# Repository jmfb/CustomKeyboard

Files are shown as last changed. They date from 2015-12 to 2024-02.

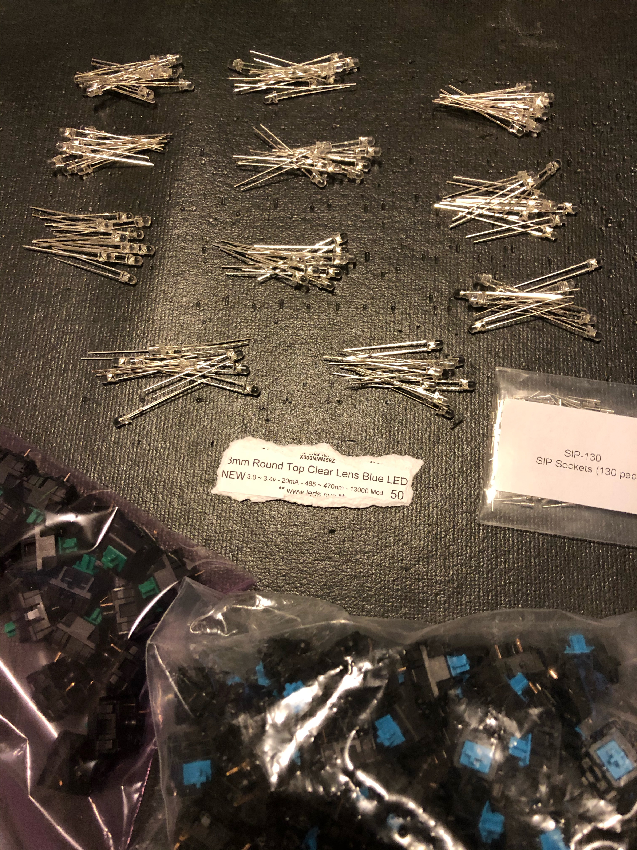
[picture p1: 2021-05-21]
Images/V5/01_LedSipKeys/00_Materials.jpeg

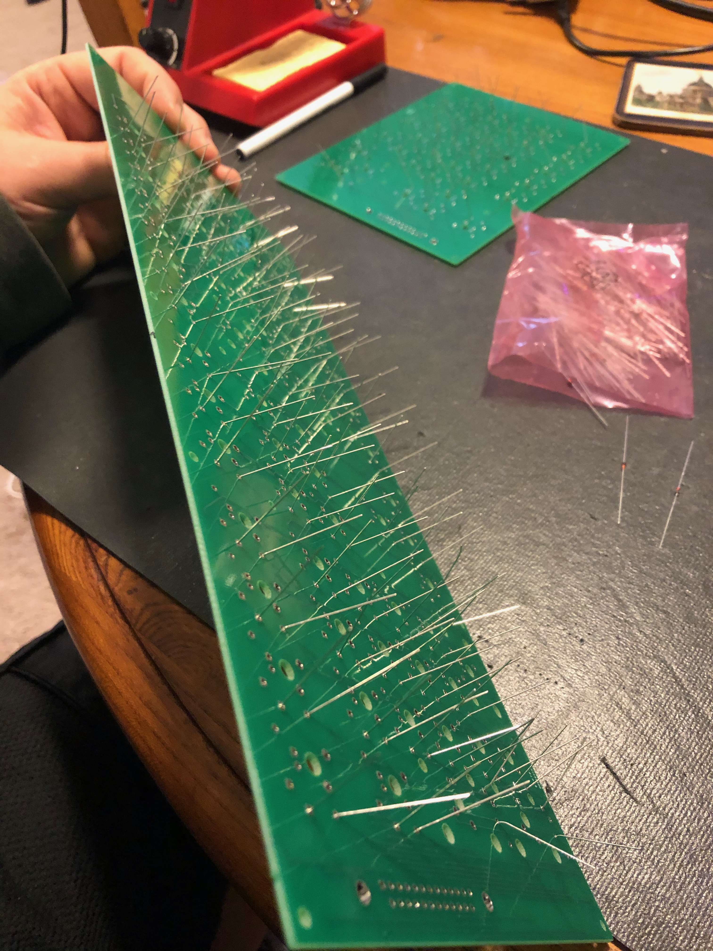
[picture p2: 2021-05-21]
Images/V5/02_DiodesAndResistors/04_RightHandBack.jpeg

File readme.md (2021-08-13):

# Custom Keyboards

## V1

I took a prefabricated tenkeyless PCB and used a dremel to cut it into 3 pieces:
- Left hand board (jagged cut at F5, 6, T, G, B)
- Right hand board (jagged cut at F6, 7, Y, H, N)
- Arrow keys

I proceeded to use the dremel to sever all PCB traces for the keys but left the diode traces.
Cherry MX brown switches were then directly mounted to the PCB.  Note that these switches were
the ones designed to be plate mounted (did not include the extra two plastic pegs for direct PCB mounting) so the keys ended up looking crooked.

The switches were then wired into the standard row/column matrix and wires were all routed through to an external Teensy2.0 controller.  2x5 and 2x3 headers were used for the connecting cables.  The keycaps were a standard profile blank set.

The next phase was designing a custom PCB for the number pad (to "complete" the full keyboard) and testing out both 3D printed and lasercut mounting plates.

### Lessons Learned

- Direct PCB mounting was crooked (at least using the non-PCB mount keys).
- Lasercut acrylic mounting plates were sturdier, cheaper, and looked cooler than the 3D printed versions.
- Arrow keys and number pad could be combined into a single board.
- Blank keycaps were difficult to use (I guess I still occasionally look).
- The placement of the right hand spacebar required the right thumb to tuck.
- The external controller for the Teensy and the external cable management boards made for too many components.
- The keys come with holes for LEDs that I might as well be using.
- A wristpad was necessary to use the keyboard and would nice if it were affixed.

## V2

I designed 3 custom PCBs using KiCad:
- Left hand board (capslock key replaced with Teensy2.0 controller)
- Right hand board
- Accessory board (arrows and numbpad)

I designed lasercut mounting plates using OpenSCAD.

I upgraded to using Cherry MX blue switches and double shot DCS keycaps and installed green LEDs on each key.

I extended the base plate to make room to glue wristpads onto the boards.

### Lessons Learned

- Direct soldering of the LEDs to the PCB made it difficult to replace them when they loosened or burned out.
- The double shot keycaps felt great but didn't allow for the LED light to show through.  Translucent keycaps would have been better.
- A better solution than just gluing the PCB to a board would be needed for a case (someting that could be assembled/disassembled, and that had walls).

## V3

This design used the same PCBs and mounting plates as V2.

Cherry MX green switches were used.  After using a sampler board with several types of switches I thought the ultra stiff key would be awesome.

Lasercut faceplates, lasercut baseplates, and 3D printed case walls were designed using OpenSCAD.  Three versions of the case walls were printed to test out different materials and different 3D printing vendors: i.Materialise, Sculpteo, and Shapeways.

SIP LED sockets were put into each of the key switches to allow for the LEDs to be replaced.  A mix of blue and green LEDs were used (blue for control keys).

Doubleshot translucent keycaps were used to allow for the LED light to show through.

The controller logic was updated to make the left hand space be a hyper key.

### Lessons Learned

- The 3D walls designed for the case were too tight of a fit and bowed out.  It made for a sturdy design but required too precise measurements for a perfect fit.  The next case should use screws/standoffs to mount the PCB vs. grooved walls.
- 3D printing was too expensive and slow compared to laser cutting.  The next case should be made solely from lasercut parts.
- The hyper key functionality was great, but I occassionally missed having the left hand spacebar.  More keys next time.
- The 2x5/2x3 connector cables looked unprofessional (probably because of the rainbow colored cables).
- I measured the baseplates based on the previous wristpad size and when I couldn't reorder the same type of wristpad had to use bigger ones that hung over the edge of the baseplates.  Obtain wristpads prior to measuring baseplates.
- The cutoff edge of the wristpads looked unprofessional.
- After double checking the PCB and laser cutting capabilities there is no need to keep the accessory board separate.
- Stabilizers for the 2+ keys would be nice.  Need to update PCB for holes, mounting plates for holes, and move PCB components in the way of the footprints.
- Not sure how I feel about the green switches.  I like the stiff feel but I don't think I love them like I did the blues.
- The LEDs were mounted on the bottom of the keys but the translucent keycaps were designed to shine through the top.  Will need to flip key switches to optimize translucent effects of the keycaps.  Note that vertical keys should have LEDs to the left.
- The key spacing for larger unit keys (1.25, 1.5, 1.75, 2, 2.25, and 2.75) had been using measured positions and worked.  However, when attempting to make a perfect rectangle for each hand it was discovered that 19mm * keysize was needed to prevent 1mm error for several rows.  This increased resolution for key spacing to 1/8th mm from 1/2 mm.

## V4

3 new PCBs were designed using KiCad:
- Extended left hand board (include arrow keys and slightly inverted numpad to mirror right hand board).
- Extended right hand board (combined right hand board and accessory board).
- External connector board (houses Teensy and 2 25-pin D-sub connectors).

The left hand board had arrow keys added to the left of the previous left edge.  A numpad was added to the left of that but with the outside edge of keys mirrored and the zero and period flipped.  The mirroring was so the enter would still be hit with the pinky and the zero still with the thumb.  The numbers were not flipped because I didn't want to retrain my brain for my left hand.  Above the numpad, four programmable buttons were added (N1-4, sometimes used for volume controls or extended operators for the numpad).  To the left of the numpad a vertical row of programmable buttons was added (M1-6, as part of the more keys strategy) that used some of the gaps in the row/column matrix.  To the right of the jagged edge, a vertical row of programmable keys was added (L1-6) and different sized keys were used to make the board a perfect rectangle.  A new hyper key (LEFT_HYPER) was also added to the left of the spacebar to fill in the gap between alt and the spacebar.  The capslock key was re-added since the Teensy is being moved onto its own board (whether this gets remapped is programmable).  The main part of this board is 8.5 standard keys wide.

The right hand board was combined with the previous accessory board.  The same jagged gap was filled on this board to make it a perfect rectangle though one more key was added (two keys were added to the left of the function key row) for an additional 7 keys (R1-7).  A new hyper key was added to the right of the spacebar (RIGHT_HYPER) and the right windows key was re-added (previously just had the right menu key between alt and ctrl).  The same N1-4 and M1-6 keys were also added to this board (note they are not independently programmable because they map to the same row/column scan position).  The main part of this board is 10 standard keys wide.

The full keyboard contains 170 keys; 130 distinct row/column scan positions.  Note that there are still 2 unused row/scan positions in the 12x11 row/scan matrix.  There wasn't anywhere convenient left to put them though.

A single 25-pin D-sub connector exists on each board. 12 row pins, 11 column pins, VCC, and GND (for LEDs).  Instead of chaining the left board to the right board and having the USB cable and connector cable on the left board, the Teensy was moved off onto a controller board.  The controller board just maps the Teensy pins to 2 D-sub connectors (one for the left hand board and one for the right hand board, with both cables having the same pin assignments).

The case design was switched to use all lasercut pieces.  The walls are notched together and slide pegs into the baseplate and faceplate.  A 3mm overhang, 3mm wall depth, and 1mm spacing between wall and PCB makes each dimension of the base/face 14mm longer than the PCB/mounting plate sizes.  Screw holes are drilled into the border and one near the arrow keys for some center support.  M2 screws (5mm male end), 0.5mm washers, 5mm M/F standoffs (3mm wide with 4mm male end), and 8mm F/F standoffs (3mm wide) are used to affix the PCB to the base and affix the faceplate to the walls.  From the bottom, it goes: screw, base, 5mm M/F standoff, PCB, washer, 8mm F/F standoff (though hole for mounting plate), 2 washers, faceplate, washer, screw.

All case parts for all three boards can be combined into a single CAD file and lasercut from two P3 pieces from Ponoko (one for the baseplates and walls and one for the mounting plates and faceplates).  Since there was space for two connector faceplates, I decided to make one with a little bit of artwork and cut out a flux capacitor.  Because if you're going to build your own keyboard why not build one with style!

Cherry PCB mounted stabilizers were added.  Two sets of translucent keycaps were needs due to the number of additional keys.

### Lessons Learned

- D-Sub connector height measurement was imprecise and pushed the faceplate up about 1mm.  Filing it down took part of the edge off, but using a micrometer will yield better wall/faceplate height measurements.
- Using the washers on the screw/standoff connections was impractical due to the small size of the washers, the inconvenient location of the screws (near walls or central to the board and under the mounting plate).  The screw/standoff premise is solid though and made a very sturdy and professional looking case.
- The location of the D-Sub connectors on the boards was inconvenient for placement near monitors.  I think the outside edge would make the most sense for the next version.
- More keys was a bad idea.  The inner row keys ended up getting pressed by accident too often and ruined the tactile feel for finding my position on the keyboard without looking.  While there was potential for adding useful keys (left hand enter, backspace, right hand tab, escape) the opposite was experienced.  The extra left hand board made it difficult to find home for my left hand (naturally always seeking leftmost position).  The extra numpad and outer macro keys filled out the keyboard but were too out of the way to add anything useful to them (it was more burdensome to try to figure out what to assign to the keys).  I am not sure about how I feel about the hyper key near the spacebar because of the other things that made typing difficult.  I do still think a hyperkey or two is a good idea.
- The offboard teensy and extra cabling has the benefit of keeping a single cable going to each board but uncovered a problem with wiring resistance that was solved with a delay in the controller logic during rowscan to allow the signals in the lines to stabilize (which was taking at least one extra clock cycle and causing phantom keypresses in the first two columns of the scan matrix).
- I didn't glue down the wristpad on this one because I was tired of buying more and more wristpads.  However, they slip around too much otherwise.  They need to be fixed to the keyboard case.  Sewing the edge flap down did make them look much better than the glued end of cut off end.
- I think the Cherry MX Green switches were cool for a while but in the end not as nice to type on.  Going back to the blue switches from V2 felt amazingly good by comparison.
- The mix of blue and green LEDs was kind of cool but I don't love it.  I think short of RGB LEDs I will stick with a single color.  Probably green but blue was fine too.  The SIP sockets rock.
- Having the CapsLock key back was a mistake - definitely never use it and every time it is pressed was an accidental hit.  I might leave it off next time.  Would the overall look suffer though?
- The flux capacitor design in the connector board was basically invisible because of the clear faceplate.  However, the top leg did provide a hole through to the teensy reset button which came in handy.  Might just keep that hole.
- The cherry stabilizers worked out great.  Clean fit into PCB, perfect cutout for mounting plate.  There was one resistor that was close to a support bar.
- Pro-tip: prior to soldering the keys onto the PCB make sure all key pins went through.  One pin had bent down and I didn't discover it until half of the keys were soldered.  That meant I was almost fucked.  I ended up shoving a bit of wire through the hole and drenching it in solder hoping that surface tension would pull enough solder down the wire to make the connection to the bent pin.  It worked, but had it not I don't know what I would have done.
- A few more screws in certain locations would make the faceplate more stable (at least on the right hand board).

## V5

### Left Hand

- Getting rid of left hand accessory board (arrows and numpad).
- Getting rid of outside column macro keys (M1-6) and inside column macro keys (L1-6).
- Removing the caps lock key.  Could have left it for looks and mapped it to a hyper key or something, but not worth the mistakes.
- Keeping the left hyper key.
- Moving D-Sub connector to left edge at the top.
- Using a total of 7 screw holes to build case.
- Total of 35 keys (2 2+ keys) with max row width being 7.5 keys (bottom row).

### Right Hand

- Getting rid of outside column macro keys (M1-6) and inside column macro keys (R1-7).
- Keeping numpad macro keys (N1-4).
- Keeping right hyper key and right windows key.
- Moving D-Sub connector to right edge at the top.
- Using a total of 15 screw holes to build case.
- Total of 75 keys (7 2+ keys) with max row width being 9 keys (bottom row, excluding accessory keys).

### Connector Board

- Reusing design from V4.  Will be able to use the same PCB.
- Leaving a hole in the faceplate for the Teensy reset button.
- Using a total of 4 screw holes to build case.

### General Updates

- Fixing case wall height to take into account micrometer measurements for D-Sub connectors (10.3mm vs. previous measurement of 9.5mm).
- Using 10mm F/F standoffs to connect PCB to faceplate (a 0.3mm gap will exist, should be fine).
- Not using washers in any part of screw assembly (too small and can't get in most spots).
- Using same color LED for all keys (green).
- Going back to Cherry MX Blue switches.
- Plan on getting custom DCS row 6 keycaps for hyper keys (left is 1.5, right is 1.75) and space keys (both 2.25).

### Lessons Learned

- This keyboard is just plain awesome.
- Right hand board is still very large and is sometimes awkward to fit onto desk near monitors.
- Large right hand board occasionally gets wobble when crossing desk boundaries.
- Very minor use of hyper keys due to completely normal keyboard layout.
- N1-4 keys are never used (and completely out of the way).
- Uses 3 2.25 keys (left shift and both spacebars) which makes complete keycap sets difficult.
- Using unused capslock as right hyper is perfect.
- Still do not miss the capslock key (nor do I wish there were a key there I could hit).
- Single color keyboard is okay (looks neat but not awesome).  Have built both a green and blue version.
- Ran out of blue switches for second one and used green for function keys - don't even notice because of how rarely they are used.
- D-sub cables give a classic/punk look to the keyboard but are a bit large (bump into monitors still, even on the outside top).
- Cost for materials (case/PCB) is higher than ideal due to large right hand board.
- Connector board is larger than it needs to be.

## Mini V1

### Goals

- Build a miniature keyboard (40%-like) and use hyper-functionality to improve current coding workflows.
- Have an easy to hit underscore (for snake casing, lambdas, garbage identifier prefixes, etc.).
- Reduce PCB/case material costs (just in case I want two of them again!).
- Have smaller and more hidden cables connecting the boards (keep off-board controller for symmetry).
- Columnar layout (will definitely need to re-learn typing).
- Minimal "reach" keys (1 row up, 1 row down, 1 row over to either side).
- Rely on thumb buttons for extra keys (no clue what layout yet).
- RGB LEDs so I can have that awesome feel of dynamic color and responsive changes.

### Parts, Prices, and Datasheets

- Cherry MX Blue RGB PCB Mount Switches (x23 x2)
	- MX1A-EN1B (NOTE: Only wanted MX1A-EN1A, plate mounted, but were constantly out of stock)
	- [Blue Datasheet](https://www.cherrymx.de/_Resources/Persistent/a531cb6598bc849cbcf131fd7a31814282b74545/EN_CHERRY_MX_BLUE.pdf)
	- [Footprint Datasheet](https://cdn.sparkfun.com/datasheets/Components/Switches/MX%20Series.pdf)
	- [LED Cutout Datasheet](https://drive.google.com/file/d/0B5JcED9YINdnNU1qajJmVmtEcUU/view?resourcekey=0-LZfcyjo3jcX8JEKJD6tRKA)
	- [MechanicalKeyboards](https://mechanicalkeyboards.com/shop/index.php?l=product_detail&p=4451)
	- $0.50 / switch @ 100 = $50.00 (bulk discount)
- Pin Receptacle Connector (Maybe, adds height to key and might throw off 3mm spacing between PCB and mounting plate)
	- 0305-2-15-15-47-27-10-0 (ED90333-ND)
	- [Datasheet](https://www.mill-max.com/products/datasheet/pinsrecs/0305-2-15-80-47-80-10-0)
	- [Digikey](https://www.digikey.com/en/products/detail/mill-max-manufacturing-corp/0305-2-15-15-47-27-10-0/1801940)
	- $0.22906 / connector @ 200 = $45.81 (bulk discount, went in on 500 with Greg).
- Keyswitch Diode (x23 x2)
	- 1N4148 (1N4148FS-ND)
	- [Datasheet](https://rocelec.widen.net/view/pdf/bhc41r7lwc/ONSM-S-A0003539415-1.pdf?t.download=true&u=5oefqw)
	- [Digikey](https://www.digikey.com/en/products/detail/on-semiconductor/1N4148/458603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)
	- $0.01622 / diode @ 1000 = $16.22 (bulk discount)
- RGB LED with IC (x23 x2)
	- APA102C (iPixel LED)
	- [Datasheet](https://cdn.sparkfun.com/datasheets/Components/LED/APA102C.pdf)
	- [Sparkfun](https://www.sparkfun.com/products/16345)
	- $0.379 / LED @ 50 = $18.95
- 9pin Mini-DIM Female Connector, Through Hole, Right Angle (x1 x2 + connector x2)
	- MD-90S (CP-2490-ND)
	- [Datasheet](https://www.cuidevices.com/product/resource/md-s.pdf)
	- [Digikey](https://www.digikey.com/en/products/detail/cui-devices/MD-90S/145320)
	- $2.95 / connector @ 4 = $10.80
- 9pin Mini-DIM Male/Make 3ft. Cable (x2)
	- MD9MM3BLK
	- [Datasheet](https://www.kraydad.com/mini-din-9-pin-b-type-cables/)
	- [Kraydad](https://www.kraydad.com/mini-din-9-pin-b-type-3-ft-male-to-male-black-cable/)
	- $12.49 / cable @ 2 = $24.98
- Cherry PCB Snap-in Stabilizers (2u x2 x2)
	- 60%/TKL (NOTE: includes 5 2u wires, only need 4)
	- [Amazon](https://www.amazon.com/Genuine-Cherry-PCB-Snap-Stabilizers/dp/B085T8QZJC)
	- $14.99 / pack @ 1 = $14.99
- M4 Hex Brass F/M Standoff 18mm/6mm w/ Screw and Nut (x4 x2)
	- Set of 20 (need 4 or 5 per board)
	- [Amazon](https://www.amazon.com/gp/product/B08ZXSR7MP)
	- $0.5745 / set @ 20 = $11.49
- M4 Brass Washer 9mm OD, 4.3mm ID, 0.8mm Thick (x4 x2)
	- Pack of 100 (need 4 or 5 per board)
	- [Amazon](https://www.amazon.com/gp/product/B009OK2KPU)
	- $0.0827 / washer @ 100 = $8.27
- M2 Brass F/M Standoff 5mm/4mm
	- Pack of 100 (need 4 for controller)
	- [Amazon](https://www.amazon.com/gp/product/B00REFG0TE/ref=ppx_yo_dt_b_search_asin_title?ie=UTF8&psc=1)
	- $0.0949 / standoff @ 100 = $9.49
- M2 Brass F/F Standoff 8mm (first controller)
	- Pack of 50 (need 4 for controller)
	- [Amazon](https://www.amazon.com/gp/product/B00BWLQYRY/ref=ppx_yo_dt_b_search_asin_title?ie=UTF8&psc=1)
	- $0.226 / standoff @ 50 = $11.30
- M2 Brass F/F Standoff 10mm (second controller)
	- Pack of 100 (need 4 for controller)
	- [Rakuten](https://www.rakuten.com/shop/unique-bargains/product/a14081400ux0120/)
	- $0.0683 / standoff @ 100 = $6.83
- M2 5mm Screws
	- Pack of 60 (need 8 for controller)
	- [Amazon](https://www.amazon.com/gp/product/B013T1U4LG/ref=ppx_yo_dt_b_search_asin_title?ie=UTF8&psc=1)
	- $0.1195 / screw @ 60 = $7.17
- Clear Soft Close Drawer Cabinet Door Bumpers (x6 x2 + connector x4)
	- 9.5mm x 3.8mm, 72pc sheet
	- [Amazon](https://www.amazon.com/dp/B06XCGM8JT)
	- $0.0968 / bumper @ 72 = $6.97
- Mini USB A to Mini-B Cable, Black, 3ft (x1)
	- 103896 (any Mini USB cable will do if you already have one)
	- [Amazon](https://www.amazon.com/Monoprice-3-Feet-mini-B-28AWG-103896/dp/B003L18SHC)
	- $5.23 / cable @ 1 = $5.23
- Teensy 2.0 (x1)
	- No pins
	- [Datasheet](https://www.pjrc.com/store/teensy.html)
	- [Amazon](https://www.amazon.com/gp/product/B00NC43256)
	- $18.75 / chip @ 1 = $18.75 ($16 from PJRC but with shipping)
	- NOTE: Plans to discontinue this model in 2022; recommend switching to 32-bit boards.
- Header Pins (x12 x2, though more pins available on Teensy)
	- Breakaway header, straight, brass
	- [Sparkfun](https://www.sparkfun.com/products/116)
	- $1.50 / 40pin strip @ 1 = $1.50
	- NOTE: Larger volumes and lower per-pin cost are on amazon but not brass pins
- Demultiplexer, 3:8 (x1 x2)
	- SN74HC138N (296-1575-5-ND)
	- [Datasheet](https://www.ti.com/lit/ds/scls107f/scls107f.pdf)
	- [Digikey](https://www.digikey.com/en/products/detail/texas-instruments/SN74HC138N/277221)
	- $0.461 / chip @ 10 = $4.61 (bulk discount)
- Parallel Load, Shift Register (x1 x2)
	- SN74HC165N (296-8251-5-ND)
	- [Datasheet](https://www.ti.com/lit/ds/symlink/sn74hc165.pdf)
	- [Digikey](https://www.digikey.com/en/products/detail/texas-instruments/SN74HC165N/376966)
	- $0.525 / chip @ 10 = $5.25 (bulk discount)
- 10kOhm Pullup Resistors (x8 x2)
	- CF18JT10K0 (CF18JT10K0CT-ND - Cut Tape (CT))
	- [Datasheet](https://www.seielect.com/catalog/sei-cf_cfm.pdf)
	- [Digikey](https://www.digikey.com/en/products/detail/stackpole-electronics-inc/CF18JT10K0/1741566)
	- $0.01116 / resistor @ 500 = $5.58 (bulk discount)
- Wristpad (x1 x2, but both cut from 1)
	- Glorious Gaming Write Pad, Standard Size
	- [Amazon](https://www.amazon.com/Glorious-Gaming-Wrist-Pad-Rest/dp/B00V5AXPTW)
	- $26.99 / pad @ 1 = $26.99
- Doubleshot Translucent Pudding Keycaps (x15 x2)
	- Standard Set
	- [Amazon](https://www.amazon.com/gp/product/B09241HV9H)
	- $19.99 / set @ 1 = $19.99
- DCS Clear Keycaps (x8 x2)
	- 1u R2 x2, 1u R3 x2, 1u R4 x8, 2u R3/4 x4
	- [Datasheet](https://pimpmykeyboard.com/template/images/DCSFamily.pdf)
	- [PimpMyKeyboard](https://pimpmykeyboard.com/dcs-clear-keys-and-key-sets/)
	- $1.00 / 1u @ 12 = $12.00
	- $1.50 / 2u @ 4 = $6.00
- Laser Cut Parts
	- [Ponoko](https://www.ponoko.com)
	- All 3mm parts are Green Translucent Acrylic
	- All 1.5mm parts are Clear Acrylic (not available in Green Translucent)
	- Controller (3mm) $7.69 @ 1 = $7.69
	- Base Plate (3mm) $7.15 @ 2 = $14.30
	- Mounting Plate (1.5mm) $7.71 @ 2 = $15.42
	- Lower Layer (3mm) $5.965 @ 4 = $23.86
	- Upper Layer (3mm) $6.08 @ 2 = $12.16
	- Face Plate (3mm) $3.855 @ 4 = $15.42
	- Face Plate (1.5mm) $2.815 @ 2 = $5.63
	- Multi-product discount $30.91
	- Setup Fee $14.00
	- Total: $77.57
- PCB
	- [Seeed Studio](https://www.seeedstudio.com)
	- Controller $0.98 @ 5 = $4.90
	- Left Hand $6.486 @ 5 = $32.43
	- Right Hand $6.486 @ 5 = $32.43
	- Shipping (DHL from China) $30.19
	- Total: $19.99 @ 5 = $99.95
- Total cost of parts for a single keyboard: $313.34

### Lessons Learned

- Fitting 5x5mm LEDs not a perfect fit (could have made a tad wider for flush fit; would also fit rounded PCB cut corner issue too)
- Soldering LEDs difficult.  Not sure what to do about this other than magnifying glass w/ light.
- Chaining VCC/GND may have been a poor choice, still not sure.  Definitely problematic when attempting to remove an LED.
- Socketing switches seems like a good idea (reduce switch cost for multiple prototypes, allow replacing switches in long-lived versions).  However, increases distance between mounting plate and PCB by ~1mm.  I think I can take that out on pegs.
- With the surface mount pegs, the mounting plate does seem a little bit redundant.  Eliminating the mounting plate and the 1.5mm faceplate layer would reduce overall height by 3mm (shorter M4 scews) and allow for a completely 3mm layer construction.
- Controller board; teensy height from PCB is slightly greater than the 8mm F/F standoffs (not sure how I missed that).  Damn, old controller used 10mm F/F standoff.
- Well, it puts the previous lessons to shame, but the controller "lid" didn't go deep enough with the connector cutouts!  Missed "PCB spacing, wall depth, overhang" padding and just did connector size.
- Tab being lower for the pinky takes getting used to (hit escape a lot).
- Only using bottom half of 2-keys.  Possibly simplify down to 1u size?
- Sometimes hit Win instead of Ctrl when reaching with thumb.  Could stagger keys for thumb; possibly get rid of one of grid keys and just have left hand Win and right hand Menu (or no Menu, I mean who uses that key?)
- Had a few iterations of controller software.  Unit tests for expected key reports were vital (lots of bugs found that way and prevent breaking changes in the future).

## Mini V2

### Goals

- Fix LED hole size to make assembly and soldering easier.
	- Move cutout to keyswitch footprint (manually in file if IDE does not support it).
	- Increase width of cutout to allow surface mount leads to fit inside PCB.
	- Also increase width of peg cutout to account for rounded PCB cutout.
- Fix all incorrect case measurements.
	- 10mm standoffs for controller top.
	- Fix controller lid cutouts for connectors.
	- Reduce peg inner height by 1mm to account for keyswitch sockets.
	- Adjust connector cutout (rubs on bottom).
	- Add holes for demux and register to mounting plate.
- Add hardware support for right or left hand detection.
	- Hardwire first two register pins to 01 for left and 10 for right.  11 indicates disconnected.
	- Software detection to read keyscan and switch LED output.

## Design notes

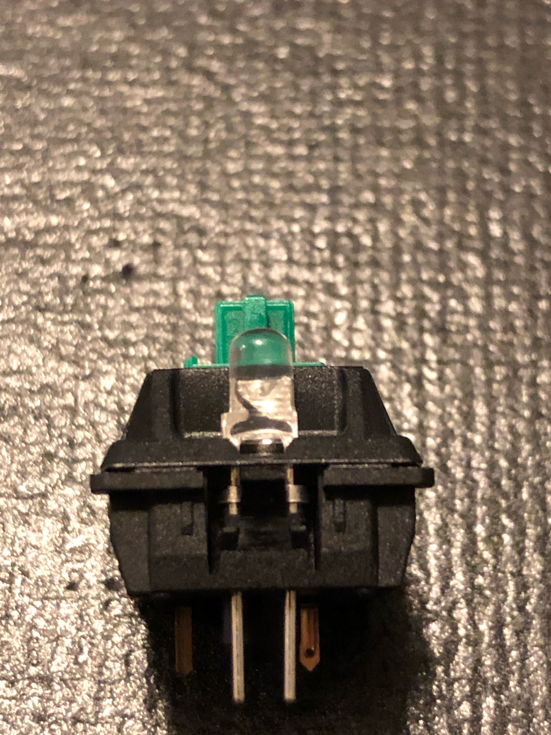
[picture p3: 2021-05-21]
Images/V5/01_LedSipKeys/07_InsertLed.jpeg

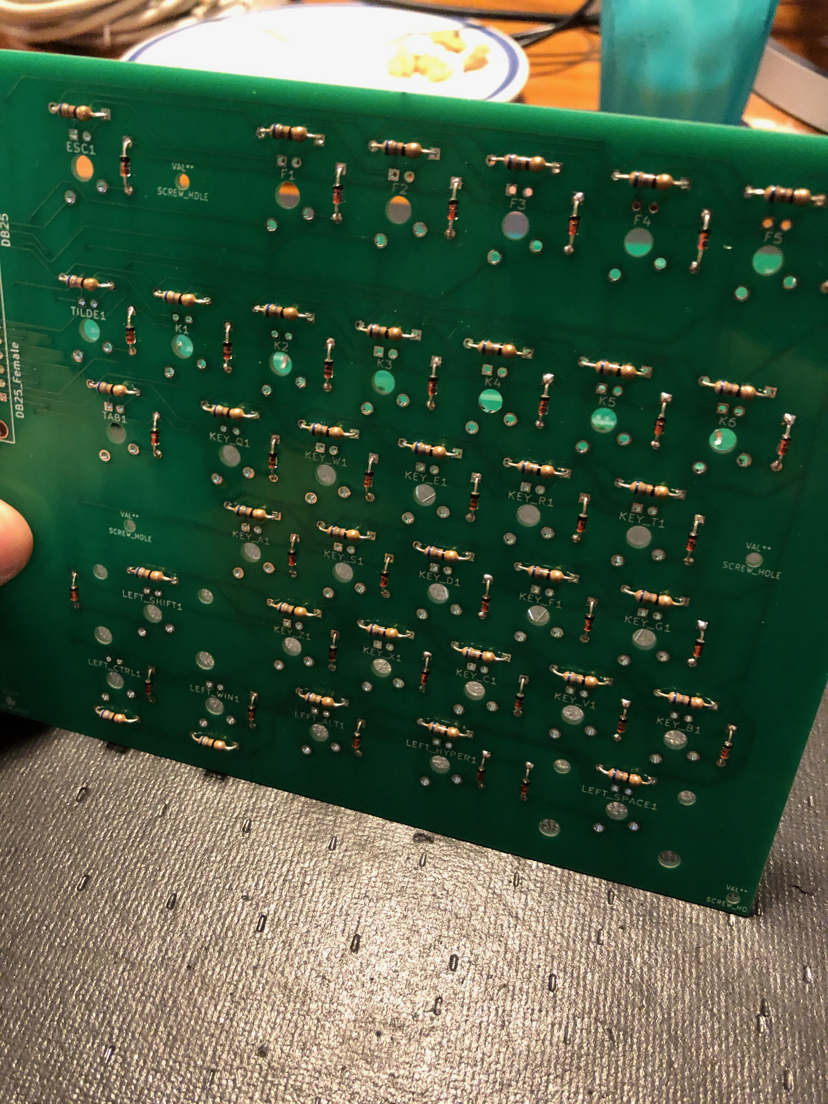
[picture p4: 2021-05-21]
Images/V5/02_DiodesAndResistors/05_LeftHandResistors.jpeg

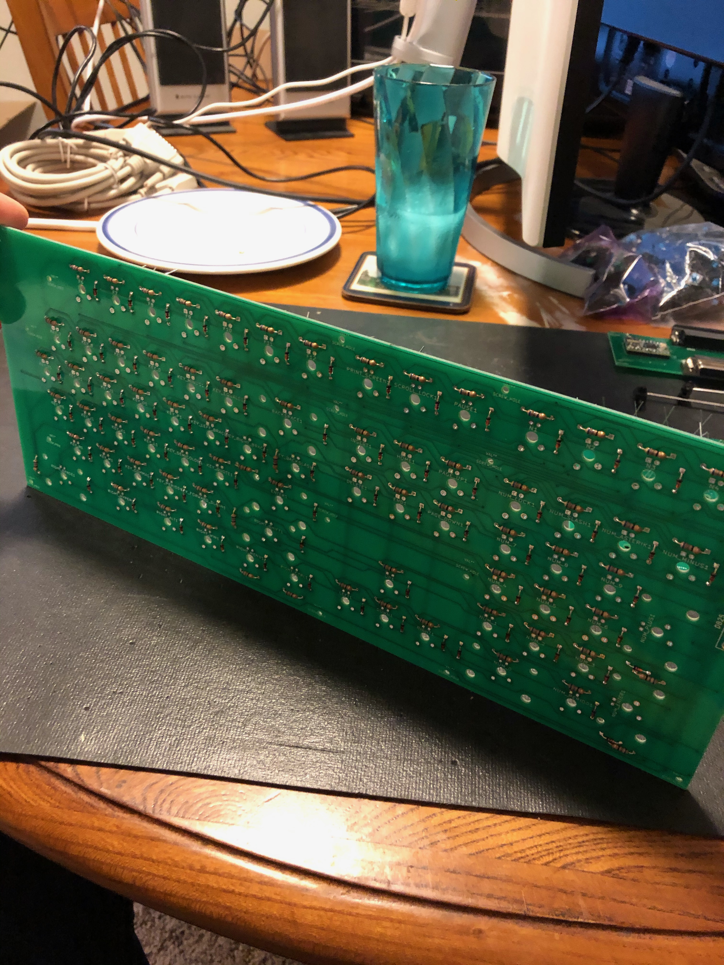
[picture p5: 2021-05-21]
Images/V5/02_DiodesAndResistors/07_RightHandResistors.jpeg

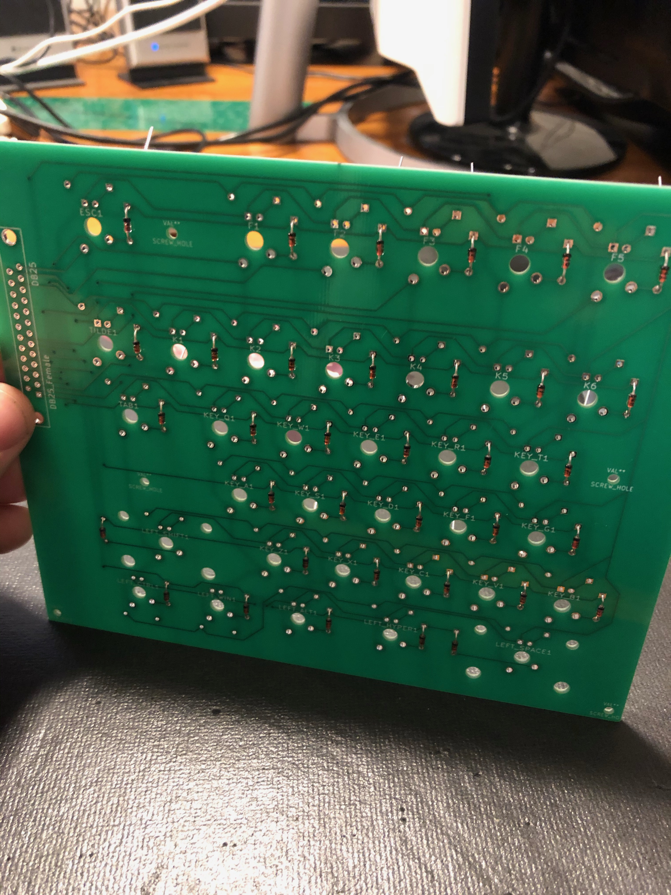
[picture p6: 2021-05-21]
Images/V5/02_DiodesAndResistors/01_LeftHandDiodes.jpeg

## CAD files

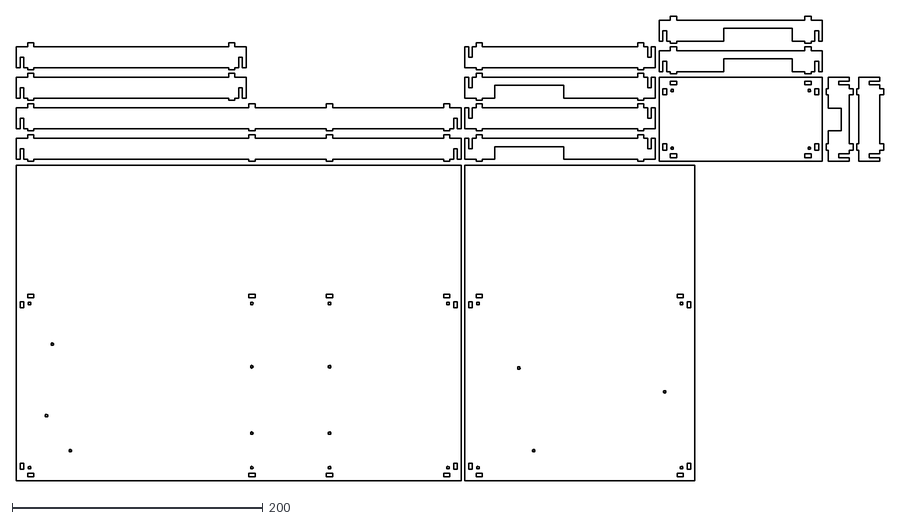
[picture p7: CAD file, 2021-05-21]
BasePlates/V5.dxf
692.3 x 370.8

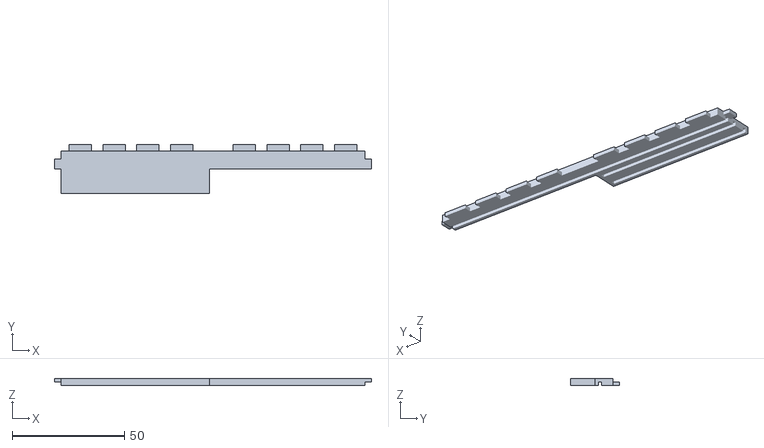
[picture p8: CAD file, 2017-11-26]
Case/RightHandAndAccessoryLeft.stl
141.0 x 22.0 x 3.00

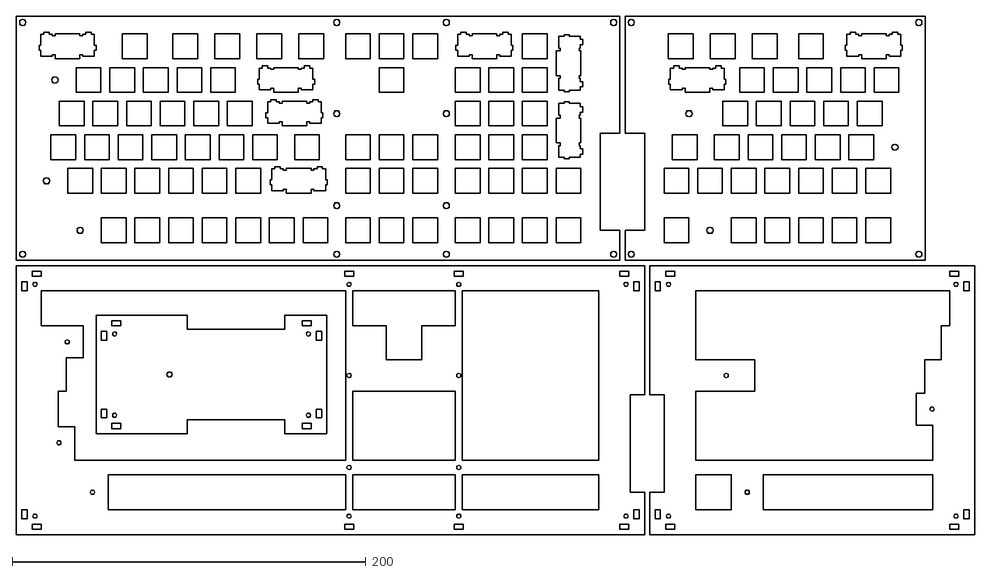
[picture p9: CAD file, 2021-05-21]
FacePlates/V5.dxf
541.5 x 293.0

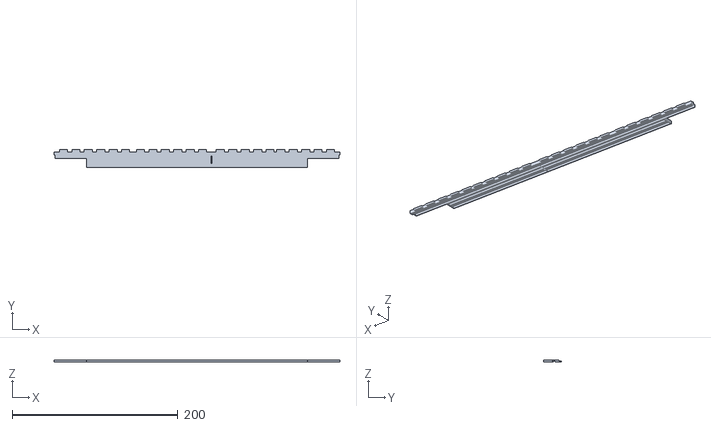
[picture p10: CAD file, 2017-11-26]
Case/RightHandAndAccessoryTop.stl
345.5 x 22.0 x 3.00

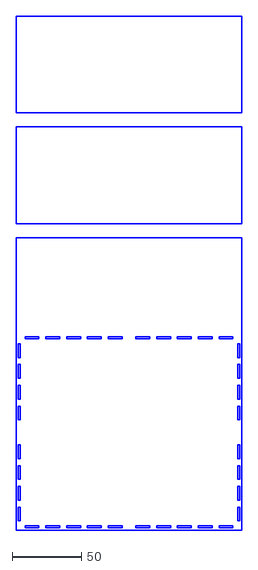
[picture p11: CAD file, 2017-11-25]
BasePlates/LeftHand.v2.dxf
163.0 x 371.0

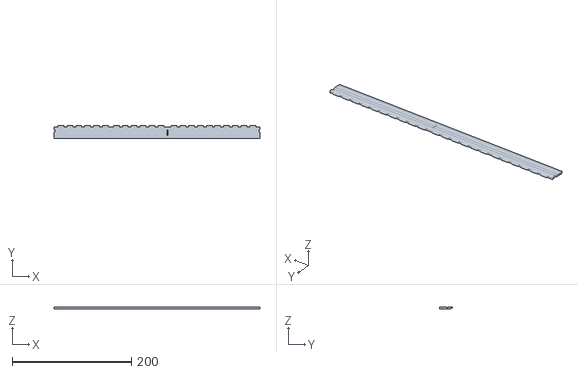
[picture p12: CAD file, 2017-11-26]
Case/RightHandAndAccessoryBottom.stl
345.5 x 22.0 x 3.00

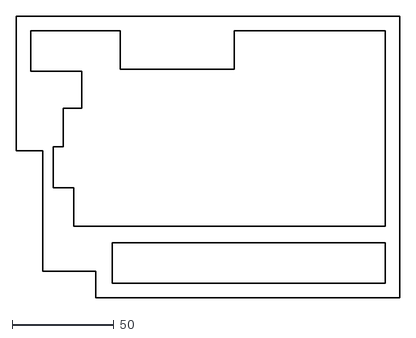
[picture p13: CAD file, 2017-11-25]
FacePlates/RightHand.dxf
188.0 x 138.0

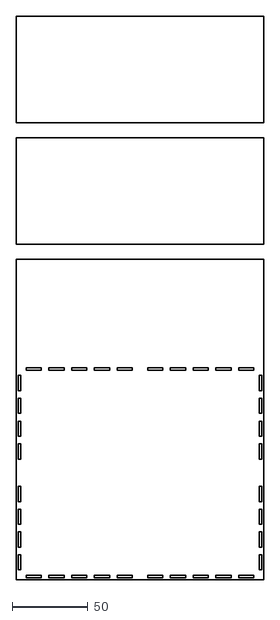
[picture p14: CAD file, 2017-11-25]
BasePlates/LeftHand.dxf
163.0 x 371.0

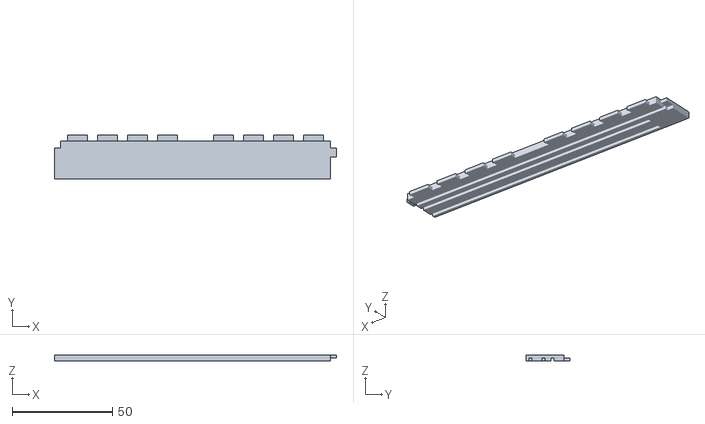
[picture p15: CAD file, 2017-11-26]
Case/RightHandAndAccessoryRight.stl
141.0 x 22.0 x 3.00

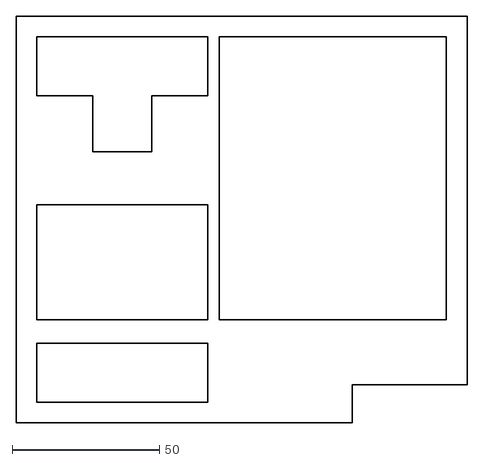
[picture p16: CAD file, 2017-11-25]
FacePlates/Accessory.dxf
153.0 x 138.0

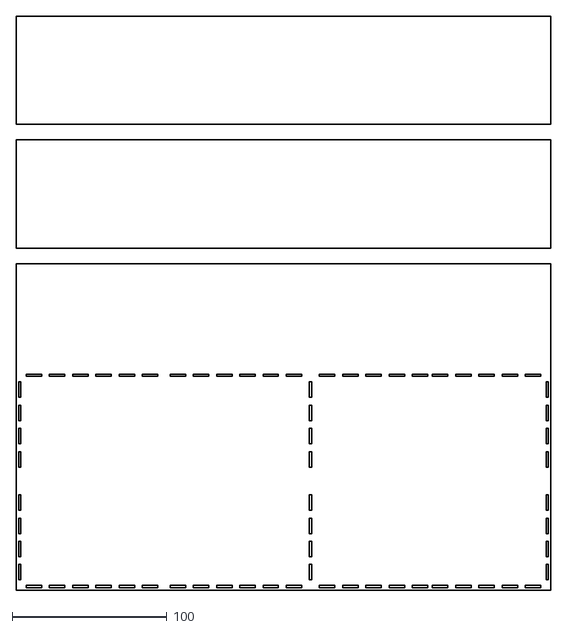
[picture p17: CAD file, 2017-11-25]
BasePlates/RightHandAndAccessory.dxf
345.5 x 371.0

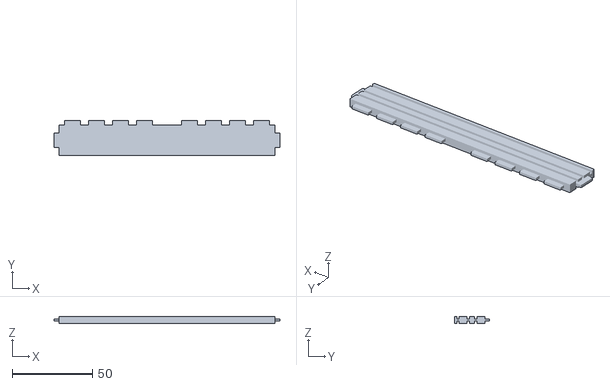
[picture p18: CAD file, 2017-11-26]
Case/RightHandAndAccessoryMiddle.stl
141.0 x 22.0 x 4.50

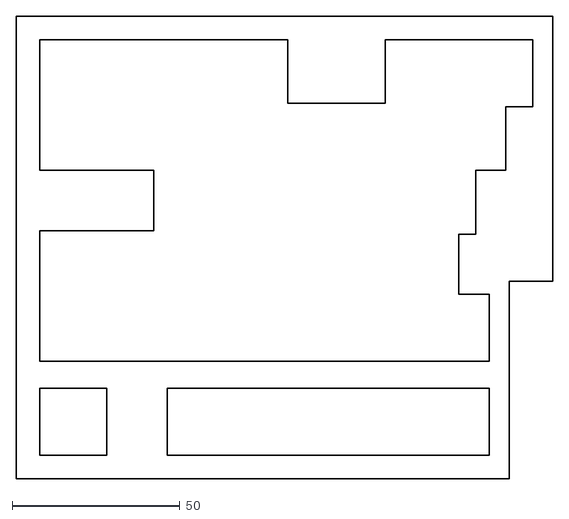
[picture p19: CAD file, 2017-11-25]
FacePlates/LeftHand.dxf
160.0 x 138.0

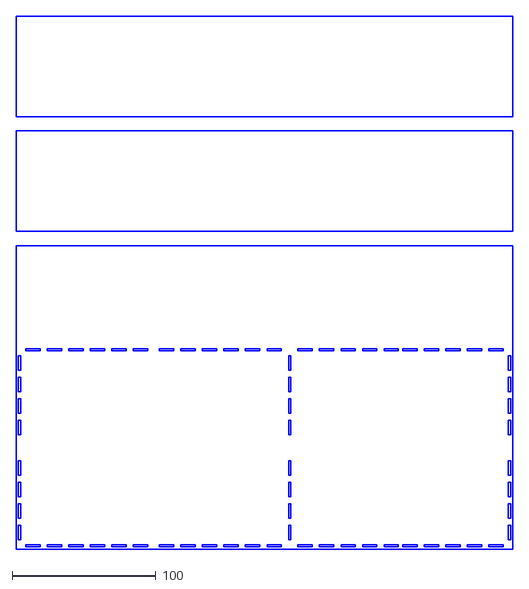
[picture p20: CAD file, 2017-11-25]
BasePlates/RightHandAndAccessory.v2.dxf
345.5 x 371.0

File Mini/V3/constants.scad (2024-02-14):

keySize = 19;				// Size of a keyswitch (a perfect square)
halfKeySize = keySize / 2;	// Distance from center of keyswitch to each side
keyHoleSize = 14;			// Size of a keyswitch mounting hole (a perfect square)
epsilon = 0.1;				// Small value used to get around OpenScad difference issues

pcbDepth = 1.6;				// Thickness of the PCB (average measured value)
modelWallDepth = 1.5;		// Thickness of the vertical walls of the model
mountingPlateDepth = 1.5;	// Thickness of the mounting plate layer (needed for keys to click in place)

keyPcbWallSpacing = 0.5;	// Total gap between PCB and mounting walls (half on each side)
keyPcbXOffset = (modelWallDepth + keyPcbWallSpacing) / 2;	// Offset in x-direction for PCB
keyPcbWidth = keySize - modelWallDepth - keyPcbWallSpacing;	// Width of a key PCB baord
keyPcbHeight = keySize;		// Height of a key PCB board (normal keysize)

pcbMountSpacing = 4;	// Measured distance between bottom of mounting plate and top of PCB
mountingHoleOffset = (keySize - keyHoleSize) / 2;	// Distinct from the edge of a mounting plate location to the edge of the hole

lowerRowAngle = atan2(3, 4);	// Angle of row below home row (empirically determined)
upperRowAngle = atan2(6, 11);	// Angle of row above home row (empirically determined)

pcbBottomSpaceUnderHome = 4;		// Distance below home row PCB before bend
pcbBottomSpaceAboveHome = 3;		// Distance above home row PCB before bend
pcbBottomSpaceAfterLowerBend = 7;	// Distance after lower bend before bottom row PCB
pcbBottomSpaceAfterUpperBend = 5;	// Distance after upper bend before upper row PCB

// Offsets of fingers on home row relative to index finger
middleYOffset = 4;	// Vertical shift of middle finger
ringYOffset = 0;	// None
pinkyYOffset = -4;	// Vertical shift of pinky finger
middleZOffset = -1;	// Z-offset of middle finger
ringZOffset = -2;	// Z-offset of ring finger
pinkyZOffset = 6;	// Z-offset of pinky finger

// Extensions of mounting plate to meet at home row bends
distanceToMountingPlateBottom = pcbMountSpacing + pcbDepth;	// Distance from bottom of PCB to bottom of mounting plate
// Amount the bottom row mounting plate extends to meet the home row
bottomRowToHomeExtension = (
	pcbBottomSpaceAfterLowerBend * sin(lowerRowAngle) +
	distanceToMountingPlateBottom * cos(lowerRowAngle) -
	distanceToMountingPlateBottom
) / sin(lowerRowAngle);
// Amount the home row mounting plate extends to meet the bottom row
homeToBottomRowExtension =
	pcbBottomSpaceUnderHome +
	pcbBottomSpaceAfterLowerBend * cos(lowerRowAngle) -
	distanceToMountingPlateBottom * sin(lowerRowAngle) -
	bottomRowToHomeExtension * cos(lowerRowAngle);
// Amount the top row mounting plate extends to meet the home row
topRowToHomeExtension = (
	pcbBottomSpaceAfterUpperBend * sin(upperRowAngle) +
	distanceToMountingPlateBottom * cos(upperRowAngle) -
	distanceToMountingPlateBottom
) / sin(upperRowAngle);
// Amount the home row mounting plate extends to meet the top row
homeToTopRowExtension =
	pcbBottomSpaceAboveHome +
	pcbBottomSpaceAfterUpperBend * cos(upperRowAngle) -
	distanceToMountingPlateBottom * sin(upperRowAngle) -
	topRowToHomeExtension * cos(upperRowAngle);

extraRowExtension = 5;	// Arbitrary extra extension past top and bottom rows
minDepthBelowPcb = 5;	// Extra spacing below PCB to make room for wiring, etc.

// Length of the bottom row from diagonal wall to home row
bottomRowLength = keySize + bottomRowToHomeExtension + extraRowExtension;
// Length of the top row from diagnonal wall to home row
topRowLength = keySize + topRowToHomeExtension + extraRowExtension;
// Length of the home row
homeRowLength = keySize + homeToTopRowExtension + homeToBottomRowExtension;
// Height from "bottom of model" to bottom of mounting plate for home row
mountHeight = distanceToMountingPlateBottom + minDepthBelowPcb;

bottomRowWallHeightPinky =
	mountHeight +
	bottomRowLength * sin(lowerRowAngle) -
	mountHeight * cos(lowerRowAngle);
bottomRowWallDistancePinky =
	keySize + homeToBottomRowExtension +
	bottomRowLength * cos(lowerRowAngle) +
	mountHeight * sin(lowerRowAngle);

bottomRowWallDistanceRing =
	bottomRowWallDistancePinky -
	(ringYOffset + pinkyYOffset);
bottomRowWallMountHeightRing =
	(
		bottomRowWallDistanceRing -
		keySize - homeToBottomRowExtension -
		bottomRowLength * cos(lowerRowAngle)
	) / sin(lowerRowAngle);
bottomRowWallHeightRing =
	mountHeight +
	bottomRowLength * sin(lowerRowAngle) -
	bottomRowWallMountHeightRing * cos(lowerRowAngle);

bottomRowWallDistanceMiddle = bottomRowWallDistanceRing + middleYOffset;
bottomRowWallMountHeightMiddle =
	(
		bottomRowWallDistanceMiddle -
		keySize - homeToBottomRowExtension -
		bottomRowLength * cos(lowerRowAngle)
	) / sin(lowerRowAngle);
bottomRowWallHeightMiddle =
	mountHeight +
	bottomRowLength * sin(lowerRowAngle) -
	bottomRowWallMountHeightMiddle * cos(lowerRowAngle);

bottomRowWallDistanceIndex = bottomRowWallDistanceMiddle - middleYOffset;
bottomRowWallMountHeightIndex =
	(
		bottomRowWallDistanceIndex -
		keySize - homeToBottomRowExtension -
		bottomRowLength * cos(lowerRowAngle)
	) / sin(lowerRowAngle);
bottomRowWallHeightIndex =
	mountHeight +
	bottomRowLength * sin(lowerRowAngle) -
	bottomRowWallMountHeightIndex * cos(lowerRowAngle);

topRowWallHeightMiddle =
	mountHeight +
	topRowLength * sin(upperRowAngle) -
	mountHeight * cos(upperRowAngle);
topRowWallDistanceMiddle =
	homeToTopRowExtension +
	topRowLength * cos(upperRowAngle) +
	mountHeight * sin(upperRowAngle);

topRowWallDistanceIndex =
	topRowWallDistanceMiddle + middleYOffset;
topRowWallMountHeightIndex =
	(
		topRowWallDistanceIndex -
		homeToTopRowExtension -
		topRowLength * cos(upperRowAngle)
	) / sin(upperRowAngle);
topRowWallHeightIndex =
	mountHeight +
	topRowLength * sin(upperRowAngle) -
	topRowWallMountHeightIndex * cos(upperRowAngle);

topRowWallDistanceRing =
	topRowWallDistanceMiddle + middleYOffset;
topRowWallMountHeightRing =
	(
		topRowWallDistanceRing -
		homeToTopRowExtension -
		topRowLength * cos(upperRowAngle)
	) / sin(upperRowAngle);
topRowWallHeightRing =
	mountHeight +
	topRowLength * sin(upperRowAngle) -
	topRowWallMountHeightRing * cos(upperRowAngle);

topRowWallDistancePinky =
	topRowWallDistanceMiddle + middleYOffset - pinkyYOffset;
topRowWallMountHeightPinky =
	(
		topRowWallDistancePinky -
		homeToTopRowExtension -
		topRowLength * cos(upperRowAngle)
	) / sin(upperRowAngle);
topRowWallHeightPinky =
	mountHeight +
	topRowLength * sin(upperRowAngle) -
	topRowWallMountHeightPinky * cos(upperRowAngle);

pinkyRowAngle = atan2(37, 50);			// Angle between top and bottom rows of pinky plus one row
halfPinkyRowAngle = pinkyRowAngle / 2;	// Top and bottom row each tilted half of angle
pinkyColumnAngle = atan2(41, 40);		// Angle the pinky plus one column is tilted towards the pinky column
// Extra x offset for pinky plus one column to account for rotation inwards
pp1XOffset = keySize * sin(halfPinkyRowAngle) * cos(pinkyColumnAngle);

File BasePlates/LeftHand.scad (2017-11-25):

boardThickness = 3;
p2width = 384;
p2height = 384;

width = 163;
height = 211;

module hole(x, y, cx, cy)
{
	translate([x, y, 0])
	cube([cx, cy, boardThickness]);
}

projection()
difference()
{
	cube([p2width, p2height, boardThickness]);
	hole(width, 0, p2width, p2height);
	hole(0, height, p2width, 10);
	hole(0, height + 80, p2width, 10);
	hole(0, height	+ 160, p2width, p2height);
	hole(1.5, 6.5, 1.5, 10);
	hole(1.5, 21.5, 1.5, 10);
	hole(1.5, 36.5, 1.5, 10);
	hole(1.5, 51.5, 1.5, 10);
	
	hole(1.5, 79.5, 1.5, 10);
	hole(1.5, 94.5, 1.5, 10);
	hole(1.5, 109.5, 1.5, 10);
	hole(1.5, 124.5, 1.5, 10);

	hole(160, 6.5, 1.5, 10);
	hole(160, 21.5, 1.5, 10);
	hole(160, 36.5, 1.5, 10);
	hole(160, 51.5, 1.5, 10);
	
	hole(160, 79.5, 1.5, 10);
	hole(160, 94.5, 1.5, 10);
	hole(160, 109.5, 1.5, 10);
	hole(160, 124.5, 1.5, 10);

	hole(6.5, 1.5, 10, 1.5);
	hole(21.5, 1.5, 10, 1.5);
	hole(36.5, 1.5, 10, 1.5);
	hole(51.5, 1.5, 10, 1.5);
	hole(66.5, 1.5, 10, 1.5);

	hole(86.5, 1.5, 10, 1.5);
	hole(101.5, 1.5, 10, 1.5);
	hole(116.5, 1.5, 10, 1.5);
	hole(131.5, 1.5, 10, 1.5);
	hole(146.5, 1.5, 10, 1.5);

	hole(6.5, 138, 10, 1.5);
	hole(21.5, 138, 10, 1.5);
	hole(36.5, 138, 10, 1.5);
	hole(51.5, 138, 10, 1.5);
	hole(66.5, 138, 10, 1.5);

	hole(86.5, 138, 10, 1.5);
	hole(101.5, 138, 10, 1.5);
	hole(116.5, 138, 10, 1.5);
	hole(131.5, 138, 10, 1.5);
	hole(146.5, 138, 10, 1.5);

}

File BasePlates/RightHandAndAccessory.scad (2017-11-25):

boardThickness = 3;
p2width = 384;
p2height = 384;

width = 345.5;
height = 211;

module hole(x, y, cx, cy)
{
	translate([x, y, 0])
	cube([cx, cy, boardThickness]);
}

projection()
difference()
{
	cube([p2width, p2height, boardThickness]);
	hole(width, 0, p2width, p2height);
	hole(0, height, p2width, 10);
	hole(0, height + 80, p2width, 10);
	hole(0, height	+ 160, p2width, p2height);

	hole(1.5, 6.5, 1.5, 10);
	hole(1.5, 21.5, 1.5, 10);
	hole(1.5, 36.5, 1.5, 10);
	hole(1.5, 51.5, 1.5, 10);
	hole(1.5, 79.5, 1.5, 10);
	hole(1.5, 94.5, 1.5, 10);
	hole(1.5, 109.5, 1.5, 10);
	hole(1.5, 124.5, 1.5, 10);

	hole(189.5, 6.5, 1.5, 10);
	hole(189.5, 21.5, 1.5, 10);
	hole(189.5, 36.5, 1.5, 10);
	hole(189.5, 51.5, 1.5, 10);
	hole(189.5, 79.5, 1.5, 10);
	hole(189.5, 94.5, 1.5, 10);
	hole(189.5, 109.5, 1.5, 10);
	hole(189.5, 124.5, 1.5, 10);

	hole(342.5, 6.5, 1.5, 10);
	hole(342.5, 21.5, 1.5, 10);
	hole(342.5, 36.5, 1.5, 10);
	hole(342.5, 51.5, 1.5, 10);
	hole(342.5, 79.5, 1.5, 10);
	hole(342.5, 94.5, 1.5, 10);
	hole(342.5, 109.5, 1.5, 10);
	hole(342.5, 124.5, 1.5, 10);

	hole(6.5, 1.5, 10, 1.5);
	hole(21.5, 1.5, 10, 1.5);
	hole(36.5, 1.5, 10, 1.5);
	hole(51.5, 1.5, 10, 1.5);
	hole(66.5, 1.5, 10, 1.5);
	hole(81.5, 1.5, 10, 1.5);
	hole(99.5, 1.5, 10, 1.5);
	hole(114.5, 1.5, 10, 1.5);
	hole(129.5, 1.5, 10, 1.5);
	hole(144.5, 1.5, 10, 1.5);
	hole(159.5, 1.5, 10, 1.5);
	hole(174.5, 1.5, 10, 1.5);

	hole(6.5, 138, 10, 1.5);
	hole(21.5, 138, 10, 1.5);
	hole(36.5, 138, 10, 1.5);
	hole(51.5, 138, 10, 1.5);
	hole(66.5, 138, 10, 1.5);
	hole(81.5, 138, 10, 1.5);
	hole(99.5, 138, 10, 1.5);
	hole(114.5, 138, 10, 1.5);
	hole(129.5, 138, 10, 1.5);
	hole(144.5, 138, 10, 1.5);
	hole(159.5, 138, 10, 1.5);
	hole(174.5, 138, 10, 1.5);

	hole(196, 1.5, 10, 1.5);
	hole(211, 1.5, 10, 1.5);
	hole(226, 1.5, 10, 1.5);
	hole(241, 1.5, 10, 1.5);
	hole(256, 1.5, 10, 1.5);
	hole(269, 1.5, 10, 1.5);
	hole(284, 1.5, 10, 1.5);
	hole(299, 1.5, 10, 1.5);
	hole(314, 1.5, 10, 1.5);
	hole(329, 1.5, 10, 1.5);

	hole(196, 138, 10, 1.5);
	hole(211, 138, 10, 1.5);
	hole(226, 138, 10, 1.5);
	hole(241, 138, 10, 1.5);
	hole(256, 138, 10, 1.5);
	hole(269, 138, 10, 1.5);
	hole(284, 138, 10, 1.5);
	hole(299, 138, 10, 1.5);
	hole(314, 138, 10, 1.5);
	hole(329, 138, 10, 1.5);
}

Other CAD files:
Case/LeftHandTop.stl
FacePlates/Accessory.v2.dxf
Case/LeftHandLeft.stl
FacePlates/RightHand.v2.dxf
BasePlates/V5.scad
BasePlates/V4.dxf
BasePlates/V4.scad
Case/LeftHandBottom.scad
Case/LeftHandBottom.stl
Case/LeftHandLeft.scad
Case/LeftHandRight.scad
Case/LeftHandRight.stl
Case/LeftHandTop.scad
Case/RightHandAndAccessoryBottom.scad
Case/RightHandAndAccessoryLeft.scad
Case/RightHandAndAccessoryMiddle.scad
Case/RightHandAndAccessoryRight.scad
Case/RightHandAndAccessoryTop.scad
FacePlates/Accessory.scad
FacePlates/LeftHand.scad
FacePlates/LeftHand.v2.dxf
FacePlates/RightHand.scad
FacePlates/V4.dxf
FacePlates/V4.scad
FacePlates/V5.scad
Mini/V1/DXF/basePlate.dxf
Mini/V1/DXF/controller.dxf
Mini/V1/DXF/facePlate.dxf
Mini/V1/DXF/lowerLayer.dxf
Mini/V1/DXF/mountingPlate.dxf
Mini/V1/DXF/upperLayer.dxf
Mini/V1/constants.scad
Mini/V1/mini.scad
Mini/V2/DXF/basePlate.dxf
Mini/V2/DXF/controller.dxf
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

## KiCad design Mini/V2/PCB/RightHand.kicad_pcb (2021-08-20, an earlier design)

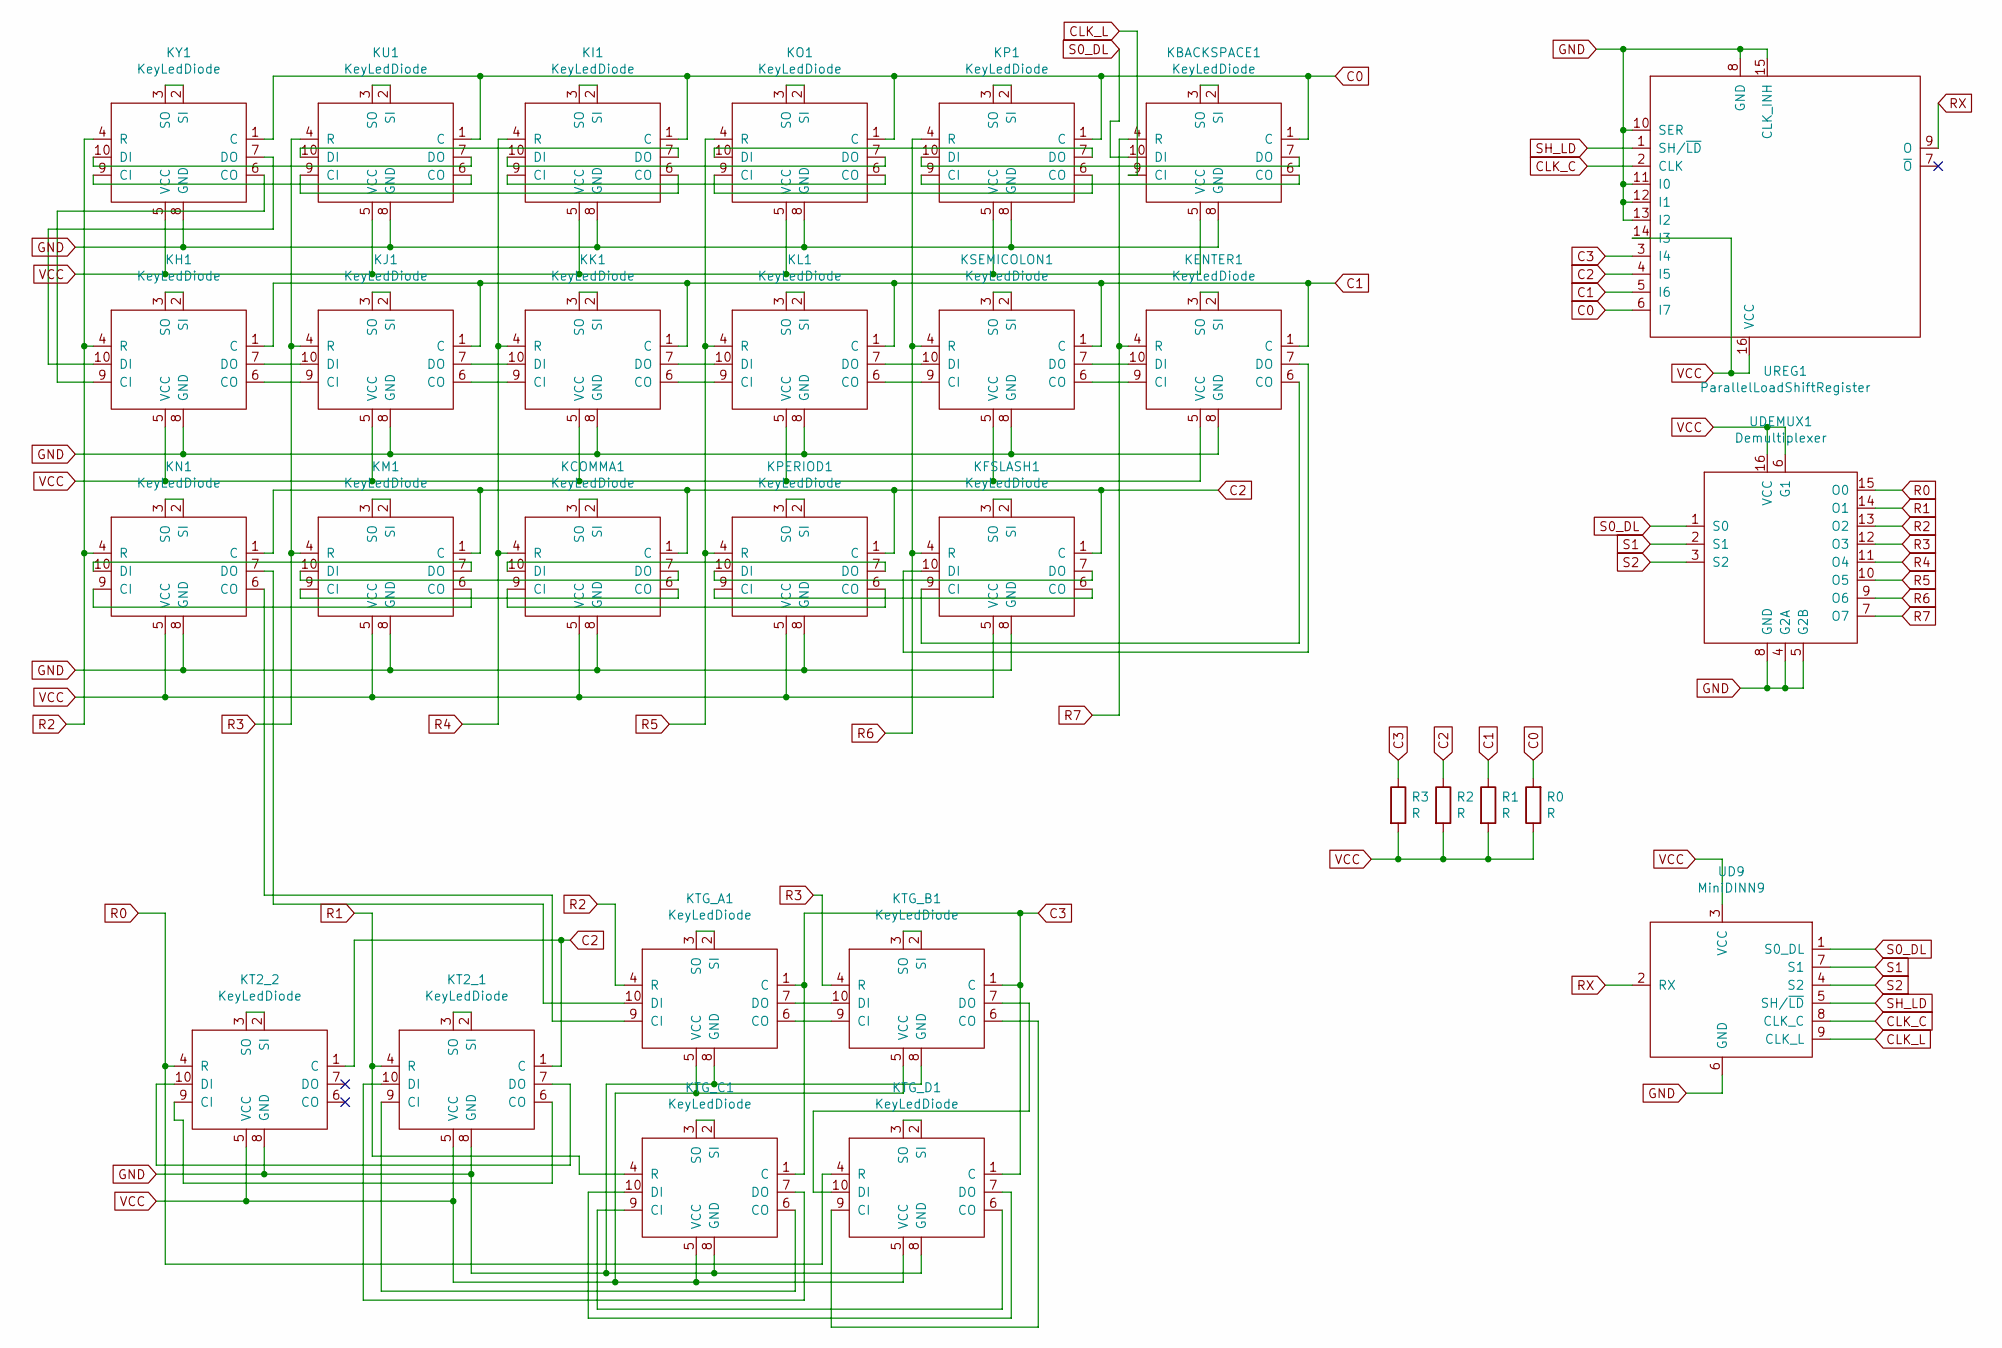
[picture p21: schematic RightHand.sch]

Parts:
KBACKSPACE1: KeyLedDiode; KeyLedDiodeR2L
KCOMMA1: KeyLedDiode; KeyLedDiodeR2L
KENTER1: KeyLedDiode; KeyLedDiodeL2R
KFSLASH1: KeyLedDiode; KeyLedDiodeR2L
KH1: KeyLedDiode; KeyLedDiodeL2R
KI1: KeyLedDiode; KeyLedDiodeR2L
KJ1: KeyLedDiode; KeyLedDiodeL2R
KK1: KeyLedDiode; KeyLedDiodeL2R
KL1: KeyLedDiode; KeyLedDiodeL2R
KM1: KeyLedDiode; KeyLedDiodeR2L
KN1: KeyLedDiode; KeyLedDiodeR2L
KO1: KeyLedDiode; KeyLedDiodeR2L
KP1: KeyLedDiode; KeyLedDiodeR2L
KPERIOD1: KeyLedDiode; KeyLedDiodeR2L
KSEMICOLON1: KeyLedDiode; KeyLedDiodeL2R
KT2_1: KeyLedDiode; Key2LedDiodeL2R
KT2_2: KeyLedDiode; Key2LedDiodeR2L
KTG_A1: KeyLedDiode; KeyLedDiodeL2R
KTG_B1: KeyLedDiode; KeyLedDiodeL2R
KTG_C1: KeyLedDiode; KeyLedDiodeR2L
KTG_D1: KeyLedDiode; KeyLedDiodeR2L
KU1: KeyLedDiode; KeyLedDiodeR2L
KY1: KeyLedDiode; KeyLedDiodeR2L
R0, R1, R2, R3: R; PullupResistor
UD9: MiniDINN9; MiniDin9
UDEMUX1: Demultiplexer; DualInlineMicrochip2x8
UREG1: ParallelLoadShiftRegister; DualInlineMicrochip2x8

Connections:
C0: KBACKSPACE1.1 (C), KI1.1 (C), KO1.1 (C), KP1.1 (C), KU1.1 (C), KY1.1 (C), R0.2, UREG1.6 (I7)
C1: KENTER1.1 (C), KH1.1 (C), KJ1.1 (C), KK1.1 (C), KL1.1 (C), KSEMICOLON1.1 (C), R1.1, UREG1.5 (I6)
C2: KCOMMA1.1 (C), KFSLASH1.1 (C), KM1.1 (C), KN1.1 (C), KPERIOD1.1 (C), KT2_1.1 (C), KT2_2.1 (C), R2.1, UREG1.4 (I5)
C3: KTG_A1.1 (C), KTG_B1.1 (C), KTG_C1.1 (C), KTG_D1.1 (C), R3.1, UREG1.3 (I4)
CLK_C: UD9.8 (CLK_C), UREG1.2 (CLK)
CLK_L: KBACKSPACE1.9 (CI), UD9.9 (CLK_L)
GND: KBACKSPACE1.8 (GND), KCOMMA1.8 (GND), KENTER1.8 (GND), KFSLASH1.8 (GND), KH1.8 (GND), KI1.8 (GND), KJ1.8 (GND), KK1.8 (GND), KL1.8 (GND), KM1.8 (GND), KN1.8 (GND), KO1.8 (GND), KP1.8 (GND), KPERIOD1.8 (GND), KSEMICOLON1.8 (GND), KT2_1.8 (GND), KT2_2.8 (GND), KTG_A1.8 (GND), KTG_B1.8 (GND), KTG_C1.8 (GND), KTG_D1.8 (GND), KU1.8 (GND), KY1.8 (GND), UD9.6 (GND), UDEMUX1.4 (G2A), UDEMUX1.5 (G2B), UDEMUX1.8 (GND), UREG1.8 (GND), UREG1.10 (SER), UREG1.11 (I0), UREG1.12 (I1), UREG1.13 (I2), UREG1.15 (CLK_INH)
unnamed: KBACKSPACE1.2 (SI), KBACKSPACE1.3 (SO)
unnamed: KBACKSPACE1.6 (CO), KP1.9 (CI)
unnamed: KBACKSPACE1.7 (DO), KP1.10 (DI)
unnamed: KCOMMA1.2 (SI), KCOMMA1.3 (SO)
unnamed: KCOMMA1.6 (CO), KM1.9 (CI)
unnamed: KCOMMA1.7 (DO), KM1.10 (DI)
unnamed: KCOMMA1.9 (CI), KPERIOD1.6 (CO)
unnamed: KCOMMA1.10 (DI), KPERIOD1.7 (DO)
unnamed: KENTER1.2 (SI), KENTER1.3 (SO)
unnamed: KENTER1.6 (CO), KFSLASH1.9 (CI)
unnamed: KENTER1.7 (DO), KFSLASH1.10 (DI)
unnamed: KENTER1.9 (CI), KSEMICOLON1.6 (CO)
unnamed: KENTER1.10 (DI), KSEMICOLON1.7 (DO)
unnamed: KFSLASH1.2 (SI), KFSLASH1.3 (SO)
unnamed: KFSLASH1.6 (CO), KPERIOD1.9 (CI)
unnamed: KFSLASH1.7 (DO), KPERIOD1.10 (DI)
unnamed: KH1.2 (SI), KH1.3 (SO)
unnamed: KH1.6 (CO), KJ1.9 (CI)
unnamed: KH1.7 (DO), KJ1.10 (DI)
unnamed: KH1.9 (CI), KY1.6 (CO)
unnamed: KH1.10 (DI), KY1.7 (DO)
unnamed: KI1.2 (SI), KI1.3 (SO)
unnamed: KI1.6 (CO), KU1.9 (CI)
unnamed: KI1.7 (DO), KU1.10 (DI)
unnamed: KI1.9 (CI), KO1.6 (CO)
unnamed: KI1.10 (DI), KO1.7 (DO)
unnamed: KJ1.2 (SI), KJ1.3 (SO)
unnamed: KJ1.6 (CO), KK1.9 (CI)
unnamed: KJ1.7 (DO), KK1.10 (DI)
unnamed: KK1.2 (SI), KK1.3 (SO)
unnamed: KK1.6 (CO), KL1.9 (CI)
unnamed: KK1.7 (DO), KL1.10 (DI)
unnamed: KL1.2 (SI), KL1.3 (SO)
unnamed: KL1.6 (CO), KSEMICOLON1.9 (CI)
unnamed: KL1.7 (DO), KSEMICOLON1.10 (DI)
unnamed: KM1.2 (SI), KM1.3 (SO)
unnamed: KM1.6 (CO), KN1.9 (CI)
unnamed: KM1.7 (DO), KN1.10 (DI)
unnamed: KN1.2 (SI), KN1.3 (SO)
unnamed: KN1.6 (CO), KTG_A1.9 (CI)
unnamed: KN1.7 (DO), KTG_A1.10 (DI)
unnamed: KO1.2 (SI), KO1.3 (SO)
unnamed: KO1.9 (CI), KP1.6 (CO)
unnamed: KO1.10 (DI), KP1.7 (DO)
unnamed: KP1.2 (SI), KP1.3 (SO)
unnamed: KPERIOD1.2 (SI), KPERIOD1.3 (SO)
unnamed: KSEMICOLON1.2 (SI), KSEMICOLON1.3 (SO)
unnamed: KT2_1.2 (SI), KT2_1.3 (SO)
unnamed: KT2_1.6 (CO), KT2_2.9 (CI)
unnamed: KT2_1.7 (DO), KT2_2.10 (DI)
unnamed: KT2_1.9 (CI), KTG_C1.6 (CO)
unnamed: KT2_1.10 (DI), KTG_C1.7 (DO)
unnamed: KT2_2.2 (SI), KT2_2.3 (SO)
unnamed: KTG_A1.2 (SI), KTG_A1.3 (SO)
unnamed: KTG_A1.6 (CO), KTG_B1.9 (CI)
unnamed: KTG_A1.7 (DO), KTG_B1.10 (DI)
unnamed: KTG_B1.2 (SI), KTG_B1.3 (SO)
unnamed: KTG_B1.6 (CO), KTG_D1.9 (CI)
unnamed: KTG_B1.7 (DO), KTG_D1.10 (DI)
unnamed: KTG_C1.2 (SI), KTG_C1.3 (SO)
unnamed: KTG_C1.9 (CI), KTG_D1.6 (CO)
unnamed: KTG_C1.10 (DI), KTG_D1.7 (DO)
unnamed: KTG_D1.2 (SI), KTG_D1.3 (SO)
unnamed: KU1.2 (SI), KU1.3 (SO)
unnamed: KU1.6 (CO), KY1.9 (CI)
unnamed: KU1.7 (DO), KY1.10 (DI)
unnamed: KY1.2 (SI), KY1.3 (SO)
R0: KT2_2.4 (R), KTG_D1.4 (R), UDEMUX1.15 (O0)
R1: KT2_1.4 (R), KTG_C1.4 (R), UDEMUX1.14 (O1)
R2: KH1.4 (R), KN1.4 (R), KTG_A1.4 (R), KY1.4 (R), UDEMUX1.13 (O2)
R3: KJ1.4 (R), KM1.4 (R), KTG_B1.4 (R), KU1.4 (R), UDEMUX1.12 (O3)
R4: KCOMMA1.4 (R), KI1.4 (R), KK1.4 (R), UDEMUX1.11 (O4)
R5: KL1.4 (R), KO1.4 (R), KPERIOD1.4 (R), UDEMUX1.10 (O5)
R6: KFSLASH1.4 (R), KP1.4 (R), KSEMICOLON1.4 (R), UDEMUX1.9 (O6)
R7: KBACKSPACE1.4 (R), KENTER1.4 (R), UDEMUX1.7 (O7)
RX: UD9.2 (RX), UREG1.9 (O)
S0_DL: KBACKSPACE1.10 (DI), UD9.1 (S0_DL), UDEMUX1.1 (S0)
S1: UD9.7 (S1), UDEMUX1.2 (S1)
S2: UD9.4 (S2), UDEMUX1.3 (S2)
SH_LD: UD9.5 (SH/~LD), UREG1.1 (SH/~LD)
VCC: KBACKSPACE1.5 (VCC), KCOMMA1.5 (VCC), KENTER1.5 (VCC), KFSLASH1.5 (VCC), KH1.5 (VCC), KI1.5 (VCC), KJ1.5 (VCC), KK1.5 (VCC), KL1.5 (VCC), KM1.5 (VCC), KN1.5 (VCC), KO1.5 (VCC), KP1.5 (VCC), KPERIOD1.5 (VCC), KSEMICOLON1.5 (VCC), KT2_1.5 (VCC), KT2_2.5 (VCC), KTG_A1.5 (VCC), KTG_B1.5 (VCC), KTG_C1.5 (VCC), KTG_D1.5 (VCC), KU1.5 (VCC), KY1.5 (VCC), R0.1, R1.2, R2.2, R3.2, UD9.3 (VCC), UDEMUX1.6 (G1), UDEMUX1.16 (VCC), UREG1.14 (I3), UREG1.16 (VCC)

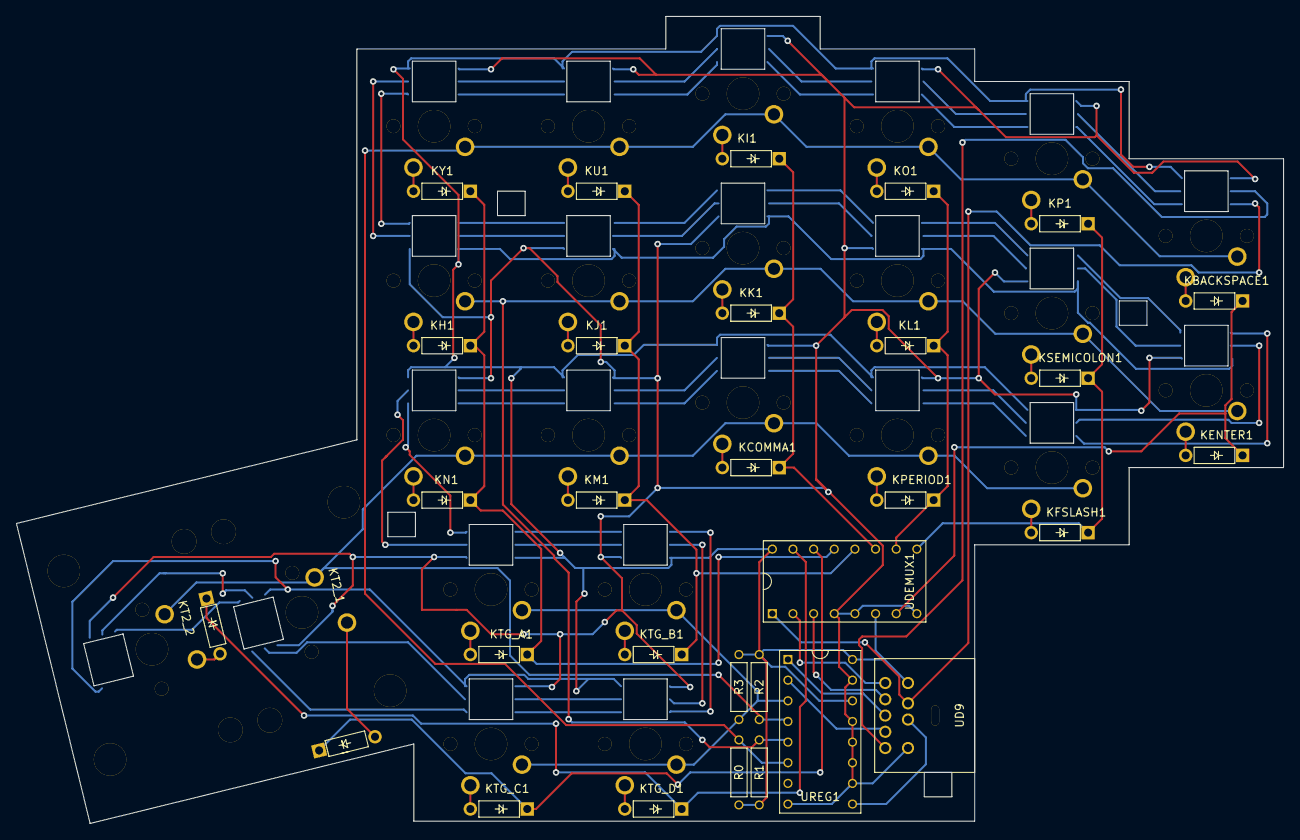
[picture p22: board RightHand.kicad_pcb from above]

Board: 2 copper layers, 155.9 x 99.3 mm, 30 parts (0 on the bottom side), 88 nets.

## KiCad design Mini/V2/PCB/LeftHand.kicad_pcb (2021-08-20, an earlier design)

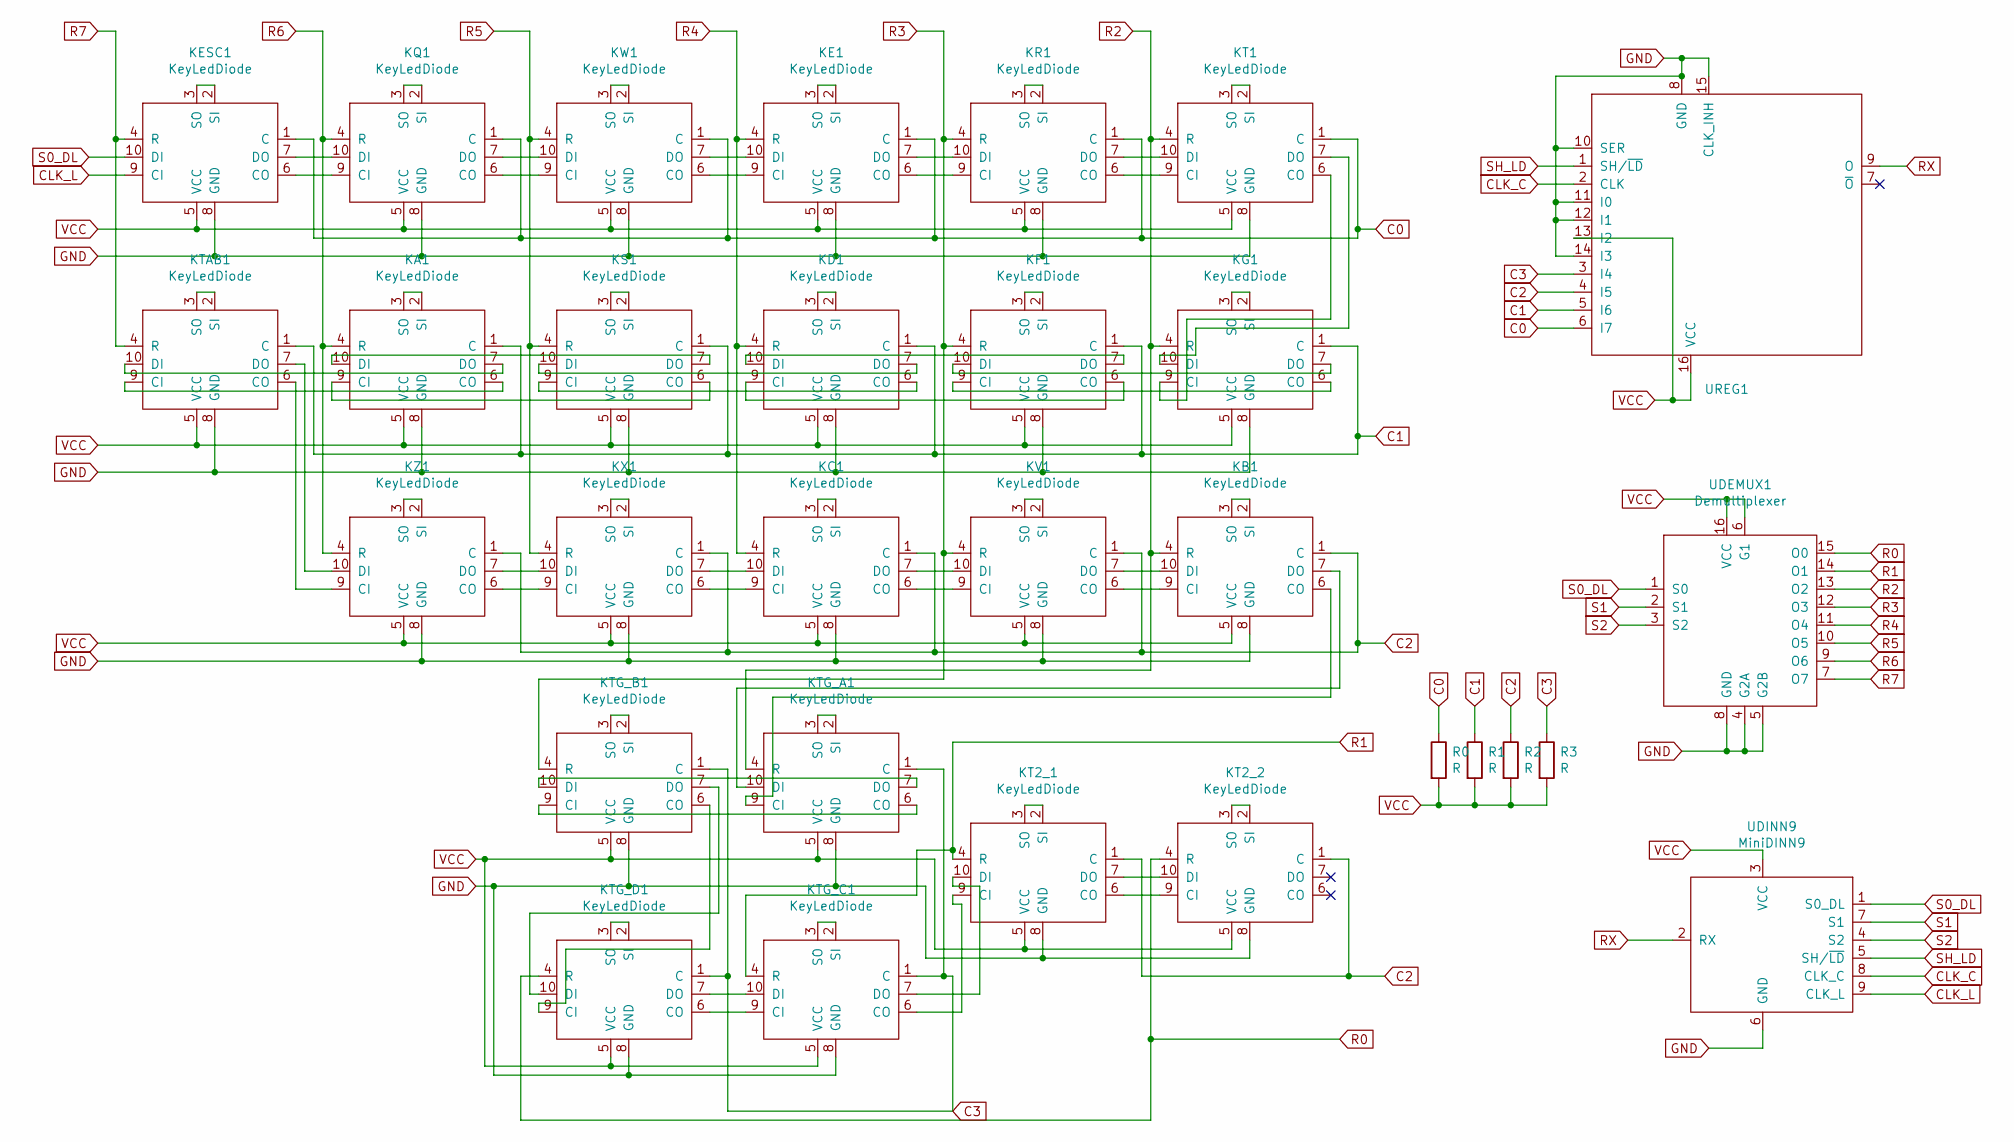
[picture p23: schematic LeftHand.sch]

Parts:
KA1: KeyLedDiode; KeyLedDiodeR2L
KB1: KeyLedDiode; KeyLedDiodeL2R
KC1: KeyLedDiode; KeyLedDiodeL2R
KD1: KeyLedDiode; KeyLedDiodeR2L
KE1: KeyLedDiode; KeyLedDiodeL2R
KESC1: KeyLedDiode; KeyLedDiodeL2R
KF1: KeyLedDiode; KeyLedDiodeR2L
KG1: KeyLedDiode; KeyLedDiodeR2L
KQ1: KeyLedDiode; KeyLedDiodeL2R
KR1: KeyLedDiode; KeyLedDiodeL2R
KS1: KeyLedDiode; KeyLedDiodeR2L
KT1: KeyLedDiode; KeyLedDiodeL2R
KT2_1: KeyLedDiode; Key2LedDiodeL2R
KT2_2: KeyLedDiode; Key2LedDiodeR2L
KTAB1: KeyLedDiode; KeyLedDiodeR2L
KTG_A1: KeyLedDiode; KeyLedDiodeR2L
KTG_B1: KeyLedDiode; KeyLedDiodeR2L
KTG_C1: KeyLedDiode; KeyLedDiodeL2R
KTG_D1: KeyLedDiode; KeyLedDiodeL2R
KV1: KeyLedDiode; KeyLedDiodeL2R
KW1: KeyLedDiode; KeyLedDiodeL2R
KX1: KeyLedDiode; KeyLedDiodeL2R
KZ1: KeyLedDiode; KeyLedDiodeL2R
R0, R1, R2, R3: R; PullupResistor
UDEMUX1: Demultiplexer; DualInlineMicrochip2x8
UDINN9: MiniDINN9; MiniDin9
UREG1: ParallelLoadShiftRegister; DualInlineMicrochip2x8

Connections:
C0: KE1.1 (C), KESC1.1 (C), KQ1.1 (C), KR1.1 (C), KT1.1 (C), KW1.1 (C), R0.1, UREG1.6 (I7)
C1: KA1.1 (C), KD1.1 (C), KF1.1 (C), KG1.1 (C), KS1.1 (C), KTAB1.1 (C), R1.1, UREG1.5 (I6)
C2: KB1.1 (C), KC1.1 (C), KT2_1.1 (C), KT2_2.1 (C), KV1.1 (C), KX1.1 (C), KZ1.1 (C), R2.1, UREG1.4 (I5)
C3: KTG_A1.1 (C), KTG_B1.1 (C), KTG_C1.1 (C), KTG_D1.1 (C), R3.1, UREG1.3 (I4)
CLK_C: UDINN9.8 (CLK_C), UREG1.2 (CLK)
CLK_L: KESC1.9 (CI), UDINN9.9 (CLK_L)
GND: KA1.8 (GND), KB1.8 (GND), KC1.8 (GND), KD1.8 (GND), KE1.8 (GND), KESC1.8 (GND), KF1.8 (GND), KG1.8 (GND), KQ1.8 (GND), KR1.8 (GND), KS1.8 (GND), KT1.8 (GND), KT2_1.8 (GND), KT2_2.8 (GND), KTAB1.8 (GND), KTG_A1.8 (GND), KTG_B1.8 (GND), KTG_C1.8 (GND), KTG_D1.8 (GND), KV1.8 (GND), KW1.8 (GND), KX1.8 (GND), KZ1.8 (GND), UDEMUX1.4 (G2A), UDEMUX1.5 (G2B), UDEMUX1.8 (GND), UDINN9.6 (GND), UREG1.8 (GND), UREG1.10 (SER), UREG1.11 (I0), UREG1.12 (I1), UREG1.14 (I3), UREG1.15 (CLK_INH)
unnamed: KA1.2 (SI), KA1.3 (SO)
unnamed: KA1.6 (CO), KTAB1.9 (CI)
unnamed: KA1.7 (DO), KTAB1.10 (DI)
unnamed: KA1.9 (CI), KS1.6 (CO)
unnamed: KA1.10 (DI), KS1.7 (DO)
unnamed: KB1.2 (SI), KB1.3 (SO)
unnamed: KB1.6 (CO), KTG_A1.9 (CI)
unnamed: KB1.7 (DO), KTG_A1.10 (DI)
unnamed: KB1.9 (CI), KV1.6 (CO)
unnamed: KB1.10 (DI), KV1.7 (DO)
unnamed: KC1.2 (SI), KC1.3 (SO)
unnamed: KC1.6 (CO), KV1.9 (CI)
unnamed: KC1.7 (DO), KV1.10 (DI)
unnamed: KC1.9 (CI), KX1.6 (CO)
unnamed: KC1.10 (DI), KX1.7 (DO)
unnamed: KD1.2 (SI), KD1.3 (SO)
unnamed: KD1.6 (CO), KS1.9 (CI)
unnamed: KD1.7 (DO), KS1.10 (DI)
unnamed: KD1.9 (CI), KF1.6 (CO)
unnamed: KD1.10 (DI), KF1.7 (DO)
unnamed: KE1.2 (SI), KE1.3 (SO)
unnamed: KE1.6 (CO), KR1.9 (CI)
unnamed: KE1.7 (DO), KR1.10 (DI)
unnamed: KE1.9 (CI), KW1.6 (CO)
unnamed: KE1.10 (DI), KW1.7 (DO)
unnamed: KESC1.2 (SI), KESC1.3 (SO)
unnamed: KESC1.6 (CO), KQ1.9 (CI)
unnamed: KESC1.7 (DO), KQ1.10 (DI)
unnamed: KF1.2 (SI), KF1.3 (SO)
unnamed: KF1.9 (CI), KG1.6 (CO)
unnamed: KF1.10 (DI), KG1.7 (DO)
unnamed: KG1.2 (SI), KG1.3 (SO)
unnamed: KG1.9 (CI), KT1.6 (CO)
unnamed: KG1.10 (DI), KT1.7 (DO)
unnamed: KQ1.2 (SI), KQ1.3 (SO)
unnamed: KQ1.6 (CO), KW1.9 (CI)
unnamed: KQ1.7 (DO), KW1.10 (DI)
unnamed: KR1.2 (SI), KR1.3 (SO)
unnamed: KR1.6 (CO), KT1.9 (CI)
unnamed: KR1.7 (DO), KT1.10 (DI)
unnamed: KS1.2 (SI), KS1.3 (SO)
unnamed: KT1.2 (SI), KT1.3 (SO)
unnamed: KT2_1.2 (SI), KT2_1.3 (SO)
unnamed: KT2_1.6 (CO), KT2_2.9 (CI)
unnamed: KT2_1.7 (DO), KT2_2.10 (DI)
unnamed: KT2_1.9 (CI), KTG_C1.6 (CO)
unnamed: KT2_1.10 (DI), KTG_C1.7 (DO)
unnamed: KT2_2.2 (SI), KT2_2.3 (SO)
unnamed: KTAB1.2 (SI), KTAB1.3 (SO)
unnamed: KTAB1.6 (CO), KZ1.9 (CI)
unnamed: KTAB1.7 (DO), KZ1.10 (DI)
unnamed: KTG_A1.2 (SI), KTG_A1.3 (SO)
unnamed: KTG_A1.6 (CO), KTG_B1.9 (CI)
unnamed: KTG_A1.7 (DO), KTG_B1.10 (DI)
unnamed: KTG_B1.2 (SI), KTG_B1.3 (SO)
unnamed: KTG_B1.6 (CO), KTG_D1.9 (CI)
unnamed: KTG_B1.7 (DO), KTG_D1.10 (DI)
unnamed: KTG_C1.2 (SI), KTG_C1.3 (SO)
unnamed: KTG_C1.9 (CI), KTG_D1.6 (CO)
unnamed: KTG_C1.10 (DI), KTG_D1.7 (DO)
unnamed: KTG_D1.2 (SI), KTG_D1.3 (SO)
unnamed: KV1.2 (SI), KV1.3 (SO)
unnamed: KW1.2 (SI), KW1.3 (SO)
unnamed: KX1.2 (SI), KX1.3 (SO)
unnamed: KX1.9 (CI), KZ1.6 (CO)
unnamed: KX1.10 (DI), KZ1.7 (DO)
unnamed: KZ1.2 (SI), KZ1.3 (SO)
R0: KT2_2.4 (R), KTG_D1.4 (R), UDEMUX1.15 (O0)
R1: KT2_1.4 (R), KTG_C1.4 (R), UDEMUX1.14 (O1)
R2: KB1.4 (R), KG1.4 (R), KT1.4 (R), KTG_A1.4 (R), UDEMUX1.13 (O2)
R3: KF1.4 (R), KR1.4 (R), KTG_B1.4 (R), KV1.4 (R), UDEMUX1.12 (O3)
R4: KC1.4 (R), KD1.4 (R), KE1.4 (R), UDEMUX1.11 (O4)
R5: KS1.4 (R), KW1.4 (R), KX1.4 (R), UDEMUX1.10 (O5)
R6: KA1.4 (R), KQ1.4 (R), KZ1.4 (R), UDEMUX1.9 (O6)
R7: KESC1.4 (R), KTAB1.4 (R), UDEMUX1.7 (O7)
RX: UDINN9.2 (RX), UREG1.9 (O)
S0_DL: KESC1.10 (DI), UDEMUX1.1 (S0), UDINN9.1 (S0_DL)
S1: UDEMUX1.2 (S1), UDINN9.7 (S1)
S2: UDEMUX1.3 (S2), UDINN9.4 (S2)
SH_LD: UDINN9.5 (SH/~LD), UREG1.1 (SH/~LD)
VCC: KA1.5 (VCC), KB1.5 (VCC), KC1.5 (VCC), KD1.5 (VCC), KE1.5 (VCC), KESC1.5 (VCC), KF1.5 (VCC), KG1.5 (VCC), KQ1.5 (VCC), KR1.5 (VCC), KS1.5 (VCC), KT1.5 (VCC), KT2_1.5 (VCC), KT2_2.5 (VCC), KTAB1.5 (VCC), KTG_A1.5 (VCC), KTG_B1.5 (VCC), KTG_C1.5 (VCC), KTG_D1.5 (VCC), KV1.5 (VCC), KW1.5 (VCC), KX1.5 (VCC), KZ1.5 (VCC), R0.2, R1.2, R2.2, R3.2, UDEMUX1.6 (G1), UDEMUX1.16 (VCC), UDINN9.3 (VCC), UREG1.13 (I2), UREG1.16 (VCC)

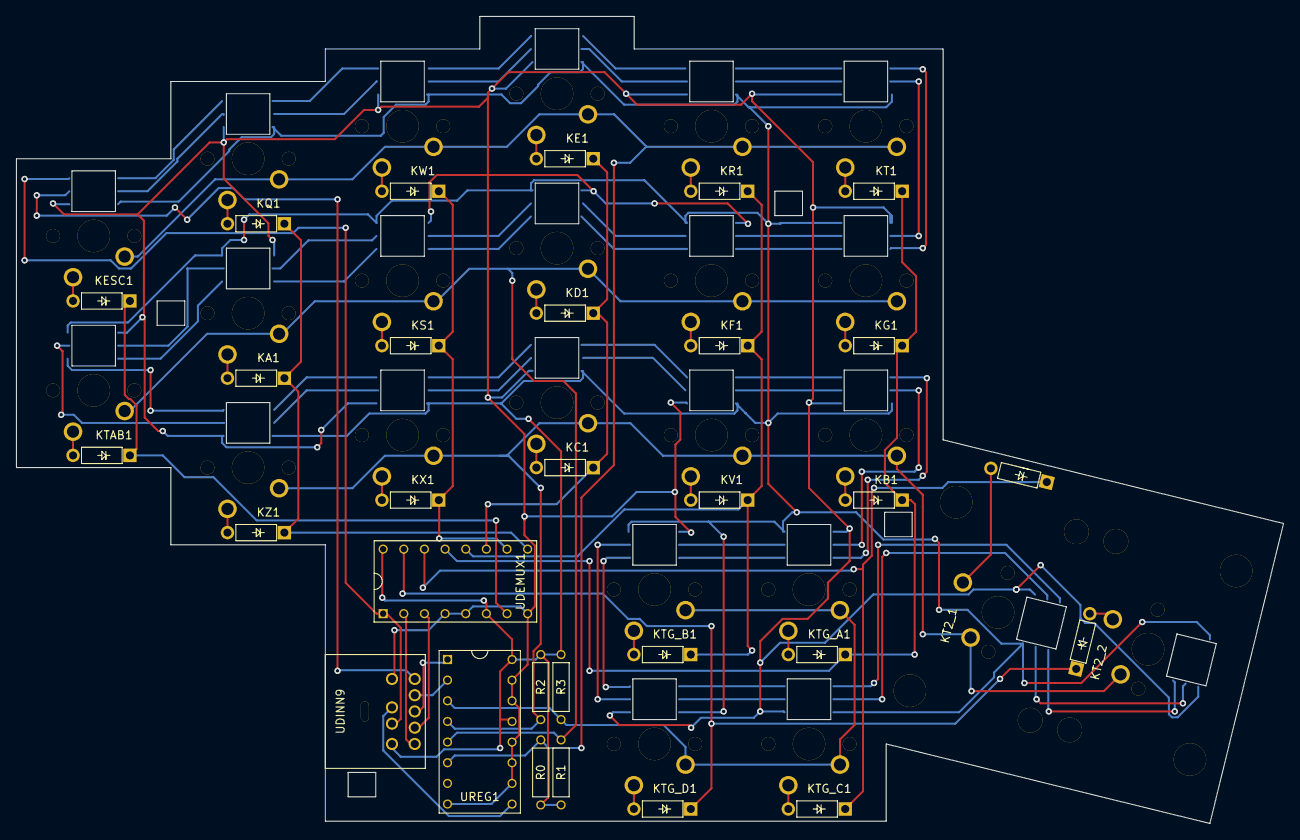
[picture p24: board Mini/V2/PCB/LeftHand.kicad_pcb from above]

Board: 2 copper layers, 155.9 x 99.3 mm, 30 parts (0 on the bottom side), 88 nets.

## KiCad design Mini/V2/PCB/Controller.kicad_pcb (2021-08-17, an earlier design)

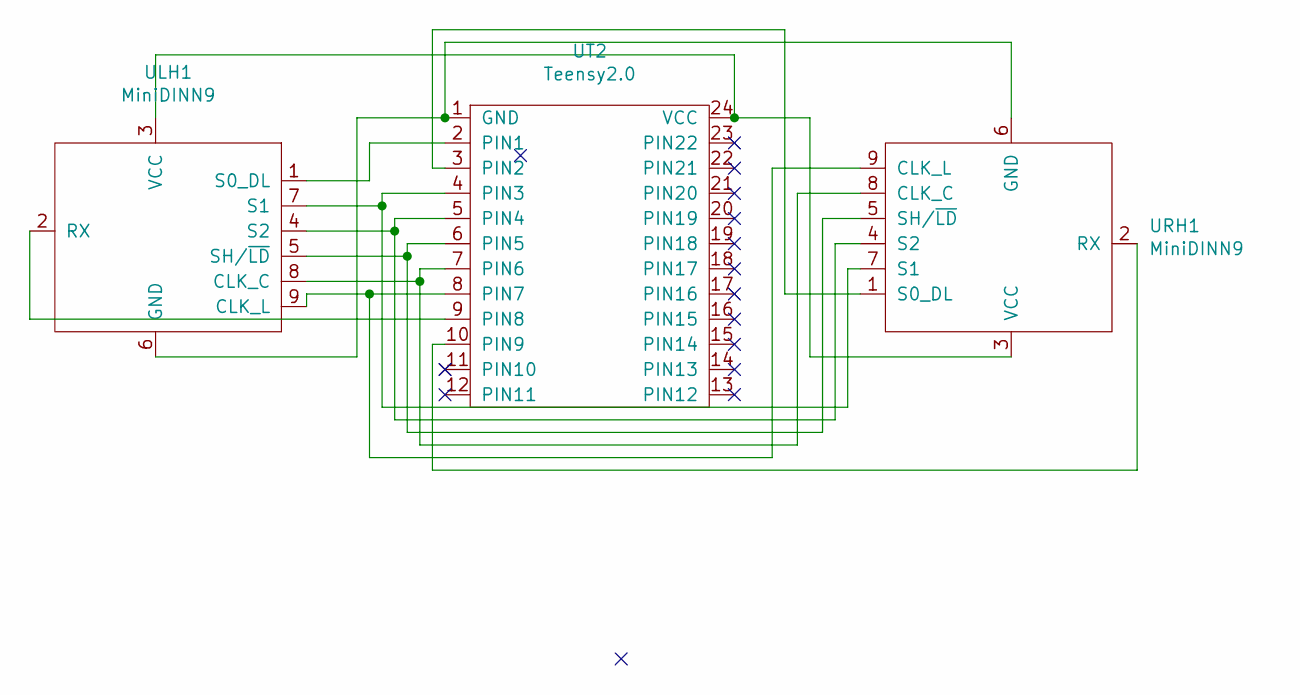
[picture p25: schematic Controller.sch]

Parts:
ULH1: MiniDINN9; MiniDin9
URH1: MiniDINN9; MiniDin9
UT2: Teensy2.0

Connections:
unnamed: ULH1.1 (S0_DL), UT2.2 (PIN1)
unnamed: ULH1.2 (RX), UT2.9 (PIN8)
unnamed: ULH1.3 (VCC), URH1.3 (VCC), UT2.24 (VCC)
unnamed: ULH1.4 (S2), URH1.4 (S2), UT2.5 (PIN4)
unnamed: ULH1.5 (SH/~LD), URH1.5 (SH/~LD), UT2.6 (PIN5)
unnamed: ULH1.6 (GND), URH1.6 (GND), UT2.1 (GND)
unnamed: ULH1.7 (S1), URH1.7 (S1), UT2.4 (PIN3)
unnamed: ULH1.8 (CLK_C), URH1.8 (CLK_C), UT2.7 (PIN6)
unnamed: ULH1.9 (CLK_L), URH1.9 (CLK_L), UT2.8 (PIN7)
unnamed: URH1.1 (S0_DL), UT2.3 (PIN2)
unnamed: URH1.2 (RX), UT2.10 (PIN9)

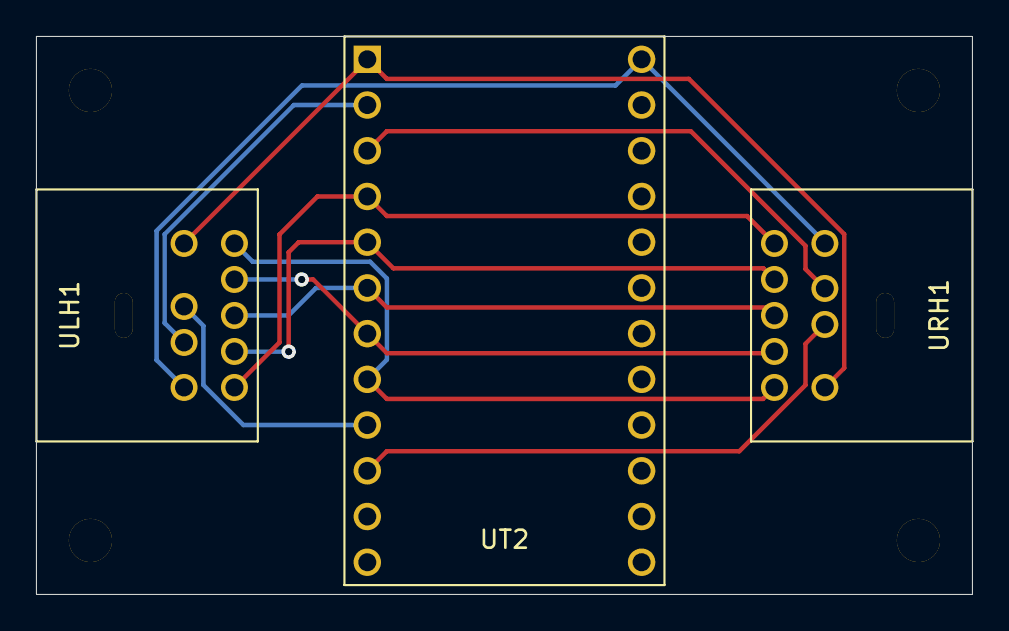
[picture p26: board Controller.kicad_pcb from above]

Board: 2 copper layers, 52.0 x 31.0 mm, 3 parts (0 on the bottom side), 11 nets.

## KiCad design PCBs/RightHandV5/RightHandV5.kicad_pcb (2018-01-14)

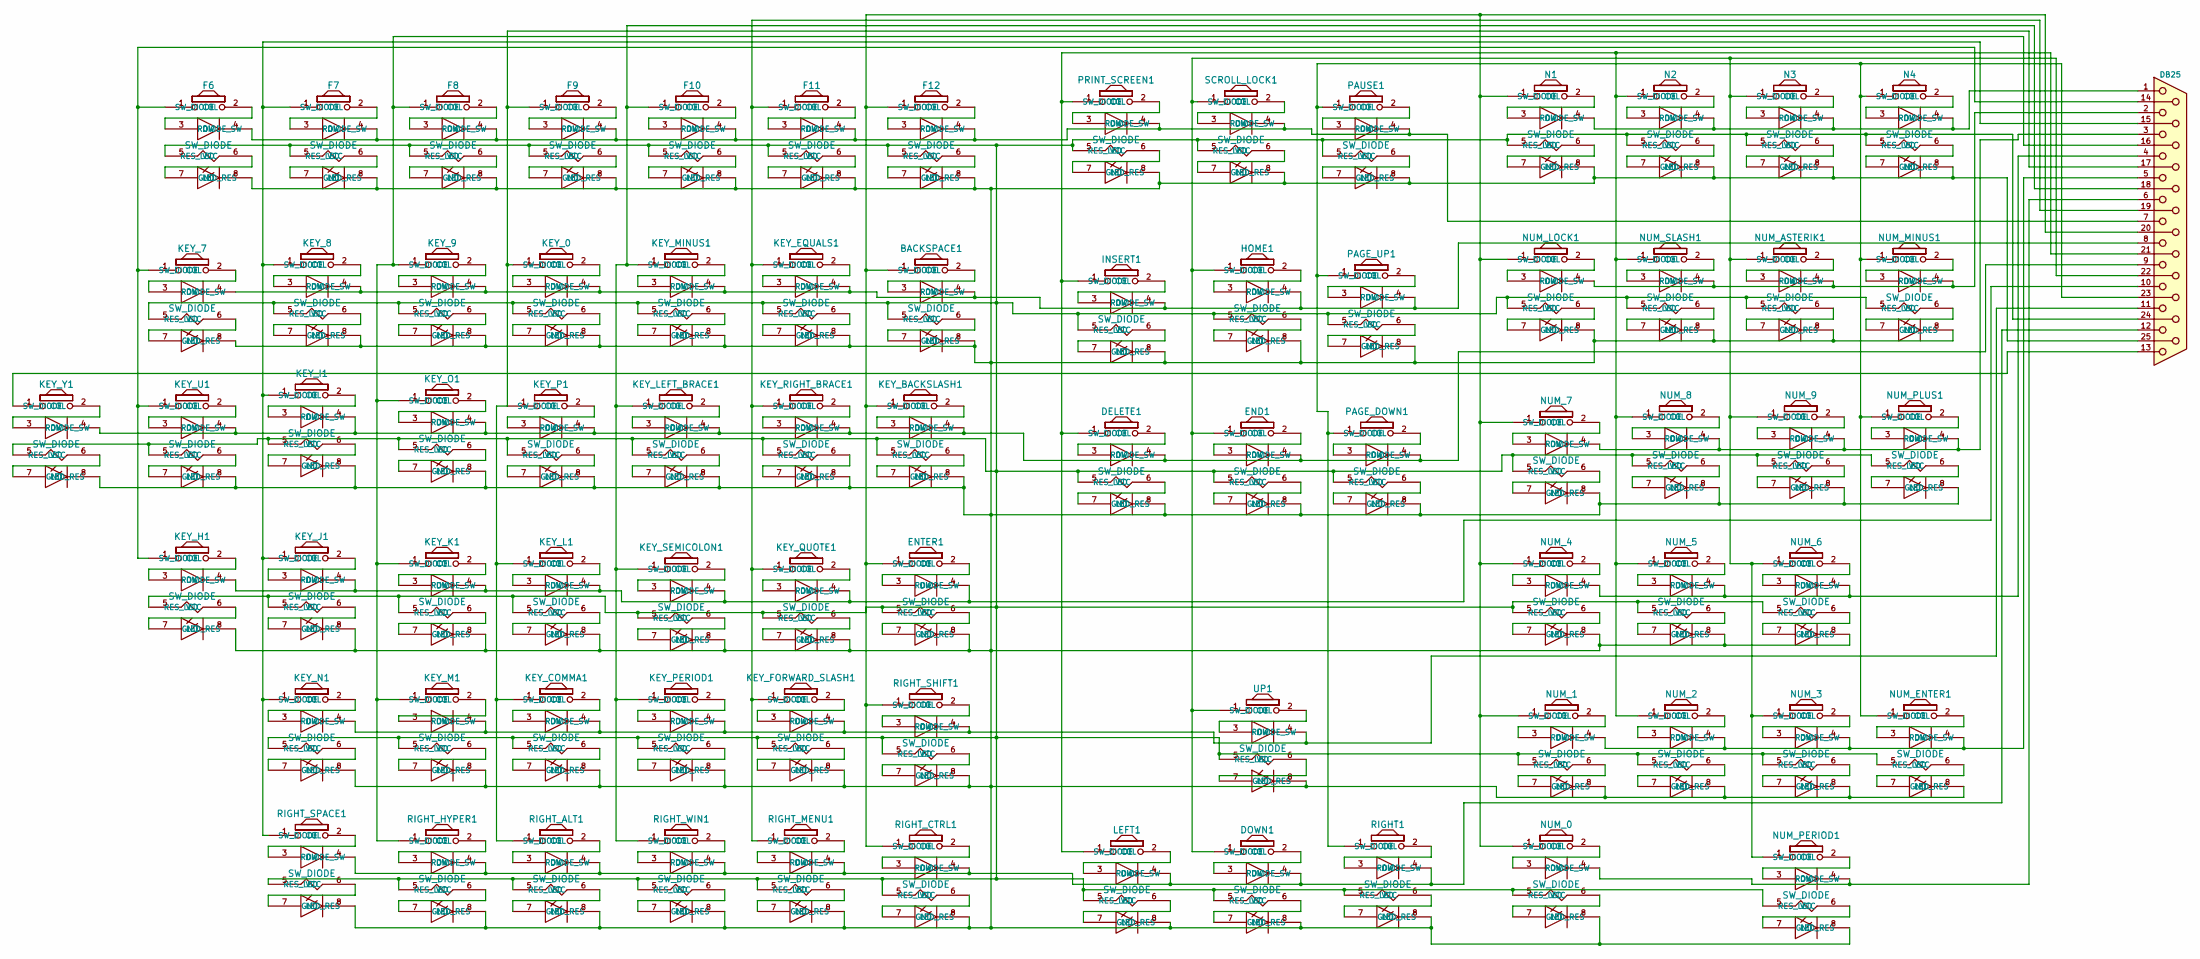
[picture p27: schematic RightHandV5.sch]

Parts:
BACKSPACE1: SW_DIODE; SW2_DIODE_R
DB25: DB25_Female; DB25FD
DELETE1: SW_DIODE
DOWN1: SW_DIODE
END1: SW_DIODE
ENTER1: SW_DIODE; SW2_DIODE_R
F6, F7, F8, F9, F10, F11, F12: SW_DIODE
HOME1: SW_DIODE
INSERT1: SW_DIODE
KEY_0, KEY_7, KEY_8, KEY_9: SW_DIODE
KEY_BACKSLASH1: SW_DIODE; SW_DIODE_RSIDE
KEY_COMMA1: SW_DIODE
KEY_EQUALS1: SW_DIODE
KEY_FORWARD_SLASH1: SW_DIODE
KEY_H1: SW_DIODE
KEY_I1: SW_DIODE
KEY_J1: SW_DIODE
KEY_K1: SW_DIODE
KEY_L1: SW_DIODE
KEY_LEFT_BRACE1: SW_DIODE
KEY_M1: SW_DIODE
KEY_MINUS1: SW_DIODE
KEY_N1: SW_DIODE
KEY_O1: SW_DIODE
KEY_P1: SW_DIODE
KEY_PERIOD1: SW_DIODE
KEY_QUOTE1: SW_DIODE
KEY_RIGHT_BRACE1: SW_DIODE; SW_DIODE_RTOP
KEY_SEMICOLON1: SW_DIODE
KEY_U1: SW_DIODE
KEY_Y1: SW_DIODE
LEFT1: SW_DIODE
N1, N2, N3, N4: SW_DIODE
NUM_0: SW_DIODE; SW2_DIODE_L
NUM_1, NUM_2, NUM_3, NUM_4, NUM_5, NUM_6, NUM_7, NUM_8, NUM_9: SW_DIODE
NUM_ASTERIK1: SW_DIODE
NUM_ENTER1: SW_DIODE; SW2_DIODE_L_RSIDE
NUM_LOCK1: SW_DIODE
NUM_MINUS1: SW_DIODE
NUM_PERIOD1: SW_DIODE
NUM_PLUS1: SW_DIODE; SW2_DIODE_L_RSIDE
NUM_SLASH1: SW_DIODE
PAGE_DOWN1: SW_DIODE
PAGE_UP1: SW_DIODE
PAUSE1: SW_DIODE
PRINT_SCREEN1: SW_DIODE
RIGHT1: SW_DIODE
RIGHT_ALT1: SW_DIODE
RIGHT_CTRL1: SW_DIODE; SW_DIODE_RTOP
RIGHT_HYPER1: SW_DIODE
RIGHT_MENU1: SW_DIODE; SW_DIODE_RTOP
RIGHT_SHIFT1: SW_DIODE; SW2_DIODE_R_RSIDE
RIGHT_SPACE1: SW_DIODE; SW2_DIODE_R_RSIDE
RIGHT_WIN1: SW_DIODE
SCROLL_LOCK1: SW_DIODE
UP1: SW_DIODE

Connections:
unnamed: BACKSPACE1.1 (COL), DB25.20, ENTER1.1 (COL), F12.1 (COL), KEY_BACKSLASH1.1 (COL), N1.1 (COL), NUM_0.1 (COL), NUM_1.1 (COL), NUM_4.1 (COL), NUM_7.1 (COL), NUM_LOCK1.1 (COL), RIGHT_CTRL1.1 (COL), RIGHT_SHIFT1.1 (COL)
unnamed: BACKSPACE1.2 (SW_DIODE), BACKSPACE1.3 (DIODE_SW)
unnamed: BACKSPACE1.4 (ROW), DB25.8, HOME1.4 (ROW), INSERT1.4 (ROW), KEY_0.4 (ROW), KEY_7.4 (ROW), KEY_8.4 (ROW), KEY_9.4 (ROW), KEY_EQUALS1.4 (ROW), KEY_MINUS1.4 (ROW), PAGE_UP1.4 (ROW)
unnamed: BACKSPACE1.5 (VCC), DB25.24, DELETE1.5 (VCC), DOWN1.5 (VCC), END1.5 (VCC), ENTER1.5 (VCC), F6.5 (VCC), F7.5 (VCC), F8.5 (VCC), F9.5 (VCC), F10.5 (VCC), F11.5 (VCC), F12.5 (VCC), HOME1.5 (VCC), INSERT1.5 (VCC), KEY_0.5 (VCC), KEY_7.5 (VCC), KEY_8.5 (VCC), KEY_9.5 (VCC), KEY_BACKSLASH1.5 (VCC), KEY_COMMA1.5 (VCC), KEY_EQUALS1.5 (VCC), KEY_FORWARD_SLASH1.5 (VCC), KEY_H1.5 (VCC), KEY_I1.5 (VCC), KEY_J1.5 (VCC), KEY_K1.5 (VCC), KEY_L1.5 (VCC), KEY_LEFT_BRACE1.5 (VCC), KEY_M1.5 (VCC), KEY_MINUS1.5 (VCC), KEY_N1.5 (VCC), KEY_O1.5 (VCC), KEY_P1.5 (VCC), KEY_PERIOD1.5 (VCC), KEY_QUOTE1.5 (VCC), KEY_RIGHT_BRACE1.5 (VCC), KEY_SEMICOLON1.5 (VCC), KEY_U1.5 (VCC), KEY_Y1.5 (VCC), LEFT1.5 (VCC), N1.5 (VCC), N2.5 (VCC), N3.5 (VCC), N4.5 (VCC), NUM_0.5 (VCC), NUM_1.5 (VCC), NUM_2.5 (VCC), NUM_3.5 (VCC), NUM_4.5 (VCC), NUM_5.5 (VCC), NUM_6.5 (VCC), NUM_7.5 (VCC), NUM_8.5 (VCC), NUM_9.5 (VCC), NUM_ASTERIK1.5 (VCC), NUM_ENTER1.5 (VCC), NUM_LOCK1.5 (VCC), NUM_MINUS1.5 (VCC), NUM_PERIOD1.5 (VCC), NUM_PLUS1.5 (VCC), NUM_SLASH1.5 (VCC), PAGE_DOWN1.5 (VCC), PAGE_UP1.5 (VCC), PAUSE1.5 (VCC), PRINT_SCREEN1.5 (VCC), RIGHT1.5 (VCC), RIGHT_ALT1.5 (VCC), RIGHT_CTRL1.5 (VCC), RIGHT_HYPER1.5 (VCC), RIGHT_MENU1.5 (VCC), RIGHT_SHIFT1.5 (VCC), RIGHT_SPACE1.5 (VCC), RIGHT_WIN1.5 (VCC), SCROLL_LOCK1.5 (VCC), UP1.5 (VCC)
unnamed: BACKSPACE1.6 (RES_LED), BACKSPACE1.7 (LED_RES)
unnamed: BACKSPACE1.8 (GND), DB25.25, DELETE1.8 (GND), DOWN1.8 (GND), END1.8 (GND), ENTER1.8 (GND), F6.8 (GND), F7.8 (GND), F8.8 (GND), F9.8 (GND), F10.8 (GND), F11.8 (GND), F12.8 (GND), HOME1.8 (GND), INSERT1.8 (GND), KEY_0.8 (GND), KEY_7.8 (GND), KEY_8.8 (GND), KEY_9.8 (GND), KEY_BACKSLASH1.8 (GND), KEY_COMMA1.8 (GND), KEY_EQUALS1.8 (GND), KEY_FORWARD_SLASH1.8 (GND), KEY_H1.8 (GND), KEY_I1.8 (GND), KEY_J1.8 (GND), KEY_K1.8 (GND), KEY_L1.8 (GND), KEY_LEFT_BRACE1.8 (GND), KEY_M1.8 (GND), KEY_MINUS1.8 (GND), KEY_N1.8 (GND), KEY_O1.8 (GND), KEY_P1.8 (GND), KEY_PERIOD1.8 (GND), KEY_QUOTE1.8 (GND), KEY_RIGHT_BRACE1.8 (GND), KEY_SEMICOLON1.8 (GND), KEY_U1.8 (GND), KEY_Y1.8 (GND), LEFT1.8 (GND), N1.8 (GND), N2.8 (GND), N3.8 (GND), N4.8 (GND), NUM_0.8 (GND), NUM_1.8 (GND), NUM_2.8 (GND), NUM_3.8 (GND), NUM_4.8 (GND), NUM_5.8 (GND), NUM_6.8 (GND), NUM_7.8 (GND), NUM_8.8 (GND), NUM_9.8 (GND), NUM_ASTERIK1.8 (GND), NUM_ENTER1.8 (GND), NUM_LOCK1.8 (GND), NUM_MINUS1.8 (GND), NUM_PERIOD1.8 (GND), NUM_PLUS1.8 (GND), NUM_SLASH1.8 (GND), PAGE_DOWN1.8 (GND), PAGE_UP1.8 (GND), PAUSE1.8 (GND), PRINT_SCREEN1.8 (GND), RIGHT1.8 (GND), RIGHT_ALT1.8 (GND), RIGHT_CTRL1.8 (GND), RIGHT_HYPER1.8 (GND), RIGHT_MENU1.8 (GND), RIGHT_SHIFT1.8 (GND), RIGHT_SPACE1.8 (GND), RIGHT_WIN1.8 (GND), SCROLL_LOCK1.8 (GND), UP1.8 (GND)
unnamed: DB25.1, N1.4 (ROW), N2.4 (ROW), N3.4 (ROW), N4.4 (ROW)
unnamed: DB25.2, NUM_ASTERIK1.4 (ROW), NUM_LOCK1.4 (ROW), NUM_MINUS1.4 (ROW), NUM_SLASH1.4 (ROW)
unnamed: DB25.3, NUM_7.4 (ROW), NUM_8.4 (ROW), NUM_9.4 (ROW), NUM_PLUS1.4 (ROW)
unnamed: DB25.4, NUM_4.4 (ROW), NUM_5.4 (ROW), NUM_6.4 (ROW)
unnamed: DB25.5, NUM_1.4 (ROW), NUM_2.4 (ROW), NUM_3.4 (ROW), NUM_ENTER1.4 (ROW)
unnamed: DB25.6, NUM_0.4 (ROW), NUM_PERIOD1.4 (ROW)
unnamed: DB25.7, F6.4 (ROW), F7.4 (ROW), F8.4 (ROW), F9.4 (ROW), F10.4 (ROW), F11.4 (ROW), F12.4 (ROW), PAUSE1.4 (ROW), PRINT_SCREEN1.4 (ROW), SCROLL_LOCK1.4 (ROW)
unnamed: DB25.9, DELETE1.4 (ROW), END1.4 (ROW), KEY_BACKSLASH1.4 (ROW), KEY_I1.4 (ROW), KEY_LEFT_BRACE1.4 (ROW), KEY_O1.4 (ROW), KEY_P1.4 (ROW), KEY_RIGHT_BRACE1.4 (ROW), KEY_U1.4 (ROW), KEY_Y1.4 (ROW), PAGE_DOWN1.4 (ROW)
unnamed: DB25.10, ENTER1.4 (ROW), KEY_H1.4 (ROW), KEY_J1.4 (ROW), KEY_K1.4 (ROW), KEY_L1.4 (ROW), KEY_QUOTE1.4 (ROW), KEY_SEMICOLON1.4 (ROW)
unnamed: DB25.11, KEY_COMMA1.4 (ROW), KEY_FORWARD_SLASH1.4 (ROW), KEY_M1.4 (ROW), KEY_N1.4 (ROW), KEY_PERIOD1.4 (ROW), RIGHT_SHIFT1.4 (ROW), UP1.4 (ROW)
unnamed: DB25.12, DOWN1.4 (ROW), LEFT1.4 (ROW), RIGHT1.4 (ROW), RIGHT_ALT1.4 (ROW), RIGHT_CTRL1.4 (ROW), RIGHT_HYPER1.4 (ROW), RIGHT_MENU1.4 (ROW), RIGHT_SPACE1.4 (ROW), RIGHT_WIN1.4 (ROW)
unnamed: DB25.13, KEY_Y1.1 (COL)
unnamed: DB25.14, F6.1 (COL), KEY_7.1 (COL), KEY_H1.1 (COL), KEY_U1.1 (COL)
unnamed: DB25.15, F7.1 (COL), KEY_8.1 (COL), KEY_I1.1 (COL), KEY_J1.1 (COL), KEY_N1.1 (COL), RIGHT_SPACE1.1 (COL)
unnamed: DB25.16, F8.1 (COL), KEY_9.1 (COL), KEY_K1.1 (COL), KEY_M1.1 (COL), KEY_O1.1 (COL), RIGHT_HYPER1.1 (COL)
unnamed: DB25.17, F9.1 (COL), KEY_0.1 (COL), KEY_COMMA1.1 (COL), KEY_L1.1 (COL), KEY_P1.1 (COL), RIGHT_ALT1.1 (COL)
unnamed: DB25.18, F10.1 (COL), KEY_LEFT_BRACE1.1 (COL), KEY_MINUS1.1 (COL), KEY_PERIOD1.1 (COL), KEY_SEMICOLON1.1 (COL), RIGHT_WIN1.1 (COL)
unnamed: DB25.19, F11.1 (COL), KEY_EQUALS1.1 (COL), KEY_FORWARD_SLASH1.1 (COL), KEY_QUOTE1.1 (COL), KEY_RIGHT_BRACE1.1 (COL), RIGHT_MENU1.1 (COL)
unnamed: DB25.21, DELETE1.1 (COL), INSERT1.1 (COL), LEFT1.1 (COL), N2.1 (COL), NUM_2.1 (COL), NUM_5.1 (COL), NUM_8.1 (COL), NUM_SLASH1.1 (COL), PRINT_SCREEN1.1 (COL)
unnamed: DB25.22, DOWN1.1 (COL), END1.1 (COL), HOME1.1 (COL), N3.1 (COL), NUM_3.1 (COL), NUM_6.1 (COL), NUM_9.1 (COL), NUM_ASTERIK1.1 (COL), NUM_PERIOD1.1 (COL), SCROLL_LOCK1.1 (COL), UP1.1 (COL)
unnamed: DB25.23, N4.1 (COL), NUM_ENTER1.1 (COL), NUM_MINUS1.1 (COL), NUM_PLUS1.1 (COL), PAGE_DOWN1.1 (COL), PAGE_UP1.1 (COL), PAUSE1.1 (COL), RIGHT1.1 (COL)
unnamed: DELETE1.2 (SW_DIODE), DELETE1.3 (DIODE_SW)
unnamed: DELETE1.6 (RES_LED), DELETE1.7 (LED_RES)
unnamed: DOWN1.2 (SW_DIODE), DOWN1.3 (DIODE_SW)
unnamed: DOWN1.6 (RES_LED), DOWN1.7 (LED_RES)
unnamed: END1.2 (SW_DIODE), END1.3 (DIODE_SW)
unnamed: END1.6 (RES_LED), END1.7 (LED_RES)
unnamed: ENTER1.2 (SW_DIODE), ENTER1.3 (DIODE_SW)
unnamed: ENTER1.6 (RES_LED), ENTER1.7 (LED_RES)
unnamed: F6.2 (SW_DIODE), F6.3 (DIODE_SW)
unnamed: F6.6 (RES_LED), F6.7 (LED_RES)
unnamed: F7.2 (SW_DIODE), F7.3 (DIODE_SW)
unnamed: F7.6 (RES_LED), F7.7 (LED_RES)
unnamed: F8.2 (SW_DIODE), F8.3 (DIODE_SW)
unnamed: F8.6 (RES_LED), F8.7 (LED_RES)
unnamed: F9.2 (SW_DIODE), F9.3 (DIODE_SW)
unnamed: F9.6 (RES_LED), F9.7 (LED_RES)
unnamed: F10.2 (SW_DIODE), F10.3 (DIODE_SW)
unnamed: F10.6 (RES_LED), F10.7 (LED_RES)
unnamed: F11.2 (SW_DIODE), F11.3 (DIODE_SW)
unnamed: F11.6 (RES_LED), F11.7 (LED_RES)
unnamed: F12.2 (SW_DIODE), F12.3 (DIODE_SW)
unnamed: F12.6 (RES_LED), F12.7 (LED_RES)
unnamed: HOME1.2 (SW_DIODE), HOME1.3 (DIODE_SW)
unnamed: HOME1.6 (RES_LED), HOME1.7 (LED_RES)
unnamed: INSERT1.2 (SW_DIODE), INSERT1.3 (DIODE_SW)
unnamed: INSERT1.6 (RES_LED), INSERT1.7 (LED_RES)
unnamed: KEY_0.2 (SW_DIODE), KEY_0.3 (DIODE_SW)
unnamed: KEY_0.6 (RES_LED), KEY_0.7 (LED_RES)
unnamed: KEY_7.2 (SW_DIODE), KEY_7.3 (DIODE_SW)
unnamed: KEY_7.6 (RES_LED), KEY_7.7 (LED_RES)
unnamed: KEY_8.2 (SW_DIODE), KEY_8.3 (DIODE_SW)
unnamed: KEY_8.6 (RES_LED), KEY_8.7 (LED_RES)
unnamed: KEY_9.2 (SW_DIODE), KEY_9.3 (DIODE_SW)
unnamed: KEY_9.6 (RES_LED), KEY_9.7 (LED_RES)
unnamed: KEY_BACKSLASH1.2 (SW_DIODE), KEY_BACKSLASH1.3 (DIODE_SW)
unnamed: KEY_BACKSLASH1.6 (RES_LED), KEY_BACKSLASH1.7 (LED_RES)
unnamed: KEY_COMMA1.2 (SW_DIODE), KEY_COMMA1.3 (DIODE_SW)
unnamed: KEY_COMMA1.6 (RES_LED), KEY_COMMA1.7 (LED_RES)
unnamed: KEY_EQUALS1.2 (SW_DIODE), KEY_EQUALS1.3 (DIODE_SW)
unnamed: KEY_EQUALS1.6 (RES_LED), KEY_EQUALS1.7 (LED_RES)
unnamed: KEY_FORWARD_SLASH1.2 (SW_DIODE), KEY_FORWARD_SLASH1.3 (DIODE_SW)
unnamed: KEY_FORWARD_SLASH1.6 (RES_LED), KEY_FORWARD_SLASH1.7 (LED_RES)
unnamed: KEY_H1.2 (SW_DIODE), KEY_H1.3 (DIODE_SW)
unnamed: KEY_H1.6 (RES_LED), KEY_H1.7 (LED_RES)
unnamed: KEY_I1.2 (SW_DIODE), KEY_I1.3 (DIODE_SW)
unnamed: KEY_I1.6 (RES_LED), KEY_I1.7 (LED_RES)
unnamed: KEY_J1.2 (SW_DIODE), KEY_J1.3 (DIODE_SW)
unnamed: KEY_J1.6 (RES_LED), KEY_J1.7 (LED_RES)
unnamed: KEY_K1.2 (SW_DIODE), KEY_K1.3 (DIODE_SW)
unnamed: KEY_K1.6 (RES_LED), KEY_K1.7 (LED_RES)
unnamed: KEY_L1.2 (SW_DIODE), KEY_L1.3 (DIODE_SW)
unnamed: KEY_L1.6 (RES_LED), KEY_L1.7 (LED_RES)
unnamed: KEY_LEFT_BRACE1.2 (SW_DIODE), KEY_LEFT_BRACE1.3 (DIODE_SW)
unnamed: KEY_LEFT_BRACE1.6 (RES_LED), KEY_LEFT_BRACE1.7 (LED_RES)
unnamed: KEY_M1.2 (SW_DIODE), KEY_M1.3 (DIODE_SW)
unnamed: KEY_M1.6 (RES_LED), KEY_M1.7 (LED_RES)
unnamed: KEY_MINUS1.2 (SW_DIODE), KEY_MINUS1.3 (DIODE_SW)
unnamed: KEY_MINUS1.6 (RES_LED), KEY_MINUS1.7 (LED_RES)
unnamed: KEY_N1.2 (SW_DIODE), KEY_N1.3 (DIODE_SW)
unnamed: KEY_N1.6 (RES_LED), KEY_N1.7 (LED_RES)
unnamed: KEY_O1.2 (SW_DIODE), KEY_O1.3 (DIODE_SW)
unnamed: KEY_O1.6 (RES_LED), KEY_O1.7 (LED_RES)
unnamed: KEY_P1.2 (SW_DIODE), KEY_P1.3 (DIODE_SW)
unnamed: KEY_P1.6 (RES_LED), KEY_P1.7 (LED_RES)
unnamed: KEY_PERIOD1.2 (SW_DIODE), KEY_PERIOD1.3 (DIODE_SW)
unnamed: KEY_PERIOD1.6 (RES_LED), KEY_PERIOD1.7 (LED_RES)
unnamed: KEY_QUOTE1.2 (SW_DIODE), KEY_QUOTE1.3 (DIODE_SW)
unnamed: KEY_QUOTE1.6 (RES_LED), KEY_QUOTE1.7 (LED_RES)
unnamed: KEY_RIGHT_BRACE1.2 (SW_DIODE), KEY_RIGHT_BRACE1.3 (DIODE_SW)
unnamed: KEY_RIGHT_BRACE1.6 (RES_LED), KEY_RIGHT_BRACE1.7 (LED_RES)
unnamed: KEY_SEMICOLON1.2 (SW_DIODE), KEY_SEMICOLON1.3 (DIODE_SW)
unnamed: KEY_SEMICOLON1.6 (RES_LED), KEY_SEMICOLON1.7 (LED_RES)
unnamed: KEY_U1.2 (SW_DIODE), KEY_U1.3 (DIODE_SW)
unnamed: KEY_U1.6 (RES_LED), KEY_U1.7 (LED_RES)
unnamed: KEY_Y1.2 (SW_DIODE), KEY_Y1.3 (DIODE_SW)
unnamed: KEY_Y1.6 (RES_LED), KEY_Y1.7 (LED_RES)
unnamed: LEFT1.2 (SW_DIODE), LEFT1.3 (DIODE_SW)
unnamed: LEFT1.6 (RES_LED), LEFT1.7 (LED_RES)
unnamed: N1.2 (SW_DIODE), N1.3 (DIODE_SW)
unnamed: N1.6 (RES_LED), N1.7 (LED_RES)
unnamed: N2.2 (SW_DIODE), N2.3 (DIODE_SW)
unnamed: N2.6 (RES_LED), N2.7 (LED_RES)
unnamed: N3.2 (SW_DIODE), N3.3 (DIODE_SW)
unnamed: N3.6 (RES_LED), N3.7 (LED_RES)
unnamed: N4.2 (SW_DIODE), N4.3 (DIODE_SW)
unnamed: N4.6 (RES_LED), N4.7 (LED_RES)
unnamed: NUM_0.2 (SW_DIODE), NUM_0.3 (DIODE_SW)
unnamed: NUM_0.6 (RES_LED), NUM_0.7 (LED_RES)
unnamed: NUM_1.2 (SW_DIODE), NUM_1.3 (DIODE_SW)
unnamed: NUM_1.6 (RES_LED), NUM_1.7 (LED_RES)
unnamed: NUM_2.2 (SW_DIODE), NUM_2.3 (DIODE_SW)
unnamed: NUM_2.6 (RES_LED), NUM_2.7 (LED_RES)
unnamed: NUM_3.2 (SW_DIODE), NUM_3.3 (DIODE_SW)
unnamed: NUM_3.6 (RES_LED), NUM_3.7 (LED_RES)
unnamed: NUM_4.2 (SW_DIODE), NUM_4.3 (DIODE_SW)
unnamed: NUM_4.6 (RES_LED), NUM_4.7 (LED_RES)
unnamed: NUM_5.2 (SW_DIODE), NUM_5.3 (DIODE_SW)
unnamed: NUM_5.6 (RES_LED), NUM_5.7 (LED_RES)
unnamed: NUM_6.2 (SW_DIODE), NUM_6.3 (DIODE_SW)
unnamed: NUM_6.6 (RES_LED), NUM_6.7 (LED_RES)
unnamed: NUM_7.2 (SW_DIODE), NUM_7.3 (DIODE_SW)
unnamed: NUM_7.6 (RES_LED), NUM_7.7 (LED_RES)
unnamed: NUM_8.2 (SW_DIODE), NUM_8.3 (DIODE_SW)
unnamed: NUM_8.6 (RES_LED), NUM_8.7 (LED_RES)
unnamed: NUM_9.2 (SW_DIODE), NUM_9.3 (DIODE_SW)
unnamed: NUM_9.6 (RES_LED), NUM_9.7 (LED_RES)
unnamed: NUM_ASTERIK1.2 (SW_DIODE), NUM_ASTERIK1.3 (DIODE_SW)
unnamed: NUM_ASTERIK1.6 (RES_LED), NUM_ASTERIK1.7 (LED_RES)
unnamed: NUM_ENTER1.2 (SW_DIODE), NUM_ENTER1.3 (DIODE_SW)
unnamed: NUM_ENTER1.6 (RES_LED), NUM_ENTER1.7 (LED_RES)
unnamed: NUM_LOCK1.2 (SW_DIODE), NUM_LOCK1.3 (DIODE_SW)
unnamed: NUM_LOCK1.6 (RES_LED), NUM_LOCK1.7 (LED_RES)
unnamed: NUM_MINUS1.2 (SW_DIODE), NUM_MINUS1.3 (DIODE_SW)
unnamed: NUM_MINUS1.6 (RES_LED), NUM_MINUS1.7 (LED_RES)
unnamed: NUM_PERIOD1.2 (SW_DIODE), NUM_PERIOD1.3 (DIODE_SW)
unnamed: NUM_PERIOD1.6 (RES_LED), NUM_PERIOD1.7 (LED_RES)
unnamed: NUM_PLUS1.2 (SW_DIODE), NUM_PLUS1.3 (DIODE_SW)
unnamed: NUM_PLUS1.6 (RES_LED), NUM_PLUS1.7 (LED_RES)
unnamed: NUM_SLASH1.2 (SW_DIODE), NUM_SLASH1.3 (DIODE_SW)
unnamed: NUM_SLASH1.6 (RES_LED), NUM_SLASH1.7 (LED_RES)
unnamed: PAGE_DOWN1.2 (SW_DIODE), PAGE_DOWN1.3 (DIODE_SW)
unnamed: PAGE_DOWN1.6 (RES_LED), PAGE_DOWN1.7 (LED_RES)
unnamed: PAGE_UP1.2 (SW_DIODE), PAGE_UP1.3 (DIODE_SW)
unnamed: PAGE_UP1.6 (RES_LED), PAGE_UP1.7 (LED_RES)
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

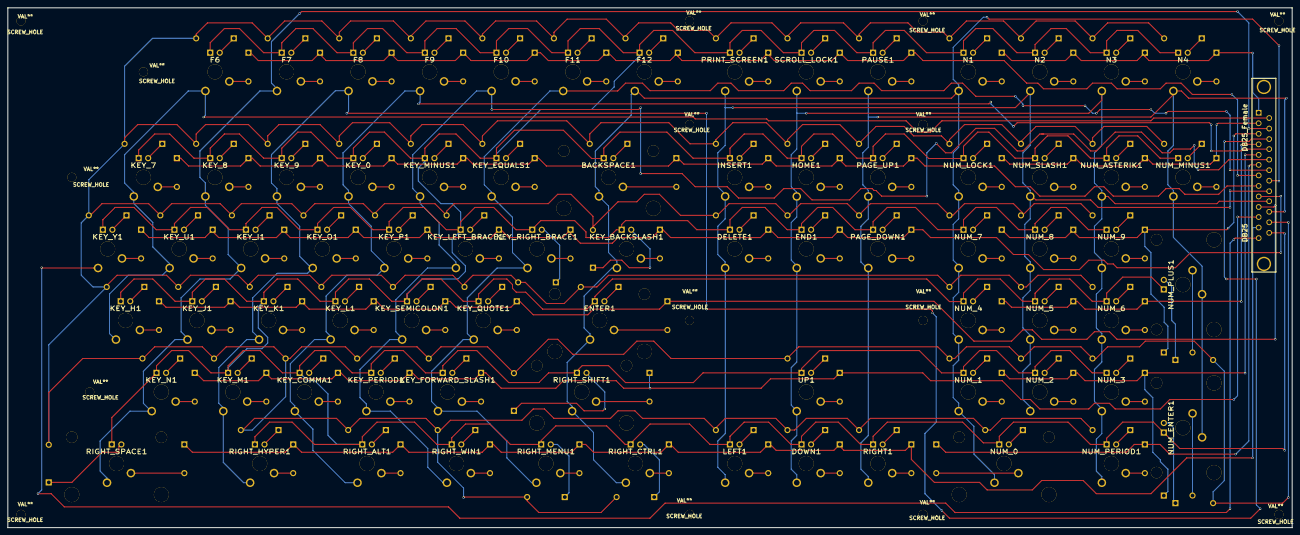
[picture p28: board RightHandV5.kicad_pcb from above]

Board: 2 copper layers, 341.0 x 138.0 mm, 91 parts (0 on the bottom side), 175 nets.

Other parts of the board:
SCREW_HOLE: VAL**; SCREW_HOLE
SCREW_HOLE#2, SCREW_HOLE#3, SCREW_HOLE#4, SCREW_HOLE#5, SCREW_HOLE#6, SCREW_HOLE#7, SCREW_HOLE#8, SCREW_HOLE#9, SCREW_HOLE#10, SCREW_HOLE#11, SCREW_HOLE#12, SCREW_HOLE#13, SCREW_HOLE#14, SCREW_HOLE#15: VAL**; SCREW_HOLE

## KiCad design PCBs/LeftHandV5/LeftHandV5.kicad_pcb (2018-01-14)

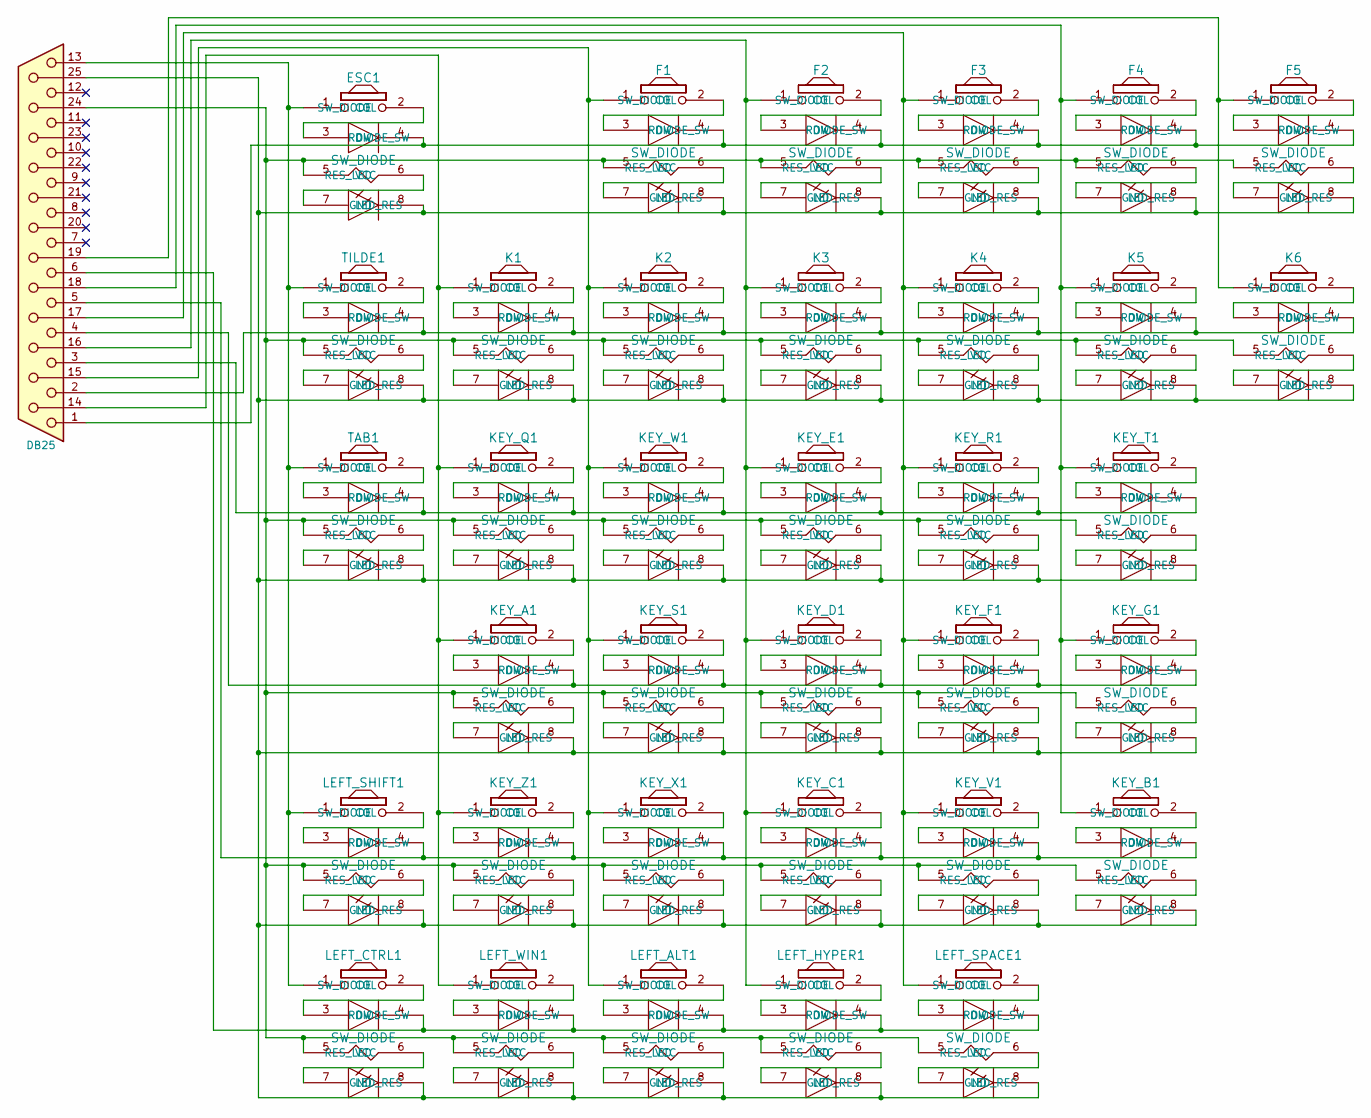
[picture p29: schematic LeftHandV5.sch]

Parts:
DB25: DB25_Female; DB25FD
ESC1: SW_DIODE
F1, F2, F3, F4, F5: SW_DIODE
K1, K2, K3, K4, K5, K6: SW_DIODE
KEY_A1: SW_DIODE
KEY_B1: SW_DIODE
KEY_C1: SW_DIODE
KEY_D1: SW_DIODE
KEY_E1: SW_DIODE
KEY_F1: SW_DIODE
KEY_G1: SW_DIODE
KEY_Q1: SW_DIODE
KEY_R1: SW_DIODE
KEY_S1: SW_DIODE
KEY_T1: SW_DIODE
KEY_V1: SW_DIODE
KEY_W1: SW_DIODE
KEY_X1: SW_DIODE
KEY_Z1: SW_DIODE
LEFT_ALT1: SW_DIODE
LEFT_CTRL1: SW_DIODE; SW_DIODE_RTOP
LEFT_HYPER1: SW_DIODE
LEFT_SHIFT1: SW_DIODE; SW2_DIODE_L
LEFT_SPACE1: SW_DIODE; SW2_DIODE_L
LEFT_WIN1: SW_DIODE; SW_DIODE_RTOP
TAB1: SW_DIODE
TILDE1: SW_DIODE

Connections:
unnamed: DB25.1, ESC1.4 (ROW), F1.4 (ROW), F2.4 (ROW), F3.4 (ROW), F4.4 (ROW), F5.4 (ROW)
unnamed: DB25.2, K1.4 (ROW), K2.4 (ROW), K3.4 (ROW), K4.4 (ROW), K5.4 (ROW), K6.4 (ROW), TILDE1.4 (ROW)
unnamed: DB25.3, KEY_E1.4 (ROW), KEY_Q1.4 (ROW), KEY_R1.4 (ROW), KEY_T1.4 (ROW), KEY_W1.4 (ROW), TAB1.4 (ROW)
unnamed: DB25.4, KEY_A1.4 (ROW), KEY_D1.4 (ROW), KEY_F1.4 (ROW), KEY_G1.4 (ROW), KEY_S1.4 (ROW)
unnamed: DB25.5, KEY_B1.4 (ROW), KEY_C1.4 (ROW), KEY_V1.4 (ROW), KEY_X1.4 (ROW), KEY_Z1.4 (ROW), LEFT_SHIFT1.4 (ROW)
unnamed: DB25.6, LEFT_ALT1.4 (ROW), LEFT_CTRL1.4 (ROW), LEFT_HYPER1.4 (ROW), LEFT_SPACE1.4 (ROW), LEFT_WIN1.4 (ROW)
unnamed: DB25.13, ESC1.1 (COL), LEFT_CTRL1.1 (COL), LEFT_SHIFT1.1 (COL), TAB1.1 (COL), TILDE1.1 (COL)
unnamed: DB25.14, K1.1 (COL), KEY_A1.1 (COL), KEY_Q1.1 (COL), KEY_Z1.1 (COL), LEFT_WIN1.1 (COL)
unnamed: DB25.15, F1.1 (COL), K2.1 (COL), KEY_S1.1 (COL), KEY_W1.1 (COL), KEY_X1.1 (COL), LEFT_ALT1.1 (COL)
unnamed: DB25.16, F2.1 (COL), K3.1 (COL), KEY_C1.1 (COL), KEY_D1.1 (COL), KEY_E1.1 (COL), LEFT_HYPER1.1 (COL)
unnamed: DB25.17, F3.1 (COL), K4.1 (COL), KEY_F1.1 (COL), KEY_R1.1 (COL), KEY_V1.1 (COL), LEFT_SPACE1.1 (COL)
unnamed: DB25.18, F4.1 (COL), K5.1 (COL), KEY_B1.1 (COL), KEY_G1.1 (COL), KEY_T1.1 (COL)
unnamed: DB25.19, F5.1 (COL), K6.1 (COL)
unnamed: DB25.24, ESC1.5 (VCC), F1.5 (VCC), F2.5 (VCC), F3.5 (VCC), F4.5 (VCC), F5.5 (VCC), K1.5 (VCC), K2.5 (VCC), K3.5 (VCC), K4.5 (VCC), K5.5 (VCC), K6.5 (VCC), KEY_A1.5 (VCC), KEY_B1.5 (VCC), KEY_C1.5 (VCC), KEY_D1.5 (VCC), KEY_E1.5 (VCC), KEY_F1.5 (VCC), KEY_G1.5 (VCC), KEY_Q1.5 (VCC), KEY_R1.5 (VCC), KEY_S1.5 (VCC), KEY_T1.5 (VCC), KEY_V1.5 (VCC), KEY_W1.5 (VCC), KEY_X1.5 (VCC), KEY_Z1.5 (VCC), LEFT_ALT1.5 (VCC), LEFT_CTRL1.5 (VCC), LEFT_HYPER1.5 (VCC), LEFT_SHIFT1.5 (VCC), LEFT_SPACE1.5 (VCC), LEFT_WIN1.5 (VCC), TAB1.5 (VCC), TILDE1.5 (VCC)
unnamed: DB25.25, ESC1.8 (GND), F1.8 (GND), F2.8 (GND), F3.8 (GND), F4.8 (GND), F5.8 (GND), K1.8 (GND), K2.8 (GND), K3.8 (GND), K4.8 (GND), K5.8 (GND), K6.8 (GND), KEY_A1.8 (GND), KEY_B1.8 (GND), KEY_C1.8 (GND), KEY_D1.8 (GND), KEY_E1.8 (GND), KEY_F1.8 (GND), KEY_G1.8 (GND), KEY_Q1.8 (GND), KEY_R1.8 (GND), KEY_S1.8 (GND), KEY_T1.8 (GND), KEY_V1.8 (GND), KEY_W1.8 (GND), KEY_X1.8 (GND), KEY_Z1.8 (GND), LEFT_ALT1.8 (GND), LEFT_CTRL1.8 (GND), LEFT_HYPER1.8 (GND), LEFT_SHIFT1.8 (GND), LEFT_SPACE1.8 (GND), LEFT_WIN1.8 (GND), TAB1.8 (GND), TILDE1.8 (GND)
unnamed: ESC1.2 (SW_DIODE), ESC1.3 (DIODE_SW)
unnamed: ESC1.6 (RES_LED), ESC1.7 (LED_RES)
unnamed: F1.2 (SW_DIODE), F1.3 (DIODE_SW)
unnamed: F1.6 (RES_LED), F1.7 (LED_RES)
unnamed: F2.2 (SW_DIODE), F2.3 (DIODE_SW)
unnamed: F2.6 (RES_LED), F2.7 (LED_RES)
unnamed: F3.2 (SW_DIODE), F3.3 (DIODE_SW)
unnamed: F3.6 (RES_LED), F3.7 (LED_RES)
unnamed: F4.2 (SW_DIODE), F4.3 (DIODE_SW)
unnamed: F4.6 (RES_LED), F4.7 (LED_RES)
unnamed: F5.2 (SW_DIODE), F5.3 (DIODE_SW)
unnamed: F5.6 (RES_LED), F5.7 (LED_RES)
unnamed: K1.2 (SW_DIODE), K1.3 (DIODE_SW)
unnamed: K1.6 (RES_LED), K1.7 (LED_RES)
unnamed: K2.2 (SW_DIODE), K2.3 (DIODE_SW)
unnamed: K2.6 (RES_LED), K2.7 (LED_RES)
unnamed: K3.2 (SW_DIODE), K3.3 (DIODE_SW)
unnamed: K3.6 (RES_LED), K3.7 (LED_RES)
unnamed: K4.2 (SW_DIODE), K4.3 (DIODE_SW)
unnamed: K4.6 (RES_LED), K4.7 (LED_RES)
unnamed: K5.2 (SW_DIODE), K5.3 (DIODE_SW)
unnamed: K5.6 (RES_LED), K5.7 (LED_RES)
unnamed: K6.2 (SW_DIODE), K6.3 (DIODE_SW)
unnamed: K6.6 (RES_LED), K6.7 (LED_RES)
unnamed: KEY_A1.2 (SW_DIODE), KEY_A1.3 (DIODE_SW)
unnamed: KEY_A1.6 (RES_LED), KEY_A1.7 (LED_RES)
unnamed: KEY_B1.2 (SW_DIODE), KEY_B1.3 (DIODE_SW)
unnamed: KEY_B1.6 (RES_LED), KEY_B1.7 (LED_RES)
unnamed: KEY_C1.2 (SW_DIODE), KEY_C1.3 (DIODE_SW)
unnamed: KEY_C1.6 (RES_LED), KEY_C1.7 (LED_RES)
unnamed: KEY_D1.2 (SW_DIODE), KEY_D1.3 (DIODE_SW)
unnamed: KEY_D1.6 (RES_LED), KEY_D1.7 (LED_RES)
unnamed: KEY_E1.2 (SW_DIODE), KEY_E1.3 (DIODE_SW)
unnamed: KEY_E1.6 (RES_LED), KEY_E1.7 (LED_RES)
unnamed: KEY_F1.2 (SW_DIODE), KEY_F1.3 (DIODE_SW)
unnamed: KEY_F1.6 (RES_LED), KEY_F1.7 (LED_RES)
unnamed: KEY_G1.2 (SW_DIODE), KEY_G1.3 (DIODE_SW)
unnamed: KEY_G1.6 (RES_LED), KEY_G1.7 (LED_RES)
unnamed: KEY_Q1.2 (SW_DIODE), KEY_Q1.3 (DIODE_SW)
unnamed: KEY_Q1.6 (RES_LED), KEY_Q1.7 (LED_RES)
unnamed: KEY_R1.2 (SW_DIODE), KEY_R1.3 (DIODE_SW)
unnamed: KEY_R1.6 (RES_LED), KEY_R1.7 (LED_RES)
unnamed: KEY_S1.2 (SW_DIODE), KEY_S1.3 (DIODE_SW)
unnamed: KEY_S1.6 (RES_LED), KEY_S1.7 (LED_RES)
unnamed: KEY_T1.2 (SW_DIODE), KEY_T1.3 (DIODE_SW)
unnamed: KEY_T1.6 (RES_LED), KEY_T1.7 (LED_RES)
unnamed: KEY_V1.2 (SW_DIODE), KEY_V1.3 (DIODE_SW)
unnamed: KEY_V1.6 (RES_LED), KEY_V1.7 (LED_RES)
unnamed: KEY_W1.2 (SW_DIODE), KEY_W1.3 (DIODE_SW)
unnamed: KEY_W1.6 (RES_LED), KEY_W1.7 (LED_RES)
unnamed: KEY_X1.2 (SW_DIODE), KEY_X1.3 (DIODE_SW)
unnamed: KEY_X1.6 (RES_LED), KEY_X1.7 (LED_RES)
unnamed: KEY_Z1.2 (SW_DIODE), KEY_Z1.3 (DIODE_SW)
unnamed: KEY_Z1.6 (RES_LED), KEY_Z1.7 (LED_RES)
unnamed: LEFT_ALT1.2 (SW_DIODE), LEFT_ALT1.3 (DIODE_SW)
unnamed: LEFT_ALT1.6 (RES_LED), LEFT_ALT1.7 (LED_RES)
unnamed: LEFT_CTRL1.2 (SW_DIODE), LEFT_CTRL1.3 (DIODE_SW)
unnamed: LEFT_CTRL1.6 (RES_LED), LEFT_CTRL1.7 (LED_RES)
unnamed: LEFT_HYPER1.2 (SW_DIODE), LEFT_HYPER1.3 (DIODE_SW)
unnamed: LEFT_HYPER1.6 (RES_LED), LEFT_HYPER1.7 (LED_RES)
unnamed: LEFT_SHIFT1.2 (SW_DIODE), LEFT_SHIFT1.3 (DIODE_SW)
unnamed: LEFT_SHIFT1.6 (RES_LED), LEFT_SHIFT1.7 (LED_RES)
unnamed: LEFT_SPACE1.2 (SW_DIODE), LEFT_SPACE1.3 (DIODE_SW)
unnamed: LEFT_SPACE1.6 (RES_LED), LEFT_SPACE1.7 (LED_RES)
unnamed: LEFT_WIN1.2 (SW_DIODE), LEFT_WIN1.3 (DIODE_SW)
unnamed: LEFT_WIN1.6 (RES_LED), LEFT_WIN1.7 (LED_RES)
unnamed: TAB1.2 (SW_DIODE), TAB1.3 (DIODE_SW)
unnamed: TAB1.6 (RES_LED), TAB1.7 (LED_RES)
unnamed: TILDE1.2 (SW_DIODE), TILDE1.3 (DIODE_SW)
unnamed: TILDE1.6 (RES_LED), TILDE1.7 (LED_RES)

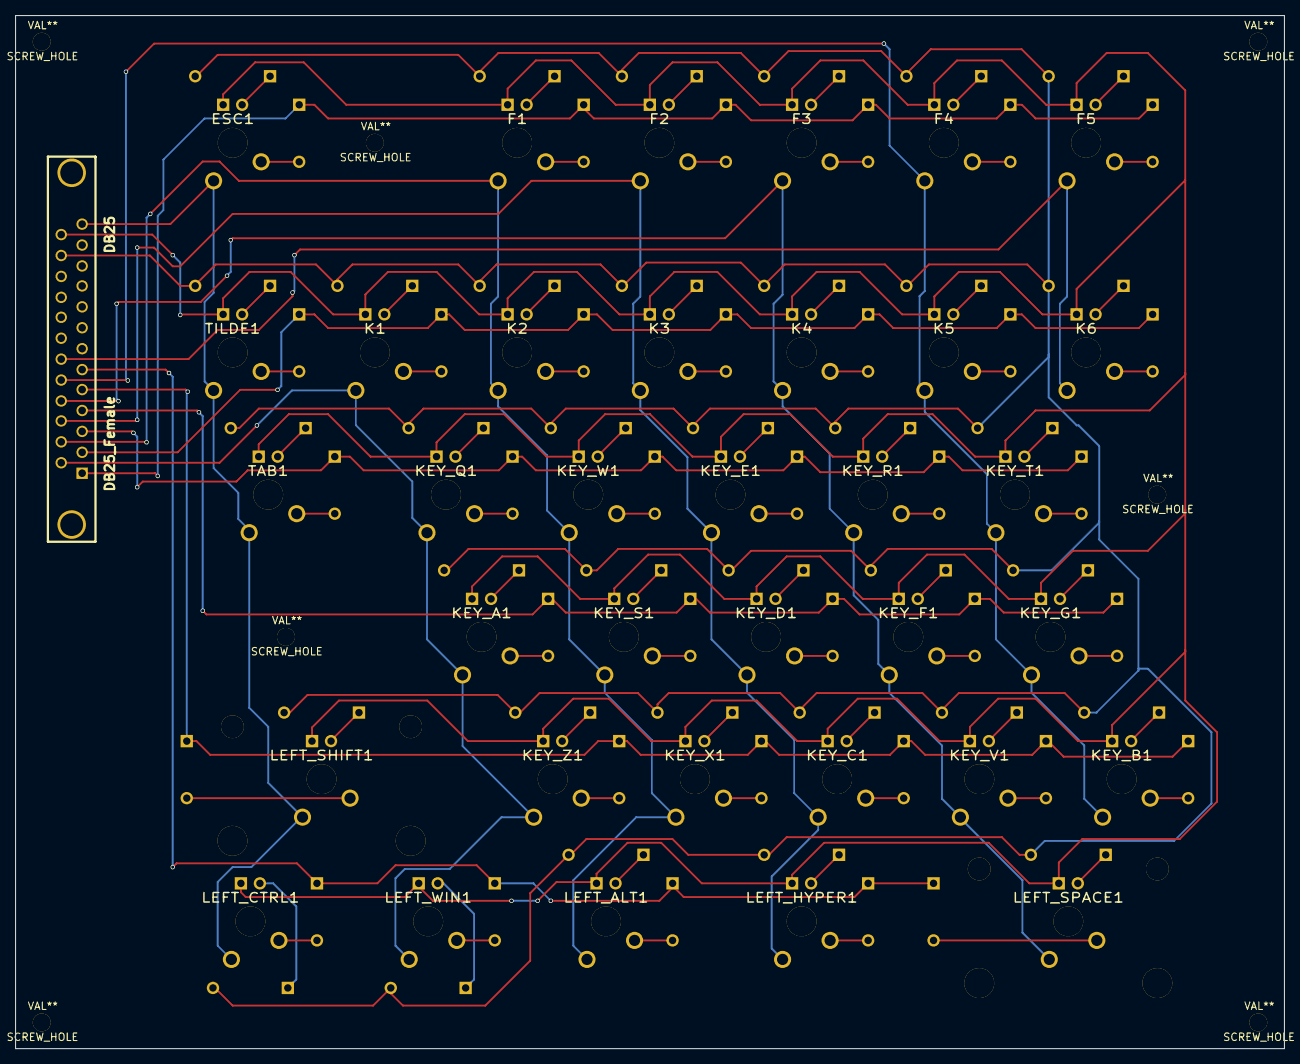
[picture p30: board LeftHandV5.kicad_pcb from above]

Board: 2 copper layers, 169.5 x 138.0 mm, 43 parts (0 on the bottom side), 85 nets.

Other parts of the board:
SCREW_HOLE: VAL**; SCREW_HOLE
SCREW_HOLE#2, SCREW_HOLE#3, SCREW_HOLE#4, SCREW_HOLE#5, SCREW_HOLE#6, SCREW_HOLE#7: VAL**; SCREW_HOLE

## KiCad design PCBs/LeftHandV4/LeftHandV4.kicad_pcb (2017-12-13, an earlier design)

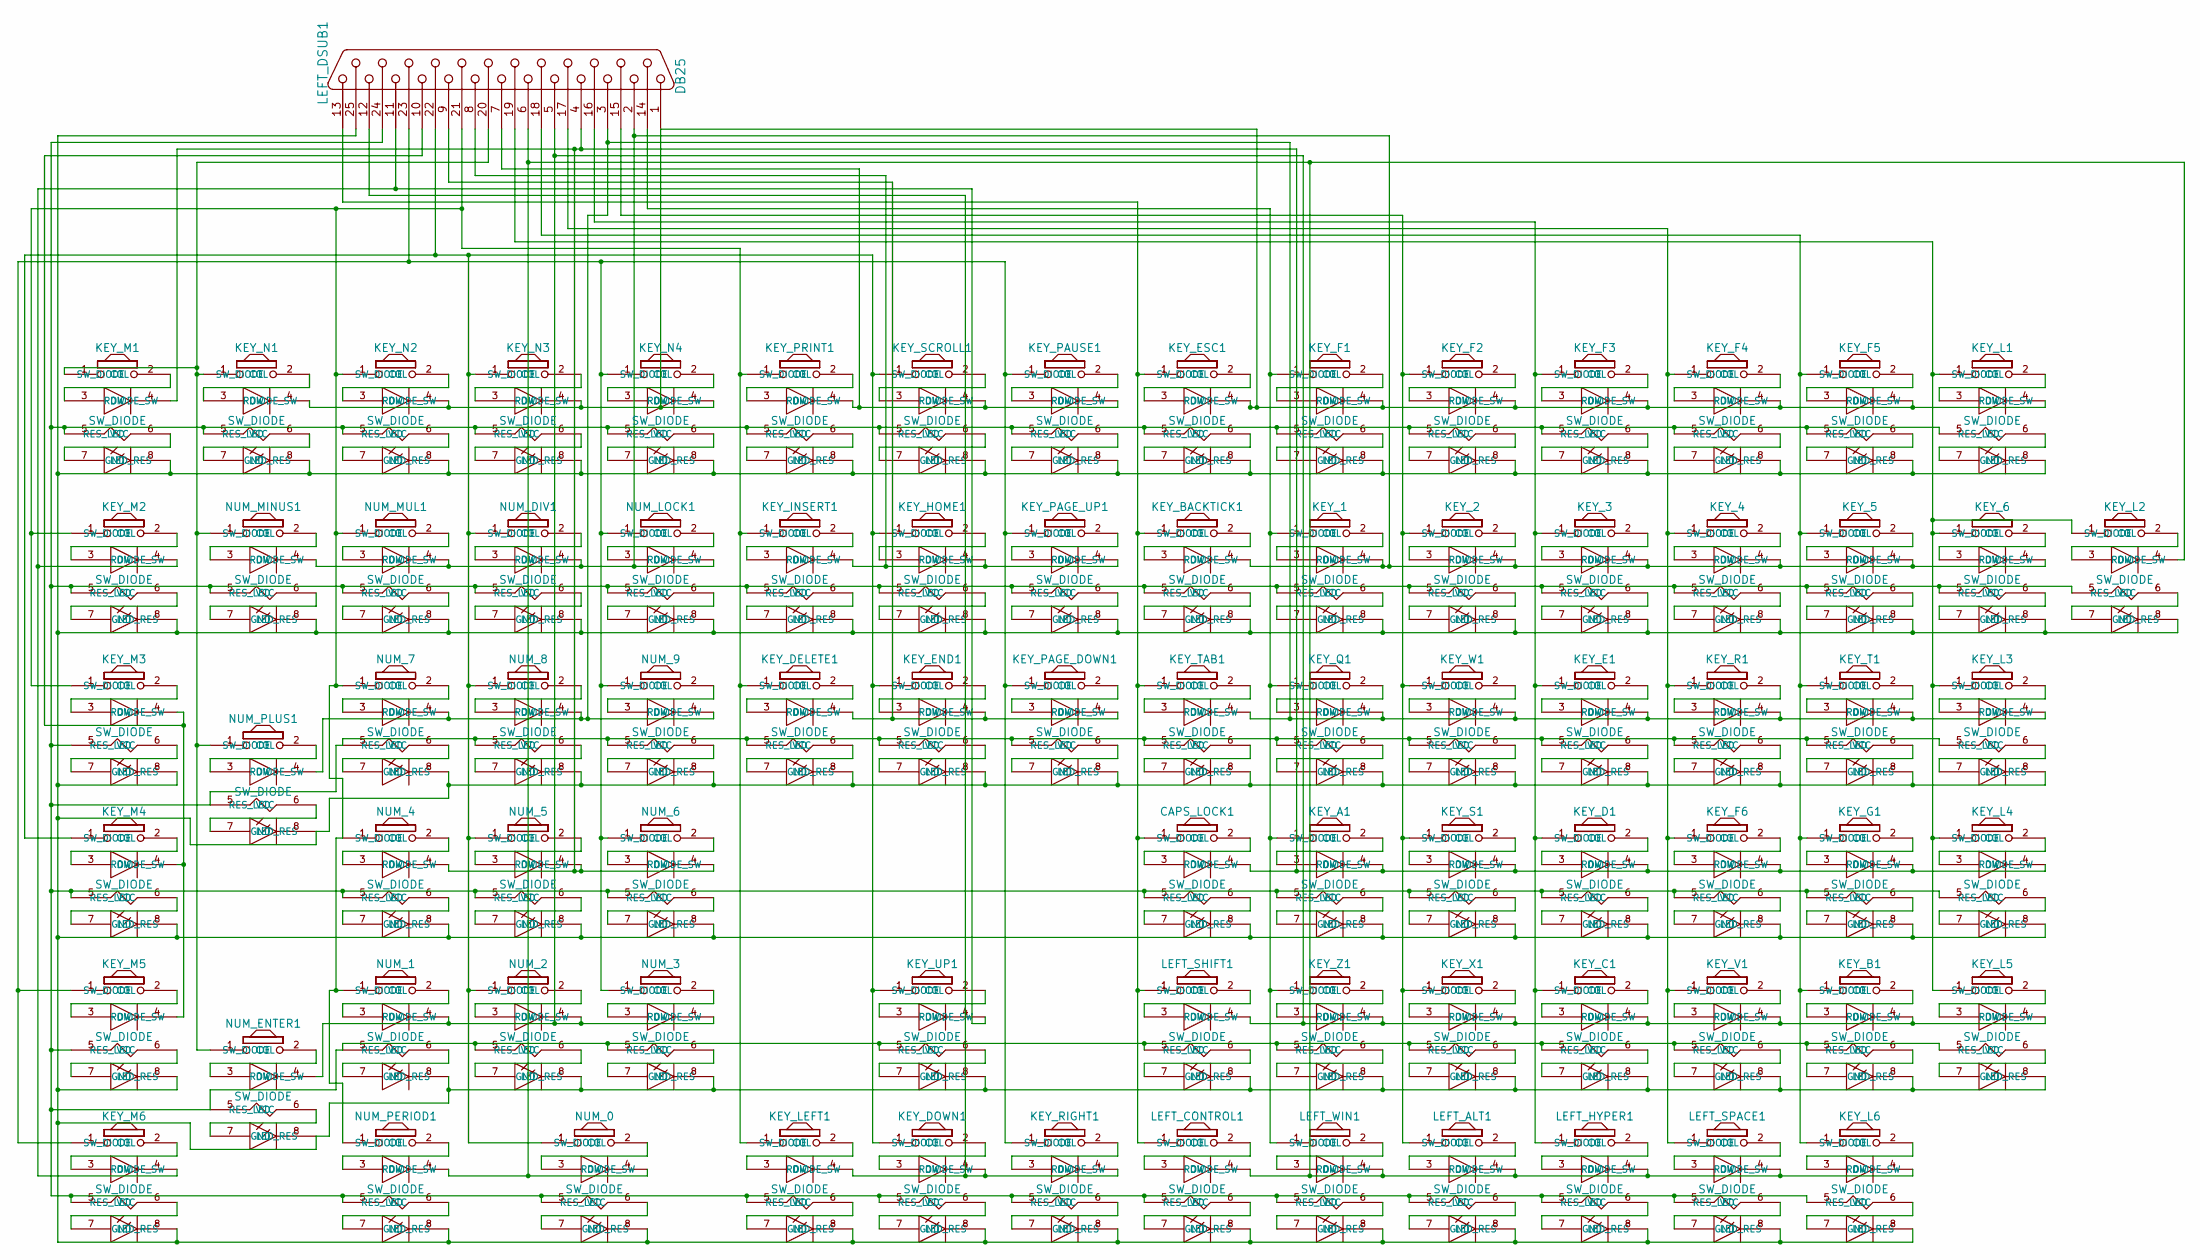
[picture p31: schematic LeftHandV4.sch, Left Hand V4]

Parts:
CAPS_LOCK1: SW_DIODE
KEY_1, KEY_2, KEY_3, KEY_4, KEY_5, KEY_6: SW_DIODE
KEY_A1: SW_DIODE
KEY_B1: SW_DIODE
KEY_BACKTICK1: SW_DIODE
KEY_C1: SW_DIODE
KEY_D1: SW_DIODE
KEY_DELETE1: SW_DIODE
KEY_DOWN1: SW_DIODE
KEY_E1: SW_DIODE
KEY_END1: SW_DIODE
KEY_ESC1: SW_DIODE
KEY_F1, KEY_F2, KEY_F3, KEY_F4, KEY_F5, KEY_F6: SW_DIODE
KEY_G1: SW_DIODE
KEY_HOME1: SW_DIODE
KEY_INSERT1: SW_DIODE
KEY_L1, KEY_L2, KEY_L3, KEY_L4, KEY_L5, KEY_L6: SW_DIODE
KEY_LEFT1: SW_DIODE
KEY_M1, KEY_M2, KEY_M3, KEY_M4, KEY_M5, KEY_M6: SW_DIODE
KEY_N1, KEY_N2, KEY_N3, KEY_N4: SW_DIODE
KEY_PAGE_DOWN1: SW_DIODE
KEY_PAGE_UP1: SW_DIODE
KEY_PAUSE1: SW_DIODE
KEY_PRINT1: SW_DIODE
KEY_Q1: SW_DIODE
KEY_R1: SW_DIODE
KEY_RIGHT1: SW_DIODE
KEY_S1: SW_DIODE
KEY_SCROLL1: SW_DIODE
KEY_T1: SW_DIODE
KEY_TAB1: SW_DIODE
KEY_UP1: SW_DIODE
KEY_V1: SW_DIODE
KEY_W1: SW_DIODE
KEY_X1: SW_DIODE
KEY_Z1: SW_DIODE
LEFT_ALT1: SW_DIODE
LEFT_CONTROL1: SW_DIODE
LEFT_DSUB1: DB25
LEFT_HYPER1: SW_DIODE
LEFT_SHIFT1: SW_DIODE
LEFT_SPACE1: SW_DIODE
LEFT_WIN1: SW_DIODE
NUM_0, NUM_1, NUM_2, NUM_3, NUM_4, NUM_5, NUM_6, NUM_7, NUM_8, NUM_9: SW_DIODE
NUM_DIV1: SW_DIODE
NUM_ENTER1: SW_DIODE
NUM_LOCK1: SW_DIODE
NUM_MINUS1: SW_DIODE
NUM_MUL1: SW_DIODE
NUM_PERIOD1: SW_DIODE
NUM_PLUS1: SW_DIODE

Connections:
unnamed: LEFT_SPACE1.6 (RES_LED), LEFT_SPACE1.7 (LED_RES)
unnamed: KEY_L6.2 (SW_DIODE), KEY_L6.3 (DIODE_SW)
unnamed: KEY_L6.6 (RES_LED), KEY_L6.7 (LED_RES)
unnamed: CAPS_LOCK1.8 (GND), KEY_1.8 (GND), KEY_2.8 (GND), KEY_3.8 (GND), KEY_4.8 (GND), KEY_5.8 (GND), KEY_6.8 (GND), KEY_A1.8 (GND), KEY_B1.8 (GND), KEY_BACKTICK1.8 (GND), KEY_C1.8 (GND), KEY_D1.8 (GND), KEY_DELETE1.8 (GND), KEY_DOWN1.8 (GND), KEY_E1.8 (GND), KEY_END1.8 (GND), KEY_ESC1.8 (GND), KEY_F1.8 (GND), KEY_F2.8 (GND), KEY_F3.8 (GND), KEY_F4.8 (GND), KEY_F5.8 (GND), KEY_F6.8 (GND), KEY_G1.8 (GND), KEY_HOME1.8 (GND), KEY_INSERT1.8 (GND), KEY_L1.8 (GND), KEY_L2.8 (GND), KEY_L3.8 (GND), KEY_L4.8 (GND), KEY_L5.8 (GND), KEY_L6.8 (GND), KEY_LEFT1.8 (GND), KEY_M1.8 (GND), KEY_M2.8 (GND), KEY_M3.8 (GND), KEY_M4.8 (GND), KEY_M5.8 (GND), KEY_M6.8 (GND), KEY_N1.8 (GND), KEY_N2.8 (GND), KEY_N3.8 (GND), KEY_N4.8 (GND), KEY_PAGE_DOWN1.8 (GND), KEY_PAGE_UP1.8 (GND), KEY_PAUSE1.8 (GND), KEY_PRINT1.8 (GND), KEY_Q1.8 (GND), KEY_R1.8 (GND), KEY_RIGHT1.8 (GND), KEY_S1.8 (GND), KEY_SCROLL1.8 (GND), KEY_T1.8 (GND), KEY_TAB1.8 (GND), KEY_UP1.8 (GND), KEY_V1.8 (GND), KEY_W1.8 (GND), KEY_X1.8 (GND), KEY_Z1.8 (GND), LEFT_ALT1.8 (GND), LEFT_CONTROL1.8 (GND), LEFT_DSUB1.25, LEFT_HYPER1.8 (GND), LEFT_SHIFT1.8 (GND), LEFT_SPACE1.8 (GND), LEFT_WIN1.8 (GND), NUM_0.8 (GND), NUM_1.8 (GND), NUM_2.8 (GND), NUM_3.8 (GND), NUM_4.8 (GND), NUM_5.8 (GND), NUM_6.8 (GND), NUM_7.8 (GND), NUM_8.8 (GND), NUM_9.8 (GND), NUM_DIV1.8 (GND), NUM_ENTER1.8 (GND), NUM_LOCK1.8 (GND), NUM_MINUS1.8 (GND), NUM_MUL1.8 (GND), NUM_PERIOD1.8 (GND), NUM_PLUS1.8 (GND)
unnamed: KEY_ESC1.4 (ROW), KEY_F1.4 (ROW), KEY_F2.4 (ROW), KEY_F3.4 (ROW), KEY_F4.4 (ROW), KEY_F5.4 (ROW), KEY_L1.4 (ROW), KEY_N1.4 (ROW), KEY_N2.4 (ROW), KEY_N3.4 (ROW), KEY_N4.4 (ROW), LEFT_DSUB1.1
unnamed: KEY_1.4 (ROW), KEY_2.4 (ROW), KEY_3.4 (ROW), KEY_4.4 (ROW), KEY_5.4 (ROW), KEY_6.4 (ROW), KEY_BACKTICK1.4 (ROW), LEFT_DSUB1.2, NUM_DIV1.4 (ROW), NUM_LOCK1.4 (ROW), NUM_MINUS1.4 (ROW), NUM_MUL1.4 (ROW)
unnamed: KEY_E1.4 (ROW), KEY_L3.4 (ROW), KEY_Q1.4 (ROW), KEY_R1.4 (ROW), KEY_T1.4 (ROW), KEY_TAB1.4 (ROW), KEY_W1.4 (ROW), LEFT_DSUB1.3, NUM_7.4 (ROW), NUM_8.4 (ROW), NUM_9.4 (ROW), NUM_PLUS1.4 (ROW)
unnamed: CAPS_LOCK1.4 (ROW), KEY_A1.4 (ROW), KEY_D1.4 (ROW), KEY_F6.4 (ROW), KEY_G1.4 (ROW), KEY_L4.4 (ROW), KEY_M1.4 (ROW), KEY_S1.4 (ROW), LEFT_DSUB1.4, NUM_4.4 (ROW), NUM_5.4 (ROW), NUM_6.4 (ROW)
unnamed: NUM_ENTER1.6 (RES_LED), NUM_ENTER1.7 (LED_RES)
unnamed: KEY_M5.2 (SW_DIODE), KEY_M5.3 (DIODE_SW)
unnamed: KEY_M5.6 (RES_LED), KEY_M5.7 (LED_RES)
unnamed: KEY_M6.2 (SW_DIODE), KEY_M6.3 (DIODE_SW)
unnamed: KEY_M6.6 (RES_LED), KEY_M6.7 (LED_RES)
unnamed: NUM_ENTER1.2 (SW_DIODE), NUM_ENTER1.3 (DIODE_SW)
unnamed: NUM_4.2 (SW_DIODE), NUM_4.3 (DIODE_SW)
unnamed: NUM_4.6 (RES_LED), NUM_4.7 (LED_RES)
unnamed: NUM_1.2 (SW_DIODE), NUM_1.3 (DIODE_SW)
unnamed: NUM_1.6 (RES_LED), NUM_1.7 (LED_RES)
unnamed: NUM_9.2 (SW_DIODE), NUM_9.3 (DIODE_SW)
unnamed: NUM_9.6 (RES_LED), NUM_9.7 (LED_RES)
unnamed: KEY_DELETE1.2 (SW_DIODE), KEY_DELETE1.3 (DIODE_SW)
unnamed: KEY_DELETE1.6 (RES_LED), KEY_DELETE1.7 (LED_RES)
unnamed: KEY_END1.2 (SW_DIODE), KEY_END1.3 (DIODE_SW)
unnamed: NUM_PERIOD1.2 (SW_DIODE), NUM_PERIOD1.3 (DIODE_SW)
unnamed: KEY_END1.6 (RES_LED), KEY_END1.7 (LED_RES)
unnamed: KEY_PAGE_DOWN1.2 (SW_DIODE), KEY_PAGE_DOWN1.3 (DIODE_SW)
unnamed: KEY_PAGE_DOWN1.6 (RES_LED), KEY_PAGE_DOWN1.7 (LED_RES)
unnamed: KEY_M4.2 (SW_DIODE), KEY_M4.3 (DIODE_SW)
unnamed: KEY_M4.6 (RES_LED), KEY_M4.7 (LED_RES)
unnamed: KEY_UP1.6 (RES_LED), KEY_UP1.7 (LED_RES)
unnamed: NUM_0.2 (SW_DIODE), NUM_0.3 (DIODE_SW)
unnamed: NUM_0.6 (RES_LED), NUM_0.7 (LED_RES)
unnamed: KEY_LEFT1.2 (SW_DIODE), KEY_LEFT1.3 (DIODE_SW)
unnamed: KEY_LEFT1.6 (RES_LED), KEY_LEFT1.7 (LED_RES)
unnamed: KEY_UP1.2 (SW_DIODE), KEY_UP1.3 (DIODE_SW)
unnamed: KEY_DOWN1.2 (SW_DIODE), KEY_DOWN1.3 (DIODE_SW)
unnamed: KEY_DOWN1.6 (RES_LED), KEY_DOWN1.7 (LED_RES)
unnamed: KEY_RIGHT1.2 (SW_DIODE), KEY_RIGHT1.3 (DIODE_SW)
unnamed: KEY_RIGHT1.6 (RES_LED), KEY_RIGHT1.7 (LED_RES)
unnamed: KEY_ESC1.2 (SW_DIODE), KEY_ESC1.3 (DIODE_SW)
unnamed: NUM_2.6 (RES_LED), NUM_2.7 (LED_RES)
unnamed: NUM_PERIOD1.6 (RES_LED), NUM_PERIOD1.7 (LED_RES)
unnamed: NUM_5.2 (SW_DIODE), NUM_5.3 (DIODE_SW)
unnamed: NUM_5.6 (RES_LED), NUM_5.7 (LED_RES)
unnamed: NUM_2.2 (SW_DIODE), NUM_2.3 (DIODE_SW)
unnamed: NUM_6.2 (SW_DIODE), NUM_6.3 (DIODE_SW)
unnamed: NUM_6.6 (RES_LED), NUM_6.7 (LED_RES)
unnamed: NUM_3.2 (SW_DIODE), NUM_3.3 (DIODE_SW)
unnamed: NUM_3.6 (RES_LED), NUM_3.7 (LED_RES)
unnamed: KEY_SCROLL1.6 (RES_LED), KEY_SCROLL1.7 (LED_RES)
unnamed: KEY_N1.6 (RES_LED), KEY_N1.7 (LED_RES)
unnamed: KEY_N2.6 (RES_LED), KEY_N2.7 (LED_RES)
unnamed: KEY_N3.6 (RES_LED), KEY_N3.7 (LED_RES)
unnamed: KEY_N4.6 (RES_LED), KEY_N4.7 (LED_RES)
unnamed: KEY_PRINT1.6 (RES_LED), KEY_PRINT1.7 (LED_RES)
unnamed: KEY_PAUSE1.6 (RES_LED), KEY_PAUSE1.7 (LED_RES)
unnamed: KEY_M2.2 (SW_DIODE), KEY_M2.3 (DIODE_SW)
unnamed: KEY_M2.6 (RES_LED), KEY_M2.7 (LED_RES)
unnamed: NUM_MINUS1.2 (SW_DIODE), NUM_MINUS1.3 (DIODE_SW)
unnamed: NUM_MINUS1.6 (RES_LED), NUM_MINUS1.7 (LED_RES)
unnamed: KEY_N4.2 (SW_DIODE), KEY_N4.3 (DIODE_SW)
unnamed: CAPS_LOCK1.5 (VCC), KEY_1.5 (VCC), KEY_2.5 (VCC), KEY_3.5 (VCC), KEY_4.5 (VCC), KEY_5.5 (VCC), KEY_6.5 (VCC), KEY_A1.5 (VCC), KEY_B1.5 (VCC), KEY_BACKTICK1.5 (VCC), KEY_C1.5 (VCC), KEY_D1.5 (VCC), KEY_DELETE1.5 (VCC), KEY_DOWN1.5 (VCC), KEY_E1.5 (VCC), KEY_END1.5 (VCC), KEY_ESC1.5 (VCC), KEY_F1.5 (VCC), KEY_F2.5 (VCC), KEY_F3.5 (VCC), KEY_F4.5 (VCC), KEY_F5.5 (VCC), KEY_F6.5 (VCC), KEY_G1.5 (VCC), KEY_HOME1.5 (VCC), KEY_INSERT1.5 (VCC), KEY_L1.5 (VCC), KEY_L2.5 (VCC), KEY_L3.5 (VCC), KEY_L4.5 (VCC), KEY_L5.5 (VCC), KEY_L6.5 (VCC), KEY_LEFT1.5 (VCC), KEY_M1.5 (VCC), KEY_M2.5 (VCC), KEY_M3.5 (VCC), KEY_M4.5 (VCC), KEY_M5.5 (VCC), KEY_M6.5 (VCC), KEY_N1.5 (VCC), KEY_N2.5 (VCC), KEY_N3.5 (VCC), KEY_N4.5 (VCC), KEY_PAGE_DOWN1.5 (VCC), KEY_PAGE_UP1.5 (VCC), KEY_PAUSE1.5 (VCC), KEY_PRINT1.5 (VCC), KEY_Q1.5 (VCC), KEY_R1.5 (VCC), KEY_RIGHT1.5 (VCC), KEY_S1.5 (VCC), KEY_SCROLL1.5 (VCC), KEY_T1.5 (VCC), KEY_TAB1.5 (VCC), KEY_UP1.5 (VCC), KEY_V1.5 (VCC), KEY_W1.5 (VCC), KEY_X1.5 (VCC), KEY_Z1.5 (VCC), LEFT_ALT1.5 (VCC), LEFT_CONTROL1.5 (VCC), LEFT_DSUB1.24, LEFT_HYPER1.5 (VCC), LEFT_SHIFT1.5 (VCC), LEFT_SPACE1.5 (VCC), LEFT_WIN1.5 (VCC), NUM_0.5 (VCC), NUM_1.5 (VCC), NUM_2.5 (VCC), NUM_3.5 (VCC), NUM_4.5 (VCC), NUM_5.5 (VCC), NUM_6.5 (VCC), NUM_7.5 (VCC), NUM_8.5 (VCC), NUM_9.5 (VCC), NUM_DIV1.5 (VCC), NUM_ENTER1.5 (VCC), NUM_LOCK1.5 (VCC), NUM_MINUS1.5 (VCC), NUM_MUL1.5 (VCC), NUM_PERIOD1.5 (VCC), NUM_PLUS1.5 (VCC)
unnamed: KEY_M1.2 (SW_DIODE), KEY_M1.3 (DIODE_SW)
unnamed: KEY_N1.2 (SW_DIODE), KEY_N1.3 (DIODE_SW)
unnamed: KEY_N2.2 (SW_DIODE), KEY_N2.3 (DIODE_SW)
unnamed: KEY_N3.2 (SW_DIODE), KEY_N3.3 (DIODE_SW)
unnamed: KEY_PRINT1.2 (SW_DIODE), KEY_PRINT1.3 (DIODE_SW)
unnamed: KEY_SCROLL1.2 (SW_DIODE), KEY_SCROLL1.3 (DIODE_SW)
unnamed: KEY_PAUSE1.2 (SW_DIODE), KEY_PAUSE1.3 (DIODE_SW)
unnamed: KEY_M1.6 (RES_LED), KEY_M1.7 (LED_RES)
unnamed: KEY_HOME1.6 (RES_LED), KEY_HOME1.7 (LED_RES)
unnamed: KEY_PAGE_UP1.2 (SW_DIODE), KEY_PAGE_UP1.3 (DIODE_SW)
unnamed: KEY_PAGE_UP1.6 (RES_LED), KEY_PAGE_UP1.7 (LED_RES)
unnamed: KEY_M3.2 (SW_DIODE), KEY_M3.3 (DIODE_SW)
unnamed: KEY_M3.6 (RES_LED), KEY_M3.7 (LED_RES)
unnamed: NUM_PLUS1.2 (SW_DIODE), NUM_PLUS1.3 (DIODE_SW)
unnamed: NUM_7.2 (SW_DIODE), NUM_7.3 (DIODE_SW)
unnamed: NUM_7.6 (RES_LED), NUM_7.7 (LED_RES)
unnamed: NUM_PLUS1.6 (RES_LED), NUM_PLUS1.7 (LED_RES)
unnamed: NUM_8.2 (SW_DIODE), NUM_8.3 (DIODE_SW)
unnamed: NUM_8.6 (RES_LED), NUM_8.7 (LED_RES)
unnamed: NUM_LOCK1.2 (SW_DIODE), NUM_LOCK1.3 (DIODE_SW)
unnamed: NUM_MUL1.2 (SW_DIODE), NUM_MUL1.3 (DIODE_SW)
unnamed: NUM_MUL1.6 (RES_LED), NUM_MUL1.7 (LED_RES)
unnamed: NUM_DIV1.2 (SW_DIODE), NUM_DIV1.3 (DIODE_SW)
unnamed: NUM_DIV1.6 (RES_LED), NUM_DIV1.7 (LED_RES)
unnamed: NUM_LOCK1.6 (RES_LED), NUM_LOCK1.7 (LED_RES)
unnamed: KEY_INSERT1.2 (SW_DIODE), KEY_INSERT1.3 (DIODE_SW)
unnamed: KEY_INSERT1.6 (RES_LED), KEY_INSERT1.7 (LED_RES)
unnamed: KEY_HOME1.2 (SW_DIODE), KEY_HOME1.3 (DIODE_SW)
unnamed: KEY_L4.2 (SW_DIODE), KEY_L4.3 (DIODE_SW)
unnamed: KEY_D1.6 (RES_LED), KEY_D1.7 (LED_RES)
unnamed: KEY_F6.2 (SW_DIODE), KEY_F6.3 (DIODE_SW)
unnamed: KEY_F6.6 (RES_LED), KEY_F6.7 (LED_RES)
unnamed: KEY_G1.2 (SW_DIODE), KEY_G1.3 (DIODE_SW)
unnamed: KEY_G1.6 (RES_LED), KEY_G1.7 (LED_RES)
unnamed: KEY_L4.6 (RES_LED), KEY_L4.7 (LED_RES)
unnamed: LEFT_SHIFT1.2 (SW_DIODE), LEFT_SHIFT1.3 (DIODE_SW)
unnamed: LEFT_SHIFT1.6 (RES_LED), LEFT_SHIFT1.7 (LED_RES)
unnamed: KEY_Z1.2 (SW_DIODE), KEY_Z1.3 (DIODE_SW)
unnamed: KEY_T1.6 (RES_LED), KEY_T1.7 (LED_RES)
unnamed: KEY_L3.2 (SW_DIODE), KEY_L3.3 (DIODE_SW)
unnamed: KEY_L3.6 (RES_LED), KEY_L3.7 (LED_RES)
unnamed: CAPS_LOCK1.2 (SW_DIODE), CAPS_LOCK1.3 (DIODE_SW)
unnamed: CAPS_LOCK1.6 (RES_LED), CAPS_LOCK1.7 (LED_RES)
unnamed: KEY_Z1.6 (RES_LED), KEY_Z1.7 (LED_RES)
unnamed: KEY_A1.2 (SW_DIODE), KEY_A1.3 (DIODE_SW)
unnamed: KEY_A1.6 (RES_LED), KEY_A1.7 (LED_RES)
unnamed: KEY_S1.2 (SW_DIODE), KEY_S1.3 (DIODE_SW)
unnamed: KEY_S1.6 (RES_LED), KEY_S1.7 (LED_RES)
unnamed: KEY_D1.2 (SW_DIODE), KEY_D1.3 (DIODE_SW)
unnamed: LEFT_ALT1.2 (SW_DIODE), LEFT_ALT1.3 (DIODE_SW)
unnamed: KEY_L5.6 (RES_LED), KEY_L5.7 (LED_RES)
unnamed: LEFT_CONTROL1.2 (SW_DIODE), LEFT_CONTROL1.3 (DIODE_SW)
unnamed: LEFT_CONTROL1.6 (RES_LED), LEFT_CONTROL1.7 (LED_RES)
unnamed: LEFT_WIN1.2 (SW_DIODE), LEFT_WIN1.3 (DIODE_SW)
unnamed: LEFT_WIN1.6 (RES_LED), LEFT_WIN1.7 (LED_RES)
unnamed: LEFT_ALT1.6 (RES_LED), LEFT_ALT1.7 (LED_RES)
unnamed: LEFT_HYPER1.2 (SW_DIODE), LEFT_HYPER1.3 (DIODE_SW)
unnamed: LEFT_HYPER1.6 (RES_LED), LEFT_HYPER1.7 (LED_RES)
unnamed: LEFT_SPACE1.2 (SW_DIODE), LEFT_SPACE1.3 (DIODE_SW)
unnamed: KEY_V1.2 (SW_DIODE), KEY_V1.3 (DIODE_SW)
unnamed: KEY_X1.2 (SW_DIODE), KEY_X1.3 (DIODE_SW)
unnamed: KEY_X1.6 (RES_LED), KEY_X1.7 (LED_RES)
unnamed: KEY_C1.2 (SW_DIODE), KEY_C1.3 (DIODE_SW)
unnamed: KEY_C1.6 (RES_LED), KEY_C1.7 (LED_RES)
unnamed: KEY_V1.6 (RES_LED), KEY_V1.7 (LED_RES)
unnamed: KEY_B1.2 (SW_DIODE), KEY_B1.3 (DIODE_SW)
unnamed: KEY_B1.6 (RES_LED), KEY_B1.7 (LED_RES)
unnamed: KEY_L5.2 (SW_DIODE), KEY_L5.3 (DIODE_SW)
unnamed: KEY_F5.2 (SW_DIODE), KEY_F5.3 (DIODE_SW)
unnamed: KEY_F5.6 (RES_LED), KEY_F5.7 (LED_RES)
unnamed: KEY_L1.2 (SW_DIODE), KEY_L1.3 (DIODE_SW)
unnamed: KEY_L1.6 (RES_LED), KEY_L1.7 (LED_RES)
unnamed: KEY_L2.2 (SW_DIODE), KEY_L2.3 (DIODE_SW)
unnamed: KEY_L2.6 (RES_LED), KEY_L2.7 (LED_RES)
unnamed: KEY_BACKTICK1.2 (SW_DIODE), KEY_BACKTICK1.3 (DIODE_SW)
unnamed: KEY_BACKTICK1.6 (RES_LED), KEY_BACKTICK1.7 (LED_RES)
unnamed: KEY_1.2 (SW_DIODE), KEY_1.3 (DIODE_SW)
unnamed: KEY_1.6 (RES_LED), KEY_1.7 (LED_RES)
unnamed: KEY_2.2 (SW_DIODE), KEY_2.3 (DIODE_SW)
unnamed: KEY_F2.6 (RES_LED), KEY_F2.7 (LED_RES)
unnamed: KEY_ESC1.6 (RES_LED), KEY_ESC1.7 (LED_RES)
unnamed: KEY_F1.2 (SW_DIODE), KEY_F1.3 (DIODE_SW)
unnamed: KEY_F1.6 (RES_LED), KEY_F1.7 (LED_RES)
unnamed: KEY_F2.2 (SW_DIODE), KEY_F2.3 (DIODE_SW)
unnamed: KEY_F3.2 (SW_DIODE), KEY_F3.3 (DIODE_SW)
unnamed: KEY_F3.6 (RES_LED), KEY_F3.7 (LED_RES)
unnamed: KEY_F4.2 (SW_DIODE), KEY_F4.3 (DIODE_SW)
unnamed: KEY_F4.6 (RES_LED), KEY_F4.7 (LED_RES)
unnamed: KEY_TAB1.6 (RES_LED), KEY_TAB1.7 (LED_RES)
unnamed: KEY_Q1.2 (SW_DIODE), KEY_Q1.3 (DIODE_SW)
unnamed: KEY_Q1.6 (RES_LED), KEY_Q1.7 (LED_RES)
unnamed: KEY_W1.2 (SW_DIODE), KEY_W1.3 (DIODE_SW)
unnamed: KEY_W1.6 (RES_LED), KEY_W1.7 (LED_RES)
unnamed: KEY_E1.2 (SW_DIODE), KEY_E1.3 (DIODE_SW)
unnamed: KEY_E1.6 (RES_LED), KEY_E1.7 (LED_RES)
unnamed: KEY_R1.2 (SW_DIODE), KEY_R1.3 (DIODE_SW)
unnamed: KEY_R1.6 (RES_LED), KEY_R1.7 (LED_RES)
unnamed: KEY_T1.2 (SW_DIODE), KEY_T1.3 (DIODE_SW)
unnamed: KEY_2.6 (RES_LED), KEY_2.7 (LED_RES)
unnamed: KEY_3.2 (SW_DIODE), KEY_3.3 (DIODE_SW)
unnamed: KEY_3.6 (RES_LED), KEY_3.7 (LED_RES)
unnamed: KEY_4.2 (SW_DIODE), KEY_4.3 (DIODE_SW)
unnamed: KEY_4.6 (RES_LED), KEY_4.7 (LED_RES)
unnamed: KEY_5.2 (SW_DIODE), KEY_5.3 (DIODE_SW)
unnamed: KEY_5.6 (RES_LED), KEY_5.7 (LED_RES)
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

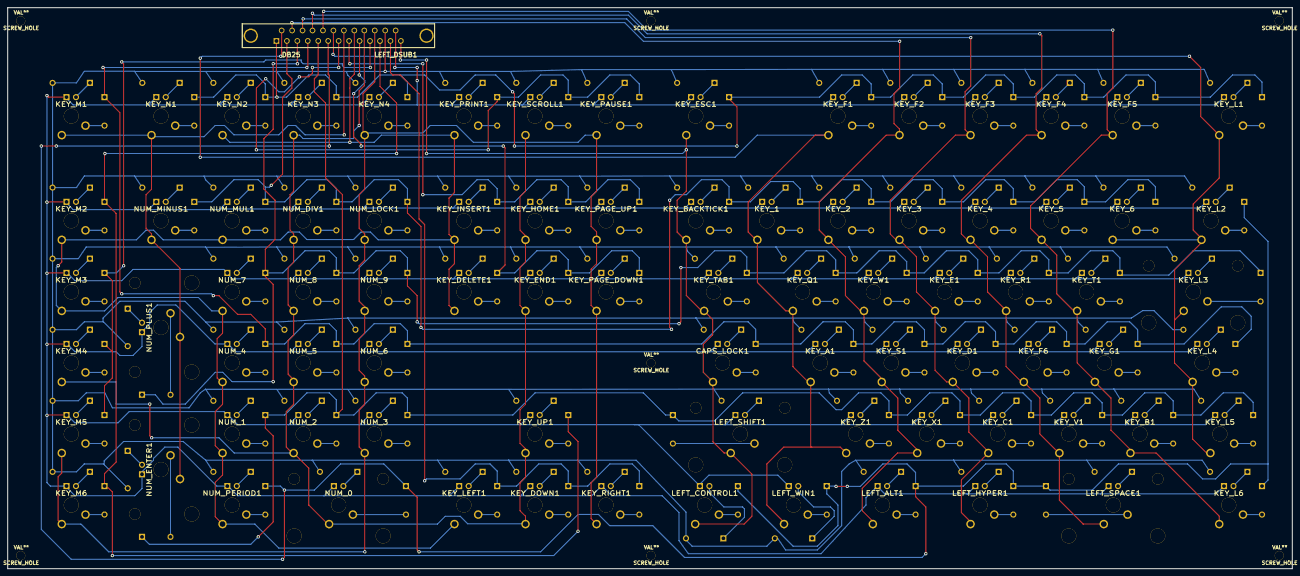
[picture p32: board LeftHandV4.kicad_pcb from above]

Board: 2 copper layers, 343.5 x 150.0 mm, 90 parts (0 on the bottom side), 189 nets.

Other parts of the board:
SCREW_HOLE: VAL**; SCREW_HOLE
SCREW_HOLE#2, SCREW_HOLE#3, SCREW_HOLE#4, SCREW_HOLE#5, SCREW_HOLE#6, SCREW_HOLE#7: VAL**; SCREW_HOLE

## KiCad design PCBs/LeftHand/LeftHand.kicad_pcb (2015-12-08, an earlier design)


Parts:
P1: CONN_6
P2, P3: CONN_10
SW1, SW2, SW3, SW4, SW5, SW6, SW7, SW8, SW9, SW10, SW11, SW12, SW13, SW14, SW15, SW16, SW17, SW18, SW19, SW20, SW21, SW22, SW23, SW24, SW25, SW26, SW27, SW28, SW29, SW30, SW31, SW32, SW33, SW34: SW_DIODE
T1: TEENSY20

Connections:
unnamed: P3.4, SW9.4 (ROW), SW15.4 (ROW), SW21.4 (ROW), SW27.4 (ROW), SW32.4 (ROW), T1.4 (3)
unnamed: SW5.4 (ROW), SW11.4 (ROW), SW17.4 (ROW), SW23.4 (ROW), T1.6 (5)
unnamed: P3.5, SW4.4 (ROW), SW10.4 (ROW), SW16.4 (ROW), SW22.4 (ROW), SW28.4 (ROW), SW33.4 (ROW), T1.5 (4)
unnamed: P1.4, SW1.8 (GND), SW2.8 (GND), SW3.8 (GND), SW4.8 (GND), SW5.8 (GND), SW6.8 (GND), SW7.8 (GND), SW8.8 (GND), SW9.8 (GND), SW10.8 (GND), SW11.8 (GND), SW12.8 (GND), SW13.8 (GND), SW14.8 (GND), SW15.8 (GND), SW16.8 (GND), SW17.8 (GND), SW18.8 (GND), SW19.8 (GND), SW20.8 (GND), SW21.8 (GND), SW22.8 (GND), SW23.8 (GND), SW24.8 (GND), SW25.8 (GND), SW26.8 (GND), SW27.8 (GND), SW28.8 (GND), SW29.8 (GND), SW30.8 (GND), SW31.8 (GND), SW32.8 (GND), SW33.8 (GND), SW34.8 (GND), T1.0 (GND)
unnamed: P3.3, SW3.4 (ROW), SW8.4 (ROW), SW14.4 (ROW), SW20.4 (ROW), SW26.4 (ROW), SW31.4 (ROW), T1.3 (2)
unnamed: SW11.6 (RES_LED), SW11.7 (LED_RES)
unnamed: SW5.2 (SW_DIODE), SW5.3 (DIODE_SW)
unnamed: SW5.6 (RES_LED), SW5.7 (LED_RES)
unnamed: SW10.2 (SW_DIODE), SW10.3 (DIODE_SW)
unnamed: SW10.6 (RES_LED), SW10.7 (LED_RES)
unnamed: SW11.2 (SW_DIODE), SW11.3 (DIODE_SW)
unnamed: SW16.2 (SW_DIODE), SW16.3 (DIODE_SW)
unnamed: SW16.6 (RES_LED), SW16.7 (LED_RES)
unnamed: SW17.2 (SW_DIODE), SW17.3 (DIODE_SW)
unnamed: SW17.6 (RES_LED), SW17.7 (LED_RES)
unnamed: SW30.6 (RES_LED), SW30.7 (LED_RES)
unnamed: SW31.2 (SW_DIODE), SW31.3 (DIODE_SW)
unnamed: SW31.6 (RES_LED), SW31.7 (LED_RES)
unnamed: SW32.2 (SW_DIODE), SW32.3 (DIODE_SW)
unnamed: SW32.6 (RES_LED), SW32.7 (LED_RES)
unnamed: SW34.2 (SW_DIODE), SW34.3 (DIODE_SW)
unnamed: SW34.6 (RES_LED), SW34.7 (LED_RES)
unnamed: SW4.2 (SW_DIODE), SW4.3 (DIODE_SW)
unnamed: SW4.6 (RES_LED), SW4.7 (LED_RES)
unnamed: SW28.2 (SW_DIODE), SW28.3 (DIODE_SW)
unnamed: SW22.2 (SW_DIODE), SW22.3 (DIODE_SW)
unnamed: SW22.6 (RES_LED), SW22.7 (LED_RES)
unnamed: SW23.2 (SW_DIODE), SW23.3 (DIODE_SW)
unnamed: SW23.6 (RES_LED), SW23.7 (LED_RES)
unnamed: SW28.6 (RES_LED), SW28.7 (LED_RES)
unnamed: SW33.2 (SW_DIODE), SW33.3 (DIODE_SW)
unnamed: SW33.6 (RES_LED), SW33.7 (LED_RES)
unnamed: P2.8, SW34.1 (COL), T1.19 (18)
unnamed: P2.10, T1.21 (20)
unnamed: P2.9, T1.20 (19)
unnamed: P1.1, T1.22 (21)
unnamed: P1.2, T1.24 (22)
unnamed: P3.7, T1.8 (7)
unnamed: P3.6, T1.7 (6)
unnamed: P3.8, T1.9 (8)
unnamed: P3.9, T1.10 (9)
unnamed: P3.10, T1.11 (10)
unnamed: P2.1, T1.12 (11)
unnamed: P3.1, SW1.4 (ROW), SW6.4 (ROW), SW12.4 (ROW), SW18.4 (ROW), SW24.4 (ROW), SW29.4 (ROW), T1.1 (0)
unnamed: P2.7, SW29.1 (COL), SW30.1 (COL), SW31.1 (COL), SW32.1 (COL), SW33.1 (COL), T1.18 (17)
unnamed: P3.2, SW2.4 (ROW), SW7.4 (ROW), SW13.4 (ROW), SW19.4 (ROW), SW25.4 (ROW), SW30.4 (ROW), SW34.4 (ROW), T1.2 (1)
unnamed: P2.6, SW24.1 (COL), SW25.1 (COL), SW26.1 (COL), SW27.1 (COL), SW28.1 (COL), T1.17 (16)
unnamed: P1.3, SW1.5 (VCC), SW2.5 (VCC), SW3.5 (VCC), SW4.5 (VCC), SW5.5 (VCC), SW6.5 (VCC), SW7.5 (VCC), SW8.5 (VCC), SW9.5 (VCC), SW10.5 (VCC), SW11.5 (VCC), SW12.5 (VCC), SW13.5 (VCC), SW14.5 (VCC), SW15.5 (VCC), SW16.5 (VCC), SW17.5 (VCC), SW18.5 (VCC), SW19.5 (VCC), SW20.5 (VCC), SW21.5 (VCC), SW22.5 (VCC), SW23.5 (VCC), SW24.5 (VCC), SW25.5 (VCC), SW26.5 (VCC), SW27.5 (VCC), SW28.5 (VCC), SW29.5 (VCC), SW30.5 (VCC), SW31.5 (VCC), SW32.5 (VCC), SW33.5 (VCC), SW34.5 (VCC), T1.23 (VCC)
unnamed: P2.3, SW6.1 (COL), SW7.1 (COL), SW8.1 (COL), SW9.1 (COL), SW10.1 (COL), SW11.1 (COL), T1.14 (13)
unnamed: P2.2, SW1.1 (COL), SW2.1 (COL), SW3.1 (COL), SW4.1 (COL), SW5.1 (COL), T1.13 (12)
unnamed: P2.5, SW18.1 (COL), SW19.1 (COL), SW20.1 (COL), SW21.1 (COL), SW22.1 (COL), SW23.1 (COL), T1.16 (15)
unnamed: P2.4, SW12.1 (COL), SW13.1 (COL), SW14.1 (COL), SW15.1 (COL), SW16.1 (COL), SW17.1 (COL), T1.15 (14)
unnamed: SW20.2 (SW_DIODE), SW20.3 (DIODE_SW)
unnamed: SW18.6 (RES_LED), SW18.7 (LED_RES)
unnamed: SW19.2 (SW_DIODE), SW19.3 (DIODE_SW)
unnamed: SW19.6 (RES_LED), SW19.7 (LED_RES)
unnamed: SW20.6 (RES_LED), SW20.7 (LED_RES)
unnamed: SW21.2 (SW_DIODE), SW21.3 (DIODE_SW)
unnamed: SW21.6 (RES_LED), SW21.7 (LED_RES)
unnamed: SW15.2 (SW_DIODE), SW15.3 (DIODE_SW)
unnamed: SW15.6 (RES_LED), SW15.7 (LED_RES)
unnamed: SW18.2 (SW_DIODE), SW18.3 (DIODE_SW)
unnamed: SW25.6 (RES_LED), SW25.7 (LED_RES)
unnamed: SW26.2 (SW_DIODE), SW26.3 (DIODE_SW)
unnamed: SW26.6 (RES_LED), SW26.7 (LED_RES)
unnamed: SW27.6 (RES_LED), SW27.7 (LED_RES)
unnamed: SW24.2 (SW_DIODE), SW24.3 (DIODE_SW)
unnamed: SW24.6 (RES_LED), SW24.7 (LED_RES)
unnamed: SW25.2 (SW_DIODE), SW25.3 (DIODE_SW)
unnamed: SW6.2 (SW_DIODE), SW6.3 (DIODE_SW)
unnamed: SW6.6 (RES_LED), SW6.7 (LED_RES)
unnamed: SW7.6 (RES_LED), SW7.7 (LED_RES)
unnamed: SW1.2 (SW_DIODE), SW1.3 (DIODE_SW)
unnamed: SW1.6 (RES_LED), SW1.7 (LED_RES)
unnamed: SW2.2 (SW_DIODE), SW2.3 (DIODE_SW)
unnamed: SW2.6 (RES_LED), SW2.7 (LED_RES)
unnamed: SW3.2 (SW_DIODE), SW3.3 (DIODE_SW)
unnamed: SW3.6 (RES_LED), SW3.7 (LED_RES)
unnamed: SW13.2 (SW_DIODE), SW13.3 (DIODE_SW)
unnamed: SW12.2 (SW_DIODE), SW12.3 (DIODE_SW)
unnamed: SW12.6 (RES_LED), SW12.7 (LED_RES)
unnamed: SW13.6 (RES_LED), SW13.7 (LED_RES)
unnamed: SW14.2 (SW_DIODE), SW14.3 (DIODE_SW)
unnamed: SW14.6 (RES_LED), SW14.7 (LED_RES)
unnamed: SW8.2 (SW_DIODE), SW8.3 (DIODE_SW)
unnamed: SW8.6 (RES_LED), SW8.7 (LED_RES)
unnamed: SW9.2 (SW_DIODE), SW9.3 (DIODE_SW)
unnamed: SW9.6 (RES_LED), SW9.7 (LED_RES)
unnamed: SW7.2 (SW_DIODE), SW7.3 (DIODE_SW)
unnamed: SW27.2 (SW_DIODE), SW27.3 (DIODE_SW)
unnamed: SW29.2 (SW_DIODE), SW29.3 (DIODE_SW)
unnamed: SW29.6 (RES_LED), SW29.7 (LED_RES)
unnamed: SW30.2 (SW_DIODE), SW30.3 (DIODE_SW)


Board: 2 copper layers, 160.0 x 138.0 mm, 38 parts (0 on the bottom side), 93 nets.

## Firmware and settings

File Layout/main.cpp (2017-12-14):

#include <iostream>
#include <vector>
#include <memory>
#include <string>
using namespace std;

const double tops[] = { 10, 38, 57, 76, 95, 114 };
const double dsubSpace = 12;
const double keyHole = 14;

class Element
{
public:
	virtual bool IsKey() const { return false; }
	virtual bool IsPlate() const { return false; }
	virtual double KeyPadding() const { return 0; }
	virtual double Width() const = 0;
	virtual string Name() const { return ""; }
};

class Spacer : public Element
{
public:
	Spacer(double mm)
		: mm(mm)
	{
	}
	bool IsPlate() const final { return true; }
	double Width() const final { return mm; }
private:
	double mm;
};

class Padding : public Element
{
public:
	Padding()
	{
	}
	double Width() const final { return 0.5; }
};

class Key : public Element
{
public:
	Key(double ratio, string name = "")
		: ratio(ratio), name(name)
	{
	}
	bool IsKey() const final { return true; }
	double KeyPadding() const final { return (Width() - 14) / 2; }
	double Width() const final { return ratio * 19; }
	string Name() const final { return name; }
private:
	double ratio;
	string name;
};

class Row
{
public:
	Row(string name, vector<shared_ptr<Element>> elements)
		: name(name), elements(elements)
	{
	}
	double PrintAndReturnWidth() const
	{
		auto left = 0.0;
		for (auto element : elements)
		{
			if (element->IsKey())
				cout << left + element->KeyPadding() << ", ";
			left += element->Width();
		}
		return left;
	}
	void PrintPcbPositions(double top) const
	{
		cout << name << ", top = " << top << '\n';
		auto width = PrintPcbPositionsAndReturnWidth();
		cout << "(width = " << width << ")\n\n";
	}
	double PrintPcbPositionsAndReturnWidth() const
	{
		auto left = 0.0;
		for (auto element : elements)
		{
			if (element->IsKey())
				cout << "  " << element->Name() << " = " << (left + element->KeyPadding() + (keyHole / 2)) << '\n';
			left += element->Width();
		}
		return left;
	}

	void PrintKeyLeftsAndRowWidth() const
	{
		cout << name << " = [";
		auto width = PrintAndReturnWidth();
		cout << "], width = " << width << '\n';
	}
	void PrintFacePlate() const
	{
		cout << "Face Plate " << name << " = ";
		double plate = 0, space = 0;
		auto isPlate = true;
		for (auto element : elements)
		{
			if (element->IsPlate() != isPlate)
			{
				if (isPlate && plate > 0)
					cout << "[" << plate << "] ";
				else if (!isPlate && space > 0)
					cout << "<" << space << "> ";
				plate = space = 0;
				isPlate = element->IsPlate();
			}

			if (element->IsPlate())
				plate += element->Width();
			else
				space += element->Width();
		}
		if (plate > 0)
			cout << "[" << plate << "]\n";
		else if (space > 0)
			cout << "<" << space << ">\n";
	}
private:
	string name;
	vector<shared_ptr<Element>> elements;
};

template <typename... T>
inline Row MakeRow(string name, T... elements)
{
	return { name, { make_shared<T>(elements)... } };
}

const Spacer outerEdge{ 7 };
const Spacer innerEdge{ 4 };
const Padding padding;

template <typename... T>
inline void Board(string name, T... boardRows)
{
	vector<Row> rows{ boardRows... };
	cout << "Board " << name << '\n';
	auto rowIndex = 0;
	// for (auto& row : rows)
	// 	row.PrintPcbPositions(tops[rowIndex++] + dsubSpace + (keyHole / 2));
	for (auto& row : rows)
		row.PrintKeyLeftsAndRowWidth();
	// for (auto& row : rows)
	// 	row.PrintFacePlate();
	cout << '\n';
}

int main()
{
	Board("Left Hand",
		MakeRow("Function Row",
			outerEdge, padding,
			Key{ 1, "M1" },
			padding, innerEdge, padding,
			Key{ 1, "N1" }, Key{ 1, "N2" }, Key{ 1, "N3" }, Key{ 1, "N4" },
			padding, innerEdge, padding,
			Key{ 1, "PRINT" }, Key{ 1, "SCROLL" }, Key{ 1, "PAUSE" },
			padding, innerEdge, padding,
			Key{ 1, "ESC" },
			padding,
			Spacer{ Key{ 1 }.Width() - padding.Width() * 2 },
			padding,
			Key{ 1, "F1" }, Key{ 1, "F2" }, Key{ 1, "F3" }, Key{ 1, "F4" }, Key{ 1, "F5" },
			padding,
			Spacer{ Key{ 1.5 }.Width() - Key{ 1 }.Width() - padding.Width() * 2 },
			padding,
			Key{ 1, "L1" },
			padding, outerEdge),
		MakeRow("Row 1",
			outerEdge, padding,
			Key{ 1, "M2" },
			padding, innerEdge, padding,
			Key{ 1, "NUM_MINUS" }, Key{ 1, "NUM_MUL" }, Key{ 1, "NUM_DIV" }, Key{ 1, "NUM_LOCK" },
			padding, innerEdge, padding,
			Key{ 1, "INSERT" }, Key{ 1, "HOME" }, Key{ 1, "PAGE_UP" },
			padding, innerEdge, padding,
			Key{ 1, "BACKTICK" }, Key{ 1, "1" }, Key{ 1, "2" }, Key{ 1, "3" }, Key{ 1, "4" }, Key{ 1, "5" }, Key{ 1, "6" }, Key{ 1.5, "L2" },
			padding, outerEdge),
		MakeRow("Row 2",
			outerEdge, padding,
			Key{ 1, "M3" },
			padding, innerEdge, padding,
			Key{ 1, "NUM_PLUS" }, Key{ 1, "NUM_7" }, Key{ 1, "NUM_8" }, Key{ 1, "NUM_9" },
			padding, innerEdge, padding,
			Key{ 1, "DELETE" }, Key{ 1, "END" }, Key{ 1, "PAGE_DOWN" },
			padding, innerEdge, padding,
			Key{ 1.5, "TAB" }, Key{ 1, "Q" }, Key{ 1, "W" }, Key{ 1, "E" }, Key{ 1, "R" }, Key{ 1, "T" }, Key{ 2, "L3" },
			padding, outerEdge),
		MakeRow("Row 3",
			outerEdge, padding,
			Key{ 1, "M4" },
			padding, innerEdge, padding,
			Key{ 1, "NUM_PLUS" }, Key{ 1, "NUM_4" }, Key{ 1, "NUM_5" }, Key{ 1, "NUM_6" },
			padding, Spacer{ innerEdge.Width() * 2 + Key{ 1 }.Width() * 3 + padding.Width() * 2 }, padding,
			Key{ 1.75, "CAPS_LOCK" }, Key{ 1, "A" }, Key{ 1, "S" }, Key{ 1, "D" }, Key{ 1, "F" }, Key{ 1, "G" }, Key{ 1.75, "L4" },
			padding, outerEdge),
		MakeRow("Row 4",
			outerEdge, padding,
			Key{ 1, "M5" },
			padding, innerEdge, padding,
			Key{ 1, "NUM_ENTER" }, Key{ 1, "NUM_1" }, Key{ 1, "NUM_2" }, Key{ 1, "NUM_3" },
			padding, innerEdge, Spacer{ Key{ 1 }.Width() }, padding,
			Key{ 1, "UP" },
			padding, Spacer{ Key{ 1 }.Width() }, innerEdge, padding,
			Key{ 2.25, "LEFT_SHIFT" }, Key{ 1, "Z" }, Key{ 1, "X" }, Key{ 1, "C" }, Key{ 1, "V" }, Key{ 1, "B" }, Key{ 1.25, "L5" },
			padding, outerEdge),
		MakeRow("Row 5",
			outerEdge, padding,
			Key{ 1, "M5" },
			padding, innerEdge, padding,
			Key{ 1, "NUM_ENTER" }, Key{ 1, "NUM_PERIOD" }, Key{ 2, "NUM_0" },
			padding, innerEdge, padding,
			Key{ 1, "LEFT" }, Key{ 1, "DOWN" }, Key{ 1, "RIGHT" },
			padding, innerEdge, padding,
			Key{ 1.25, "LEFT_CTRL" }, Key{ 1.25, "LEFT_WIN" }, Key{ 1.25, "LEFT_ALT" }, Key{ 1.5, "LEFT_HYPER" }, Key{ 2.25, "LEFT_SPACE" }, Key{ 1, "L6" },
			padding, outerEdge)
	);

	Board("Right Hand",
		MakeRow("Function Row",
			outerEdge, padding,
			Key{ 1, "R1" }, Key{ 1, "R2" },
			padding, Spacer{ Key{ 1 }.Width() - padding.Width() * 2 }, padding,
			Key{ 1, "F6" }, Key{ 1, "F7" }, Key{ 1, "F8" }, Key{ 1, "F9" }, Key{ 1, "F10" }, Key{ 1, "F11" }, Key{ 1, "F12" },
			padding, innerEdge, padding,
			Key{ 1, "PRINT" }, Key{ 1, "SCROLL" }, Key{ 1, "PAUSE" },
			padding, innerEdge, padding,
			Key{ 1, "N1" }, Key{ 1, "N2" }, Key{ 1, "N3" }, Key{ 1, "N4" },
			padding, innerEdge, padding,
			Key{ 1, "M1" },
			padding, outerEdge),
		MakeRow("Row 1",
			outerEdge, padding,
			Key{ 2, "R3" }, Key{ 1, "7" }, Key{ 1, "8" }, Key{ 1, "9" }, Key{ 1, "0" }, Key{ 1, "MINUS" }, Key{ 1, "EQUALS" }, Key{ 2, "BACKSPACE" },
			padding, innerEdge, padding,
			Key{ 1, "INSERT" }, Key{ 1, "HOME" }, Key{ 1, "PAGE_UP" },
			padding, innerEdge, padding,
			Key{ 1, "NUM_LOCK" }, Key{ 1, "NUM_DIV" }, Key{ 1, "NUM_MUL" }, Key{ 1, "NUM_MINUS" },
			padding, innerEdge, padding,
			Key{ 1, "M2" },
			padding, outerEdge),
		MakeRow("Row 2",
			outerEdge, padding,
			Key{ 1.5, "R4" }, Key{ 1, "Y" }, Key{ 1, "U" }, Key{ 1, "I" }, Key{ 1, "O" }, Key{ 1, "P" }, Key{ 1, "LEFT_BRACE" }, Key{ 1, "RIGHT_BRACE" }, Key{ 1.5, "BACKSLASH" },
			padding, innerEdge, padding,
			Key{ 1, "DELETE" }, Key{ 1, "END" }, Key{ 1, "PAGE_DOWN" },
			padding, innerEdge, padding,
			Key{ 1, "NUM_7" }, Key{ 1, "NUM_8" }, Key{ 1, "NUM_9" }, Key{ 1, "NUM_PLUS" },
			padding, innerEdge, padding,
			Key{ 1, "M3" },
			padding, outerEdge),
		MakeRow("Row 3",
			outerEdge, padding,
			Key{ 1.75, "R5" }, Key{ 1, "H" }, Key{ 1, "J" }, Key{ 1, "K" }, Key{ 1, "L" }, Key{ 1, "SEMICOLON" }, Key{ 1, "QUOTE" }, Key{ 2.25, "ENTER" },
			padding, Spacer{ innerEdge.Width() * 2 + Key{ 1 }.Width() * 3 + padding.Width() * 2 }, padding,
			Key{ 1, "NUM_4" }, Key{ 1, "NUM_5" }, Key{ 1, "NUM_6" }, Key{ 1, "NUM_PLUS(2)" },
			padding, innerEdge, padding,
			Key{ 1, "M4" },
			padding, outerEdge),
		MakeRow("Row 4",
			outerEdge, padding,
			Key{ 2.25, "R6" }, Key{ 1, "N" }, Key{ 1, "M" }, Key{ 1, "COMMA" }, Key{ 1, "PERIOD" }, Key{ 1, "FORWARD_SLASH" }, Key{ 2.75, "RIGHT_SHIFT" },
			padding, innerEdge, Spacer{ Key{ 1 }.Width() }, padding,
			Key{ 1, "UP" },
			padding, Spacer{ Key{ 1 }.Width() }, innerEdge, padding,
			Key{ 1, "NUM_1" }, Key{ 1, "NUM_2" }, Key{ 1, "NUM_3" }, Key{ 1, "NUM_ENTER" },
			padding, innerEdge, padding,
			Key{ 1, "M5" },
			padding, outerEdge),
		MakeRow("Row 5",
			outerEdge, padding,
			Key{ 1, "R7" }, Key{ 2.25, "RIGHT_SPACE" }, Key{ 1.75, "RIGHT_HYPER" }, Key{ 1.25, "RIGHT_ALT" }, Key{ 1.25, "RIGHT_WIN" }, Key{ 1.25, "RIGHT_MENU" }, Key{ 1.25, "RIGHT_CTRL" },
			padding, innerEdge, padding,
			Key{ 1, "LEFT" }, Key{ 1, "DOWN" }, Key{ 1, "RIGHT" },
			padding, innerEdge, padding,
			Key{ 2, "NUM_0" }, Key{ 1, "NUM_PERIOD" }, Key{ 1, "NUM_ENTER(2)" },
			padding, innerEdge, padding,
			Key{ 1, "M6" },
			padding, outerEdge)
	);

	return 0;
}

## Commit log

2015-12-08 Adding custom keyboard files.
    Adding mounting plate OpenSCAD files, PCB KiCAD files, and Arduino
    (Teensy) program.
    [.kicad_pcb.kicad_pcb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]
2017-11-24 Updating dxf exports to use blue lines.
    [Accessory.v2.dxf, LeftHand.v2.dxf, RightHand.v2.dxf]
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2017-11-25 Adding case parts for left hand board.
    [LeftHandBottom.scad, LeftHandBottom.stl, LeftHandLeft.scad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]
2017-11-26 Fixing lhr. Adding right hand/accessory case.
    [RightHandAndAccessoryBottom.scad, RightHandAndAccessoryBottom.stl, RightHandAndAccessoryLeft.scad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]
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2017-12-02 Adding more unit tests and fixed a couple bugs.
    [CustomKeyboard.cpp, MockArduino.cpp]
2017-12-10 Initial left hand v4 PCB.
    [LeftHandV4.kicad_pcb, LeftHandV4.sch]
2017-12-11 V4 base plates, initial controller PCB.
    [ControllerV4.kicad_pcb, ControllerV4.sch, LeftHandV4.kicad_pcb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]
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2017-12-12 Left Hand V4 PCB w/ stabilizers.
    [LeftHandV4.kicad_pcb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]
2017-12-13 Generating gerber files for LeftHand and Controller.
    [ControllerV4-B.Cu.gbl, ControllerV4-B.Mask.gbs, ControllerV4-B.SilkS.gbo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]
2017-12-14 Upgraded to latest KiCad, added RightHand PCB.
    [RightHandV4.kicad_pcb, RightHandV4.sch]
2017-12-14 Finished RightHandV4 board and Gerber exports.
    [RightHandV4-B.Cu.gbl, RightHandV4-B.Mask.gbs, RightHandV4-B.SilkS.gbo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]
2017-12-14 Working on face plates and mounting plates.
    [V4.scad]
2017-12-15 Finishing stabilizer cutouts. Adding connector art.
    [V4.dxf, V4.scad]
2018-01-05 Fixing a bug for the record books by adding delay(1).
    [CustomKeyboard.cpp]
2018-01-13 Layout, mounting plates, and faceplates for V5.
    [V5.dxf, V5.scad]
2018-01-14 Base plates for V5.
    [V5.dxf, V5.scad]
2018-01-14 V5 Left Hand PCB.
    [LeftHandV5-B.Cu.gbr, LeftHandV5-B.Mask.gbr, LeftHandV5-B.SilkS.gbr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]
2018-01-14 V5 Right Hand PCB.
    [RightHandV5-B.Cu.gbr, RightHandV5-B.Mask.gbr, RightHandV5-B.SilkS.gbr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]
2018-01-26 Adding missing F5 key.
    [CustomKeyboard.cpp]
2020-09-22 Fixing unsigned/int narrowing conversion warnings.
    [CustomKeyboard.cpp]
2021-05-21 Adding color to scad files.
    [V5.scad]
2021-05-21 Pushing updated DXF exports.
    [V5.dxf]
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2021-06-19 Adding readme and scad files for Mini V1.
    [basePlate.dxf, constants.scad, facePlate.dxf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]
2021-06-20 Fixing thumb 2-key faceplate cutout.
    [mini.scad]
2021-06-20 Moving DXF files to subdirectory. Fixing thumb screw errors. Adding hex/screw holes to layers.
    [basePlate.dxf, constants.scad, facePlate.dxf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]
2021-06-20 Adding rounded thumb-side bottom corner to wrist pad.
    [constants.scad, mini.scad]
2021-06-21 Refactoring to use finger column array.
    [constants.scad, mini.scad]
2021-06-21 Fixing connector positioning and finishing correct PCB layout (with PCB spacing test for verification).
    [constants.scad, mini.scad]
2021-06-21 Finishing stabilizers for mounting plate.
    [constants.scad, mini.scad]
2021-06-21 Removing pegs (probably not needed, fingers crossed). Adding 0.5mm padding to connector to prevent rub.
    [constants.scad, mini.scad]
2021-06-21 Re-exporting all layers after updates.
    [basePlate.dxf, facePlate.dxf, lowerLayer.dxf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]
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2021-06-23 Nothing will ever get done at home again.
    [constants.scad, mini.scad]
2021-06-23 Adding back peg holes (only 2 so far).
    [constants.scad, mini.scad]
2021-06-23 Adding remaining peg holes at key corners. Adding back in peg template.
    [constants.scad, mini.scad]
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2021-06-27 Playing with KiCad again.
    [Mini.kicad_pcb, Mini.sch]
2021-06-27 Setting up right hand PCB edge.
    [Mini.kicad_pcb]
2021-06-27 Adding schematics for demux, register, and dinn9. Adding all components to schematic.
    [Mini.sch]
2021-06-28 Adding R2L/L2R and 2key variants of key footprints.
    [Mini.sch]
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2021-06-28 Assigning footprints to R.H. schematic.
    [Mini.sch]
2021-06-28 Wiring up all pins on schematic.
    [Mini.sch]
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2021-06-28 Moving some 2-key holes around.
    [Mini.kicad_pcb]
2021-06-28 Adding extra 3mm to edge of thumb 2-keys to account for stabilizer holes on PCB.
    [constants.scad, mini.scad]
2021-06-28 Updating PCB to account for new 3mm thumb 2-key spacing.
    [Mini.kicad_pcb]
2021-06-29 Updating component footprints for proper silkscreen. Adding LED cutouts to PCB (except for 2-key).
    [Mini.kicad_pcb]
2021-06-29 Adding thumb 2-key LED cutout computation to SCAD and putting them in PCB.
    [Mini.kicad_pcb, mini.scad]
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2021-06-29 Moving gerber files to subdirectory. Renaming project files to RightHand (will also have LeftHand and Controller).
    [Mini-B_Cu.gbr, Mini-B_Mask.gbr, Mini-B_SilkS.gbr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]
2021-06-29 Whoops. Missed the untracked files.
    [RightHand-B_Cu.gbr, RightHand-B_Mask.gbr, RightHand-B_SilkS.gbr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]
2021-06-29 Adding initial LeftHand project (filled in schematic components).
    [LeftHand.kicad_pcb, LeftHand.sch]
2021-07-02 Wiring left hand schematic, adding footprints, and generating netlist.
    [LeftHand.sch]
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2021-07-02 Adding components to PCB. Fixing T2 footprints. Still need wiring and holes.
    [LeftHand.kicad_pcb, LeftHand.sch]
2021-07-03 Left hand edge cuts for LEDs and pegs.
    [LeftHand.kicad_pcb, RightHand.kicad_pcb, mini.scad]
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2021-07-07 Adding more colors but commenting out unused ones. Fixing comment warning.
    [CustomKeyboard.cpp]
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2021-07-09 Added test framework. Found a bug!
    [CustomKeyboard.cpp, MockArduino.cpp]
2021-07-09 Adding more tests. Found another bug!
    [CustomKeyboard.cpp]
2021-07-09 Adding more tests. Found another bug.
    [CustomKeyboard.cpp]
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2021-07-11 Fixing case when pressing layer keys in rapid succession where the previous layer key had keyCode modifiers applied.
    [CustomKeyboard.cpp]
2021-07-11 Fixing layer issue with rapid succession keys with the same keyCode.
    [CustomKeyboard.cpp]
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2021-08-10 Fixing tests broken when switching to microsecond delays.
    [MockArduino.cpp]
2021-08-12 Lowering the held threshold to improve erroneous layer shift key insertion on layer abort. Slower key presses may no longer register.
    [CustomKeyboard.cpp]
2021-08-13 Moving mini artifacts into V1 subfolder. Adding an initial V2 copy.
    [Controller-B_Cu.gbr, Controller-B_Mask.gbr, Controller-B_SilkS.gbr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]
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2021-08-13 Backporting controller fix to V1.
    [CustomKeyboard.cpp]
2021-08-13 Fixing controller lid/wall height, hex padding, connector notch, peg inner height.
    [constants.scad, mini.scad]
2021-08-13 Adding cutouts for dial inline chips in the mounting plate.
    [mini.scad]
2021-08-13 Adding connector notch padding back in. I will move the connector up 0.5mm on the PCB instead to correct the mistake.
    [mini.scad]
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2021-08-17 Updating V2 controller PCB to have 1mm holes for Teensy.
    [Controller-B_Cu.gbr, Controller-B_Mask.gbr, Controller-B_SilkS.gbr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]
2021-08-17 Updating LH PCB register to read 01 for register[4..5] and RH to read 10. V1 will read as 00 for controller logic backward compatibility.
    [LeftHand.kicad_pcb, LeftHand.sch, RightHand.kicad_pcb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]
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2021-08-17 Starting to update LH LED footprints. Shrank keyswitch cutout per bug checking. Still working.
    [LeftHand.kicad_pcb]
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2021-08-19 Fixing some more wires.
    [LeftHand.kicad_pcb]
2021-08-19 Adding a failing test for rapid unshift (still need to fix the controller to handle this case).
2021-08-19 Fixing dead layer key controller issue. Also fixed second SHIFT report from layer 5.
    [CustomKeyboard.cpp]
2021-08-20 Finished fixing LED hole wiring adjustments.
    [LeftHand.kicad_pcb]
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2021-08-20 Fixing peg holes to be slightly wider (0.2mm on each side).
    [LeftHand.kicad_pcb]
2021-08-20 Fixing wiring from peg hole increase. Regenerating gerber files for left hand.
    [LeftHand-B_Cu.gbr, LeftHand-B_Mask.gbr, LeftHand-B_SilkS.gbr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]
2021-08-20 Making all PCB adjustments to the right hand and regenerating gerber files.
    [RightHand-B_Cu.gbr, RightHand-B_Mask.gbr, RightHand-B_SilkS.gbr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]
2021-08-20 Adding tests for V1 backwards compatibility and V2 inverted hands.
    [MockArduino.cpp]
2021-08-20 Handling hardware being inverted. Not handling stupid permutations (two left hands, etc.) specially. LED output will follow most recent hand inversion reading.
    [CustomKeyboard.cpp]
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2021-09-01 Whoops. Must have inverted the hardware wiring for the sides.
    [CustomKeyboard.cpp, MockArduino.cpp]
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2021-09-24 Starting to add more color modes. Have an 8-bit overflow issue.
    [CustomKeyboard.cpp]
2021-12-15 Adding test for stupid lambda semicolon issue and fixing it.
    [CustomKeyboard.cpp]
2022-01-29 Adding test for rapid number transition while still holding layer 0 keys (took me a while for my typing speed to get fast enough to find this bug).
    [CustomKeyboard.cpp]
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2024-02-04 Adding bent bottom row.
    [constants.scad, mini.scad]
2024-02-04 Whoops to some naming issues after debugging.
    [constants.scad, mini.scad]
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2024-02-05 Fixing top/bottom inversion.
    [mini.scad]
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2024-02-08 Starting to add bottom row wall. Join is not perfect - need to diagnose.
    [constants.scad, mini.scad]
2024-02-10 Fixed pinky lower row wall.
    [constants.scad, mini.scad]
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2024-02-10 Bottom row index finger wall. Bottom row wall done.
    [constants.scad, mini.scad]
2024-02-10 Adding pinky plus one column. May need to rework mounting place spacing between keys.
    [constants.scad, mini.scad]
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2024-02-14 Got pinky near vertical wall figured out. Next up: subtracting ring finger far vertical wall.
    [mini.scad]
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2024-02-16 Adding PCB toggle and TODO for wall issue.
    [mini.scad]
